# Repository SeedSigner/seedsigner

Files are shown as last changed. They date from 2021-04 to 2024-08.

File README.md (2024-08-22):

# Build an offline, airgapped Bitcoin signing device for less than $50!

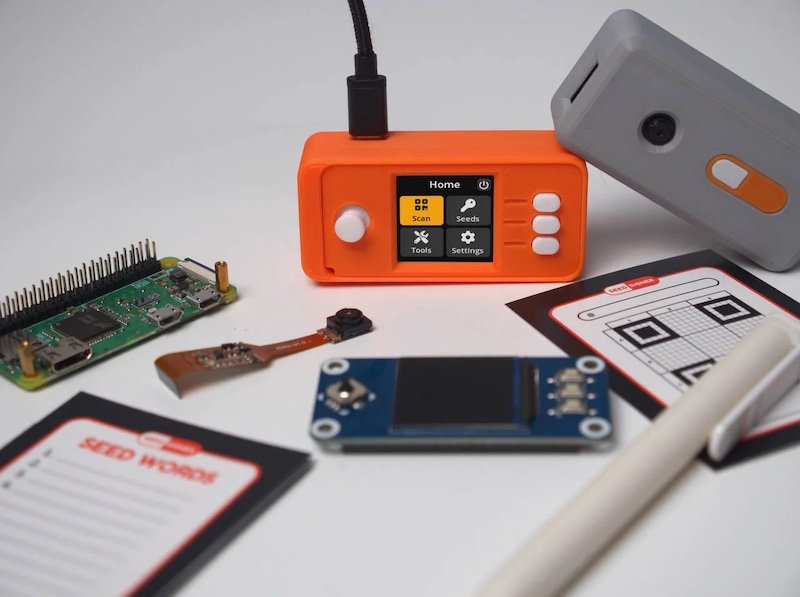
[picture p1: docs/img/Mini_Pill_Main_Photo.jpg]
Image of SeedSigners in Mini Pill Enclosures


---------------

* [Project Summary](#project-summary)
* [Shopping List](#shopping-list)
* [Software Installation](#software-installation)
  * [Verifying the Software](#verifying-the-software)
* [Enclosure Designs](#enclosure-designs)
* [SeedQR Printable Templates](#seedqr-printable-templates)
* [Build from Source](#build-from-source)
* [Developer Local Build Instructions](#developer-local-build-instructions)

---------------

# Project Summary




The goal of SeedSigner is to lower the cost and complexity of Bitcoin multi-signature wallet use. To accomplish this goal, SeedSigner offers anyone the opportunity to build a verifiably air-gapped, stateless Bitcoin signing device using inexpensive, publicly available hardware components (usually < $50). SeedSigner helps users save with Bitcoin by assisting with trustless private key generation and multisignature (aka "multisig") wallet setup, and helps users transact with Bitcoin via a secure, air-gapped QR-exchange signing model.

Additional information about the project can be found at [SeedSigner.com](https://seedsigner.com).

You can follow [@SeedSigner](https://twitter.com/SeedSigner) on Twitter for the latest project news and developments.

If you have specific questions about the project, our [Telegram Group](https://t.me/joinchat/GHNuc_nhNQjLPWsS) is a great place to ask them.

### Feature Highlights:
* Calculate the final word (aka checksum) of a 12- or 24-word BIP39 seed phrase
* Create a 24-word BIP39 seed phrase with 99 dice rolls or a 12-word with 50 rolls [(Verifying dice seed generation)](docs/dice_verification.md)
* Create a 12- or 24-word BIP39 seed phrase via image entropy from the onboard camera 
* Temporarily stores seeds in memory while the device is powered; all memory is wiped when power is removed
* SD card removable after boot to ensure no secret data can be written to it
* Guided interface to manually transcribe a seed to the SeedQR format for instant seed loading [(demo video here)](https://youtu.be/c1-PqTNx1vc)
* BIP39 passphrase (aka "word 25") support
* Native Segwit Multisig XPUB generation
* PSBT-compliant; scan and parse transaction data from animated QR codes
* Sign transactions & transfer XPUB data using animated QR codes [(demo video here)](https://youtu.be/LPqvdQ2gSzs)
* Live preview during image entropy seed generation and QR scanning UX
* Optimized seed word entry interface
* Support for Bitcoin Mainnet & Testnet
* Support for custom user-defined derivation paths
* Support for loading Electrum Segwit seed phrases with feature limitations: [Electrum support info](docs/electrum.md)
* On-demand receive address verification
* Address Explorer for single sig and multisig wallets
* User-configurable QR code display density
* Responsive, event-driven user interface

### Considerations:
* Built for compatibility with Specter Desktop, Sparrow, and BlueWallet Vaults
* Device takes up to 60 seconds to boot before menu appears (be patient!)
* Always test your setup before transferring larger amounts of bitcoin (try Testnet first!)
* Taproot not quite yet supported
* Slightly rotating the screen clockwise or counter-clockwise should resolve lighting/glare issues
* If you think SeedSigner adds value to the Bitcoin ecosystem, please help us spread the word! (tweets, pics, videos, etc.)

### Planned Upcoming Improvements / Functionality:
* Multi-language support
* Significantly faster boot time
* Reproducible builds
* Port to MicroPython to broaden the range of compatible hardware to include low-cost microcontrollers
* Other optimizations based on user feedback!

---------------

# Shopping List

To build a SeedSigner, you will need:

* Raspberry Pi Zero (preferably version 1.3 with no WiFi/Bluetooth capability, but any Raspberry Pi 2/3/4 or Zero model will work, Raspberry Pi 1 devices will require a hardware modification to the Waveshare LCD Hat, as per the [instructions here](./docs/legacy_hardware.md))
* Waveshare 1.3" 240x240 pxl LCD (correct pixel count is important, more info at https://www.waveshare.com/wiki/1.3inch_LCD_HAT)
* Pi Zero-compatible camera (tested to work with the Aokin / AuviPal 5MP 1080p with OV5647 Sensor)

Notes:
* You will need to solder the 40 GPIO pins (20 pins per row) to the Raspberry Pi Zero board. If you don't want to solder, purchase "GPIO Hammer Headers" for a solderless experience.
* Other cameras with the above sensor module should work, but may not fit in the Orange Pill enclosure
* Choose the Waveshare screen carefully; make sure to purchase the model that has a resolution of 240x240 pixels

---------------

# Software Installation

## A Special Note On Minimizing Trust
As is the nature of pre-packaged software downloads, downloading and using the prepared SeedSigner release images means implicitly placing trust in the people preparing those images; in our project the released images are prepared and signed by the eponymous creator of the project, SeedSigner "the person". That individual is additionally the only person in possession of the PGP keys that are used to sign the release images.

Starting with v0.7.0, the images distributed via GitHub are reproducible. This means you and others can verify the released images are byte-for-byte the same when built from source. You can contribute to this project by building from source and sharing the hash of the final images.

Instructions to build a SeedSigner OS image (using precisely the same process that is used to create the prepared release images) have been made available. We have put a lot of thought and work into making these instructions easy to understand and follow, even for less technical users. These instructions can be found [here](https://github.com/SeedSigner/seedsigner-os/blob/main/docs/building.md).

## Downloading the Software

Download the current Version (0.8.0) software image that is compatible with your  Raspberry Pi Hardware. The Pi Zero 1.3 is the most common and recommended board.
| Board | Download Image Link/Name |
| --- | --- |
|**[Raspberry Pi Zero 1.3](https://www.raspberrypi.com/products/raspberry-pi-zero/)** |[`seedsigner_os.0.8.0.pi0.img`](https://github.com/SeedSigner/seedsigner/releases/download/0.8.0/seedsigner_os.0.8.0.pi0.img) |
|[Raspberry Pi Zero W](https://www.raspberrypi.com/products/raspberry-pi-zero-w/) |[`seedsigner_os.0.8.0.pi0.img`](https://github.com/SeedSigner/seedsigner/releases/download/0.8.0/seedsigner_os.0.8.0.pi0.img) |
|[Raspberry Pi Zero 2 W](https://www.raspberrypi.com/products/raspberry-pi-zero-2-w/)  |[`seedsigner_os.0.8.0.pi02w.img`](https://github.com/SeedSigner/seedsigner/releases/download/0.8.0/seedsigner_os.0.8.0.pi02w.img) |
|[Raspberry Pi 1 Model B/B+](https://www.raspberrypi.com/products/raspberry-pi-1-model-b-plus/) |[`seedsigner_os.0.8.0.pi0.img`](https://github.com/SeedSigner/seedsigner/releases/download/0.8.0/seedsigner_os.0.8.0.pi0.img) |
|[Raspberry Pi 2 Model B](https://www.raspberrypi.com/products/raspberry-pi-2-model-b/) |[`seedsigner_os.0.8.0.pi2.img`](https://github.com/SeedSigner/seedsigner/releases/download/0.8.0/seedsigner_os.0.8.0.pi2.img) |
|[Raspberry Pi 3 Model B](https://www.raspberrypi.com/products/raspberry-pi-3-model-b/) |[`seedsigner_os.0.8.0.pi02w.img`](https://github.com/SeedSigner/seedsigner/releases/download/0.8.0/seedsigner_os.0.8.0.pi02w.img) |
|[Raspberry Pi 4 Model B](https://www.raspberrypi.com/products/raspberry-pi-4-model-b/) |[`seedsigner_os.0.8.0.pi4.img`](https://github.com/SeedSigner/seedsigner/releases/download/0.8.0/seedsigner_os.0.8.0.pi4.img) |
|[Raspberry Pi 400](https://www.raspberrypi.com/products/raspberry-pi-400-unit/) |[`seedsigner_os.0.8.0.pi4.img`](https://github.com/SeedSigner/seedsigner/releases/download/0.8.0/seedsigner_os.0.8.0.pi4.img) |

Note: If you have physically removed the WiFi component from your board, you will still use the image file of the original(un-modified) hardware. (Our files are compiled/based on the *processor* architecture). Although it is better to spend a few minutes upfront to determine which specific Pi hardware/model you have, if you are still unsure which hardware you have, you can try using the pi0.img file. Making an incorrect choice here will not ruin your board, because this is software, not firmware. 

**also download** these 2 signature verification files to the same folder  
[The Plaintext manifest file](https://github.com/SeedSigner/seedsigner/releases/download/0.8.0/seedsigner.0.8.0.sha256.txt)  
[The Signature of the manifest file](https://github.com/SeedSigner/seedsigner/releases/download/0.8.0/seedsigner.0.8.0.sha256.txt.sig)

Users familiar with older versions of the SeedSigner software might be surprised with how fast their software downloads now are, because since version 0.6.0 the software image files are now 100x smaller! Each image file is now under 42 Megabytes so your downloads and verifications will be very quick now (and might even seem *too* quick)!  

Once the files have all finished downloading, follow the steps below to verify the download before continuing on to write the software onto a MicroSD card. Next, insert the MicroSD into your assembled hardware and connect the USB power. Allow about 45 seconds for our logo to appear, and then you can begin using your SeedSigner! 

[Our previous software versions are available here](https://github.com/SeedSigner/seedsigner/releases). Choose a specific version and then expand the *Assets* sub-heading to display the .img file binary and also the 2 associated signature files. **Note:** The prior version files will have lower numbers than the scripts and examples provided in this document, but the naming format will be the same, so you can edit them as required for signature verification etc.   

## Verifying that the downloaded files are authentic (optional but highly recommended!)

You can quickly verify that the software you just downloaded is both authentic and unaltered, by following these instructions.
We assume you are running the commands from a computer where both [GPG](https://gnupg.org/download/index.html) and [shasum](https://command-not-found.com/shasum) are already installed, and that you also know [how to navigate on a terminal](https://terminalcheatsheet.com/guides/navigate-terminal). 

> You must run the following verification before opening or mounting the .img file.
> Some operating systems modify the file on mount causing verification to fail.

### Step 1. Verify that the signature (.sig) file is genuine:

Run GPG's *fetch-keys* command to import the SeedSigner projects public key from the popular online keyserver called *Keybase.io*, into your computers *keychain*. 

```
gpg --fetch-keys https://keybase.io/seedsigner/pgp_keys.asc
```
The result should confirm that 1 key was *either* imported or updated. *Ignore* any key ID's or email addresses shown.

SS - Fetchkeys-Keybase PubKey import with Fingerprint shown (New import or update of the key)v3-100pct  

Next, you will run the *verify* command on the signature (.sig) file. (*Verify* must be run from inside the same folder that you downloaded the files into earlier. The `*`'s in this command will auto-fill the version from your current folder, so it should be copied and pasted as-is.)   
```
gpg --verify seedsigner.0.7.*.sha256.txt.sig
```

When the verify command completes successfully, it should display output like this:
<BR>
SS - Verify Command - GPG on Linux - Masked_v4-100pct  
The result must display "**Good signature**".  Ignore any email addresses - *only*  matching Key fingerprints count here. Stop immediately if it displays "*Bad signature*"!
<BR> 

On the *last* output line, look at your *rightmost* 16 characters (the 4 blocks of 4).  
**Crucially, we must now check WHO that Primary key fingerprint /ID belongs to.** We will start by looking at Keybase.io to see if it is the *SeedSigner project* 's public key or not.

<details><summary> About the warning message:</summary>
<p>  Since you are about to match the outputted fingerprint/ID against the proofs at Keybase.io/SeedSigner, and thereby confirm who the pubkey really belongs to-, you can safely ignore this warning message:

```
> WARNING: This key is not certified with a trusted signature!  
> There is no indication that the signature belongs to the owner.
 ```
</p>
</details>
<br>

<details><summary> More about how the verify command works:</summary>
<p>  
The verify command will attempt to decrypt the signature file (sha256.sig) by trying each public key already imported into your computer. If the public key we just imported (via fetch-keys), manages to: (a) successfully decrypt the .sig file , and (b), that result matches exactly to the clear-text equivalent (.sha256) of the .sig file, then its "a good signature"!   

Crucially, we must still manually check who *exactly* owns the Key ID which gave us that "Good signature". Thats what the warning message means- Who does the matching key really belong to? We will start by looking at keybase.io to see if it is "The SeedSigner project"'s public Key or not. 
Note that it is the file hashes of .sig and .sha256 that *verify* compares, not their raw contents.

</p>
</details>
<br>

Now to determine ***who*** the Public key ID belongs to: Goto [Keybase.io/SeedSigner](https://keybase.io/seedsigner)  
<BR>
SS - Keybase Website PubKey visual matching1_Cropped-80pct

**You must now *manually* compare: The 16 character fingerprint ID (as circled in red above) to, those *rightmost* 16 characters from your *verify* command.** 

**If they match exactly, then you have successfully confirmed that your .sig file is authentically from the SeedSigner Project!**
<BR>

<details><summary>Learn more about how keybase.io helps you check that someone (online) is who they say they are:</summary>
<p>
Keybase.io allows you to independently verify that the public key saved on Keybase.io, is both authentic and that it belongs to the organization it claims to represent.  
 Keybase has already checked the three pubkey file locations  cryptographically when they were saved there. You can further verify the key publications if you would like:  
 
 - *via Keybase*: By clicking on any of the three blue badges to see that the "proof" was published at that location. (The blue badge marked as tweet, is in the most human-readable form and it is also a bi-directional link on Twitter)    
or, 
 - *without keybase (out-of-band)*: By using these 3 links directly: [Twitter](https://twitter.com/SeedSigner/status/1530555252373704707), [Github](https://gist.github.com/SeedSigner/5936fa1219b07e28a3672385b605b5d2) and [SeedSigner.com](https://seedsigner.com/keybase.txt). This method can be used if you would like to make an even deeper, independent inspection without relying on Keybase at all, or if the Keybase.io site is no longer valid or it is removed entirely. 

Once you have used one of these methods, you will know if the Public Key stored on Keybase, is genuinely from the SeedSinger Project or not.
</p>
</details>
<br>

If the two ID's do *not* match, then you must stop here immediately. Do not continue. Contact us for assistance in the Telegram group address above.

<br>

### Step 2. Verifying that the *software images/binaries* are genuine

Now that you have confirmed that you do have the real SeedSigner Project's Public Key (ie the 16 characters match) - you can return to your terminal window. Running  the *shasum* command, is the final verification step and will confirm (via file hashing) that the software code/image files, were also not altered since publication, or even during your download process.  
(Prior to version 0.6.0  , your verify command will check the .zip file which contains the binary files.)

 **On Linux or OSX:** Run this command
```
shasum -a 256 --ignore-missing --check seedsigner.0.7.*.sha256.txt  
```

**On Windows (inside Powershell):** Run this command
```
CertUtil -hashfile  seedsigner_os.0.8.0.Insert_Your_Pi_Models_binary_here_For_Example_pi02w.img SHA256 
```
On Windows, you must then manually compare the resulting file hash value to the corresponding hash value shown inside the .SHA256 cleartext file.
 <BR>

Wait up to 30 seconds for the command to complete, and it should display:
```
seedsigner_os.0.7.x.[Your_Pi_Model_For_Example:pi02w].img: OK
```
**If you receive the "OK" message** for your **seedsigner_os.0.7.x.[Your_Pi_Model_For_Example:pi02w].img file**, as shown above, then your verification is fully complete!  
**All of your downloaded files have now been confirmed as both authentic and unaltered!** You can proceed to create/write your MicroSD card😄😄 !!     

If your file result shows "FAILED", then you must stop here immediately. Do not continue. Contact us for assistance at  the Telegram group address above.

<BR>

Please recognize that this process can only validate the software to the extent that the entity that first published the key is an honest actor, and their private key is not compromised or somehow being used by a malicious actor.
<BR>
<BR>

## Writing the software onto your MicroSD card

To write the SeedSigner software onto your MicroSD card, there are a few options available:   
| Application | Description | Platform and official Source |
|---|---|---|
| Balena Etcher | The application is called Etcher, and the company that wrote it is called Balena.  Hence *Etcher by Balena* or *Balena Etcher* | [Available for Windows, Mac and Linux](https://www.balena.io/etcher#download-etcher) |
| Raspberry Pi Imager | Produced by the Raspberry Pi organization. | [Available for Windows, Mac and Linux](https://www.raspberrypi.com/software/) |
| DD Command Line Utility  | Built-in to Linux and MacOS, the DD (Data Duplicator) is a tool for advanced users.  If not used carefully it can accidentally format the incorrect disk! | Built-in to Linux and MacOS |

Be sure to download the software from the genuine publisher.  
Either of the Etcher or Pi Imager software is recommended.  Some SeedSigner users have reported a better experience with one or the other. So, if the one application doesn’t work well for your particular machine, then please try the other one. 
<BR>
### **General Considerations:** 
The writing and verify steps are very quick from version 0.6.0 upwards, so please pay close attention to your screen. 
Make sure to set any write-protection physical slider on the MicroSD Card Adapter to UN-locked.  
You also don’t need to pre-format the MicroSD beforehand.  You *dont* need to unzip any .zip file beforehand.
Current Etcher and Pi Imager software will perform a verify action (by default) to make sure the card was written successfully! Watching for that verify step to complete successfully, can save you a lot of headaches if you later need to troubleshoot issues where your SeedSigner device doesn’t boot up at power on.   
Writing the MicroSd card is also known as flashing.  
It will overwrite everything on the MicroSD card.  
If the one application fails for you, then please try again using our other recommended application.  
Advanced users may want to try the Linux/MacOS *DD* command instead of using Etcher or Pi Imager, however, a reminder is given that DD can overwrite the wrong disk if you are not careful !
#### **Specific considerations for Windows users:**
Use the Pi imager software as your first choice on Windows. Windows can sometimes flag the writing of a MicroSD as risky behaviour and hence it may prevent this activity. If this happens, your writing/flashing will fail, hang or wont even begin, in which case you should to try to run the Etcher/Pi-Imager app "As administrator", (right-click and choose that option). It can also be blocked by windows security in some cases, so If you have the (non-default) *Controlled Folder Access* option set to active, try turning that *off* temporarily. 

---------------

# Enclosure Designs

### Open Pill

The Open Pill enclosure design is all about quick, simple and inexpensive depoloyment of a SeedSigner device. The design does not require any additional hardware and can be printed using a standard FDM 3D printer in about 2 hours, no supports necessary. A video demonstrating the assembly process can be found [here](https://youtu.be/gXPFJygZobEa). To access the design file and printable model, click [here](https://github.com/SeedSigner/seedsigner/tree/main/enclosures/open_pill).

### Orange Pill

The Orange Pill enclosure design offers a more finished look that includes button covers and a joystick topper. You'll also need the following additional hardware to assemble it:

* 4 x F-F M2.5 spacers, 10mm length
* 4 x M2.5 pan head screws, 6mm length
* 4 x M2.5 pan head screws, 12mm length

The upper and lower portions of the enclosure can be printed using a standard FDM 3D printer, no supports necessary. The buttons and joystick nub should ideally be produced with a SLA/resin printer. An overview of the entire assembly process can be found [here](https://youtu.be/aIIc2DiZYcI). To access the design files and printable models, click [here](https://github.com/SeedSigner/seedsigner/tree/main/enclosures/orange_pill).

### Community Designs

* [Lil Pill](https://cults3d.com/en/3d-model/gadget/lil-pill-seedsigner-case) by @_CyberNomad
* [OrangeSurf Case](https://github.com/orangesurf/orangesurf-seedsigner-case) by @OrangeSurfBTC
* [PS4 SeedSigner](https://www.thingiverse.com/thing:5363525) by @Silexperience
* [OpenPill Faceplate](https://www.printables.com/en/model/179924-seedsigner-open-pill-cover-plates-digital-cross-jo) by @Revetuzo 
* [Waveshare CoverPlate](https://cults3d.com/en/3d-model/various/seedsigner-coverplate-for-waveshare-1-3-inch-lcd-hat-with-240x240-pixel-display) by @Adathome1

---------------

# SeedQR Printable Templates
You can use SeedSigner to export your seed to a hand-transcribed SeedQR format that enables you to instantly load your seed back into SeedSigner.

[More information about SeedQRs](docs/seed_qr/README.md)

<table align="center">
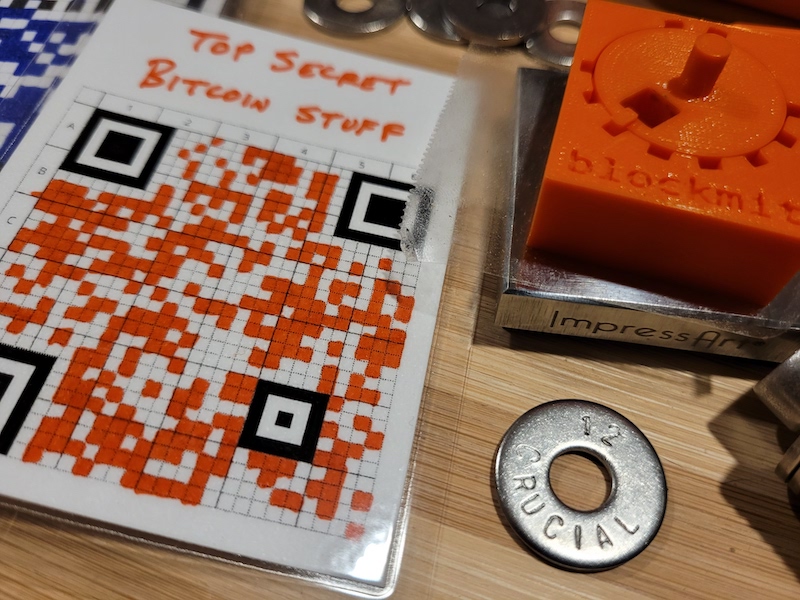
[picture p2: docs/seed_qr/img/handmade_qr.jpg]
    <tr><td></td></tr>
</table>

Standard SeedQR templates:
* [12-word SeedQR template dots (25x25)](docs/seed_qr/printable_templates/dots_25x25.pdf)
* [24-word SeedQR template dots (29x29)](docs/seed_qr/printable_templates/dots_29x29.pdf)
* [12-word SeedQR template grid (25x25)](docs/seed_qr/printable_templates/grid_25x25.pdf)
* [24-word SeedQR template grid (29x29)](docs/seed_qr/printable_templates/grid_29x29.pdf)
* [Baseball card template: 24-word SeedQR (29x29)](docs/seed_qr/printable_templates/trading_card_29x29_w24words.pdf)

CompactSeedQR templates:
* [12-word CompactSeedQR template dots (21x21)](docs/seed_qr/printable_templates/dots_21x21.pdf)
* [24-word CompactSeedQR template dots (25x25)](docs/seed_qr/printable_templates/dots_25x25.pdf)
* [12-word CompactSeedQR template grid (21x21)](docs/seed_qr/printable_templates/grid_21x21.pdf)
* [24-word CompactSeedQR template grid (25x25)](docs/seed_qr/printable_templates/grid_25x25.pdf)
* [Baseball card template: 12-word Compact SeedQR (21x21)](docs/seed_qr/printable_templates/trading_card_21x21_w12words.pdf)
* [Baseball card template: 24-word Compact SeedQR (25x25)](docs/seed_qr/printable_templates/trading_card_25x25_w24words.pdf)

2-sided SeedQR templates - 8 per sheet
Printing settings - (2-sided)("flip on long edge")("Actual Size")
If printing on cardstock, adjust your printer settings via its control panel

A4 templates(210mm * 297mm):
* [21x21 - stores 12-word seeds ONLY in CompactSeedQR format ONLY](docs/seed_qr/printable_templates/21x21_A4_trading_card_2sided.pdf)
* [25x25 - stores 12-word or 24 word seeds depending on SeedQR format](docs/seed_qr/printable_templates/25x25_A4_trading_card_2sided.pdf)
* [29x29 - stores 24-word seeds ONLY as plaintext SeedQR format ONLY](docs/seed_qr/printable_templates/29x29_A4_trading_card_2sided.pdf)

Letter templates(8.5in * 11in):
* [21x21 - stores 12-word seeds ONLY in CompactSeedQR format ONLY](docs/seed_qr/printable_templates/21x21_letter_trading_card_2sided.pdf)
* [25x25 - stores 12-word or 24 word seeds depending on format](docs/seed_qr/printable_templates/25x25_letter_trading_card_2sided.pdf)
* [29x29 - stores 24-word seeds ONLY as plaintext SeedQR format ONLY](docs/seed_qr/printable_templates/29x29_letter_trading_card_2sided.pdf)
---------------

# Build from Source
See the [SeedSigner OS repo](https://github.com/SeedSigner/seedsigner-os/) for instructions.

# Developer Local Build Instructions
Raspberry Pi OS is commonly used for development. See the [Raspberry Pi OS Build Instructions](docs/raspberry_pi_os_build_instructions.md)

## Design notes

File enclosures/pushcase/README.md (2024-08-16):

# The Push Case

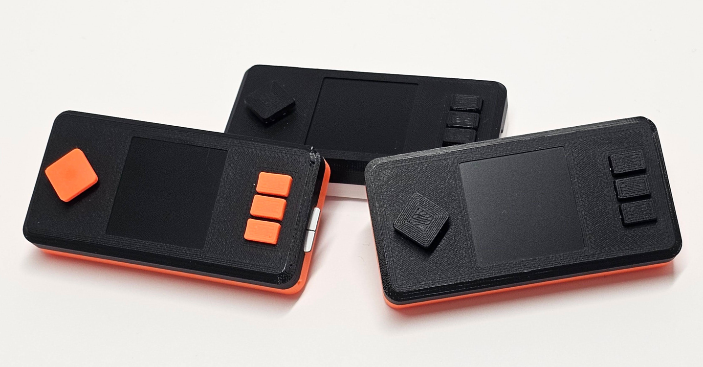
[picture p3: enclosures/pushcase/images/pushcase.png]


Designer: @kayth21

## Motivation

The motivation for this design was to get a thin, screwless and good looking enclosure with minimal secondary hardware requirements.

## Characterisics

- No screws needed
- Soldering required
- Mini-HDMI port not accessible
- Removeable memory card accessible
- Data-enabled USB port not accessible

## Hardware restrictions

- Raspberry Pi Zero without pre-installed GPIO pins required.
- Raspberry Pi Camera in smaller "Zero" style version required.

## Secondary hardware requirements

- 40x pins (6mm / 0.04in)
- Soldering iron and solder

## 3D prints and screwless design

Please note that the prints must be accurate in order to fit tightly without screws and for the buttons to perform smoothly. The prints are well tested with a Prusa MK3s (.3mf files attached), Prusament PLA and hardware components from early 2024. With this setup, the enclosure holds strongly together, but can still be opened again with a little effort (although this is not recommended, as it may not hold together as tightly afterwards). Other printers or newer or older hardware may produce results that do not fit and in worst case damage the hardware.

## Known issues

- Bambu Studio Slicer: There is a strange problem when slicing the buttons. A few layers are missing. As a workaround you can use another slicer, e.g. the Prusa Slicer.

## Assembly

### 1. Get all the parts

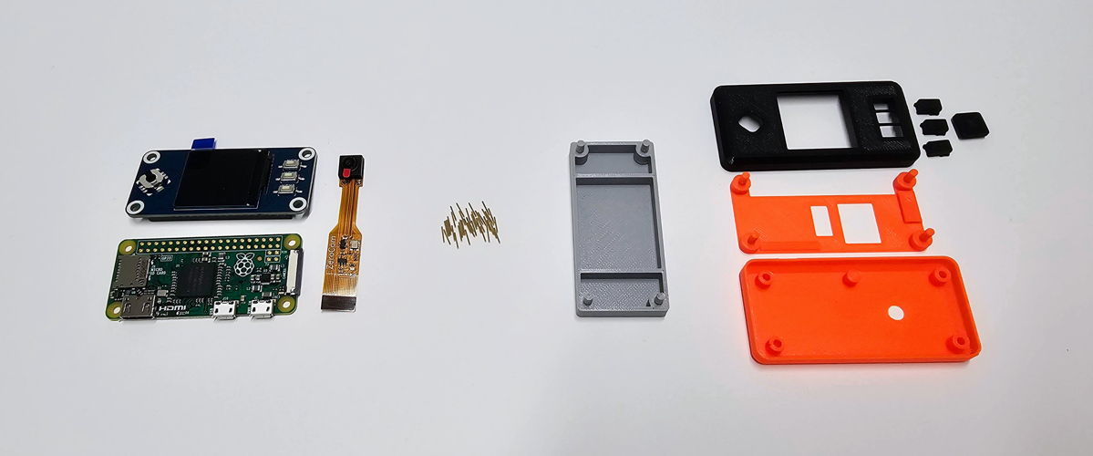
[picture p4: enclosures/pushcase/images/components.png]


- Raspberry Pi Zero v.1.3
- Waveshare LCD Display (240x240)
- Camera for Raspberry Pi Zero
- 40 pins (6mm / 0.04in, cut them to size if you can only find larger ones)
- Soldering iron and solder (not on picture)
- Soldering support (3D print)
- Top, middle, back and buttons (3D prints)
- Tweezers (if available - not on picture)

### 2. Place the display and the Raspberry Pi on the soldering support

<p float="left">
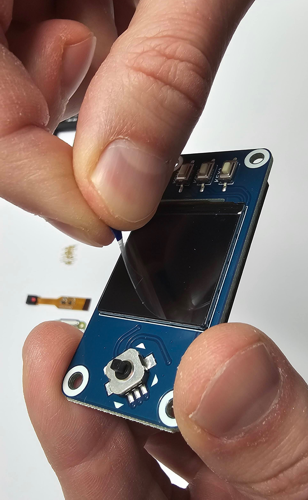
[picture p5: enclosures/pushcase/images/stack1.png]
	
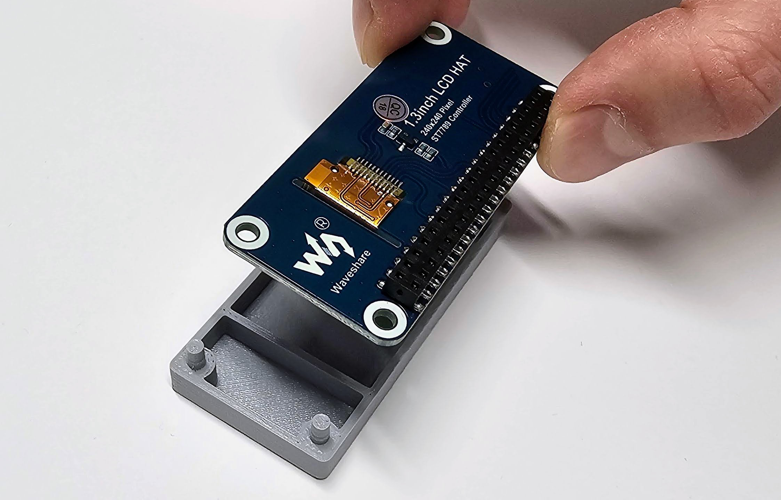
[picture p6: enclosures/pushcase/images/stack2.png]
	
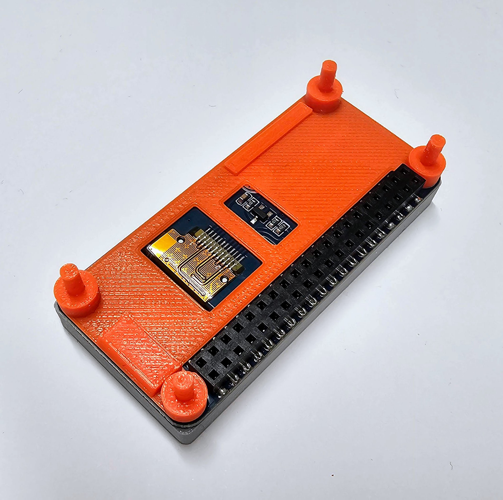
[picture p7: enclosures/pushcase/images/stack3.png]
	
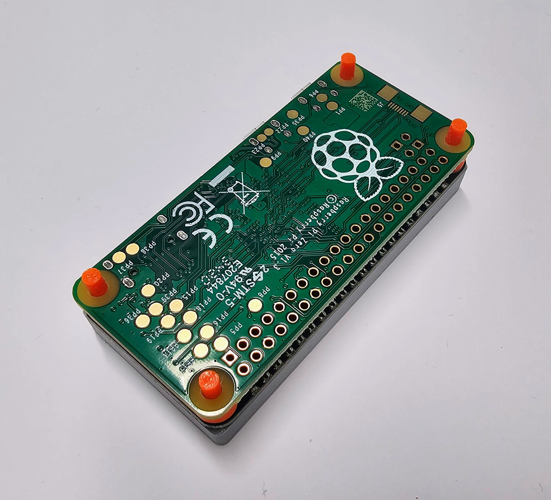
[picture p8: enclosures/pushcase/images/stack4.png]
	
</p>

- Remove the screen protection of the LCD display.
- Place the display face down on the soldering support.
- Place the middle support on the display.
- Place the Raspberry Pi face down on the middle support.

### 3. Solder the pins

<p float="left">
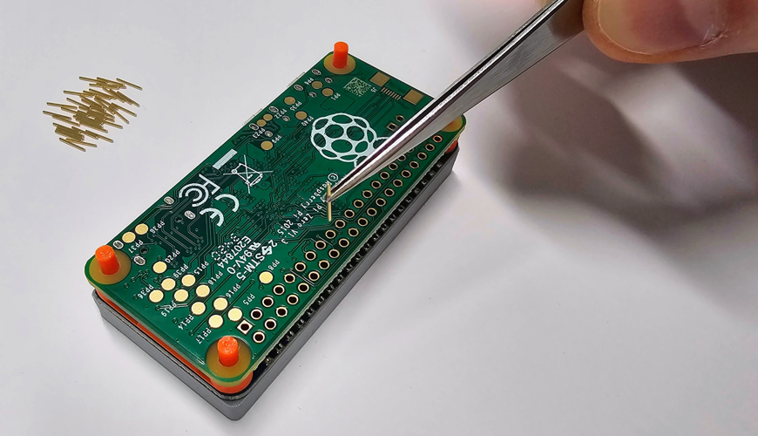
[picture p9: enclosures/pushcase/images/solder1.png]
	
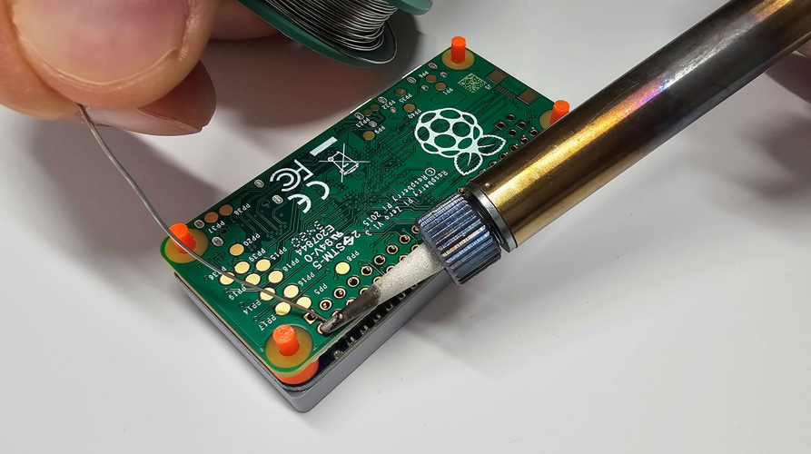
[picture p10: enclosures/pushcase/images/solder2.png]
	
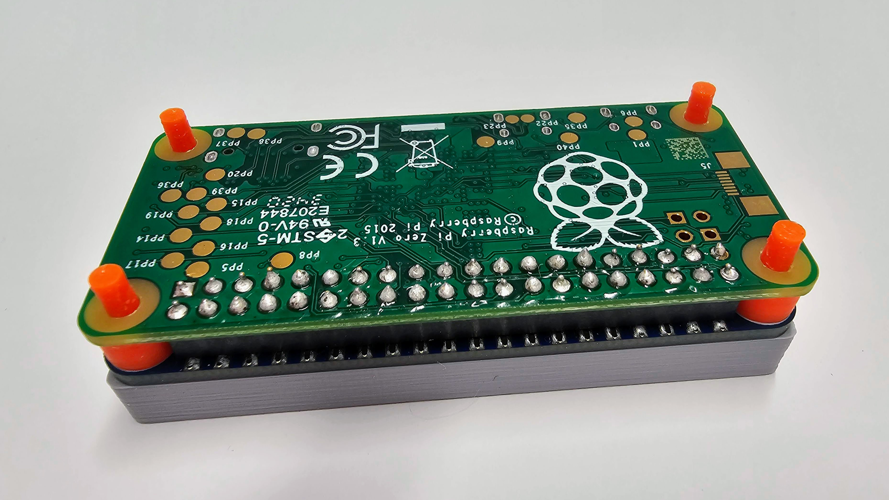
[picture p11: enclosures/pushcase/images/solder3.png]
	
</p>

- Insert the 40 pins with the help of tweezers and push them all the way down.
- Solder the pins (please pay attention not to melt the orange support elements!).
- Optional: Pull out the Raspberry Pi to check that the pins are holding properly after soldering. 

### 4. Attach camera

<p float="left">
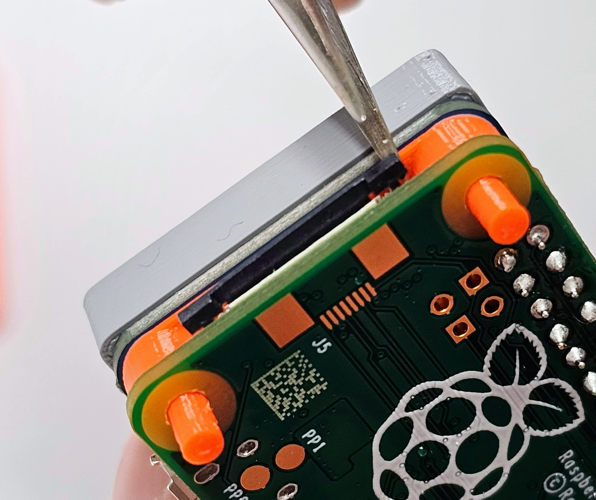
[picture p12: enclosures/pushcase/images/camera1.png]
	
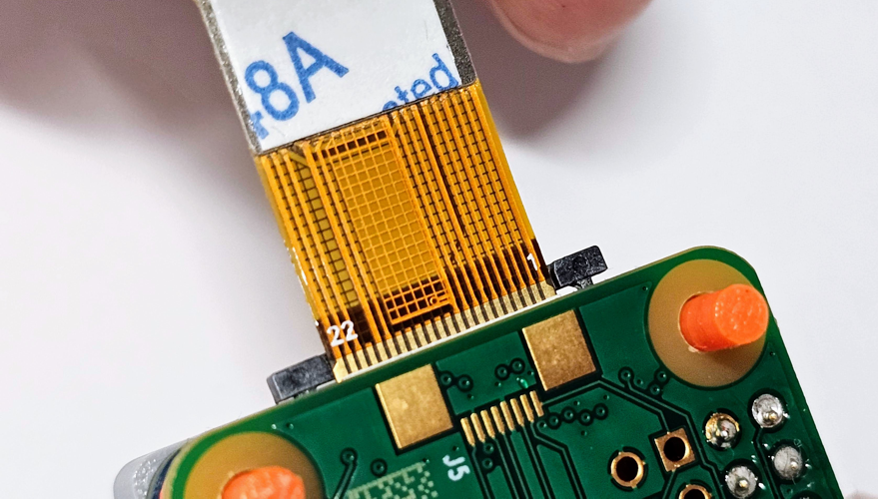
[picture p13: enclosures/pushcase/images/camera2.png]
	
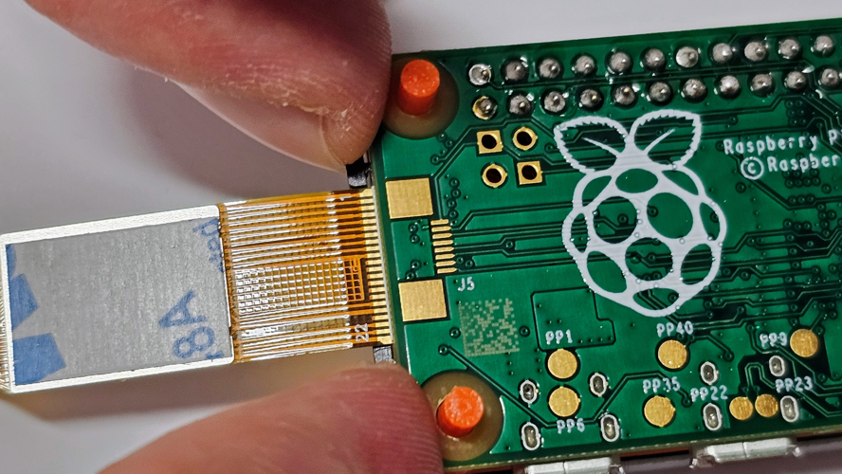
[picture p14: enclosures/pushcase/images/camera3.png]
	
</p>

- Carefully pull out the camera cable mount (ideally with the support of a tool).
- Plug in the camera cable (it doesn't go very deep).
- Close the camera cable mount to fix the cable.

### 5. Stick on the back part

<p float="left">
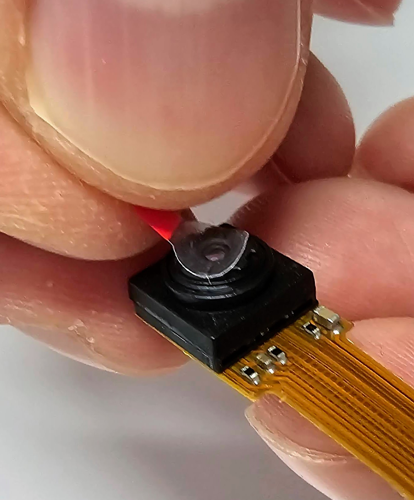
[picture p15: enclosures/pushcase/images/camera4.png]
	
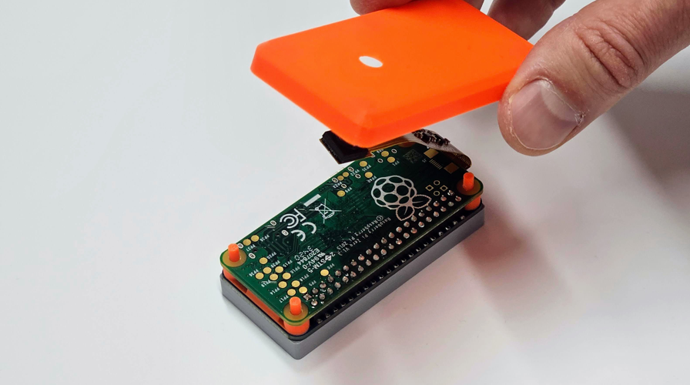
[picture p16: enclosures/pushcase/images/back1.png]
	
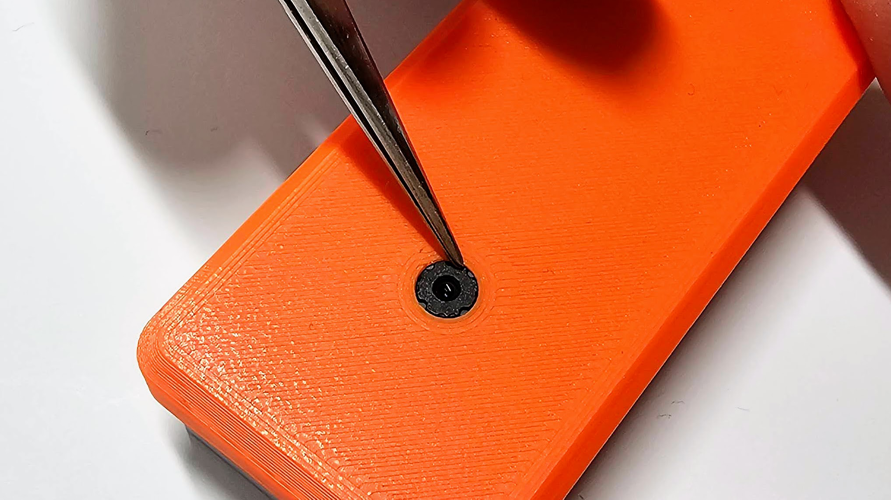
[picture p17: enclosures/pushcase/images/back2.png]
	
</p>

- Remove the camera protection.
- Bend the camera cable into position (do not use the adhesive tape!).
- Place the back part on the signer, but do not push it in completely yet.
- Align the camera precisely with the help of a tool.
- Push the back part in completely (the camera should fit perfectly and have no more play).

### 6. Stick on the front part

<p float="left">
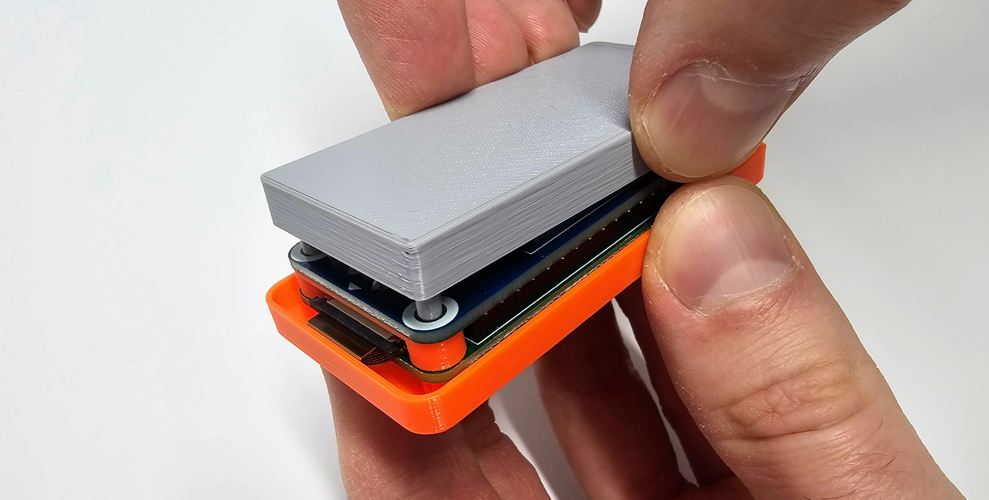
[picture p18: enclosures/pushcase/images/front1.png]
	
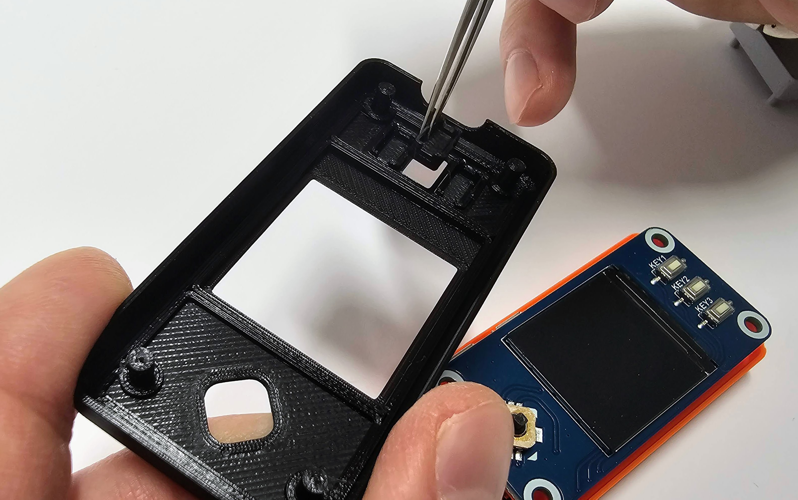
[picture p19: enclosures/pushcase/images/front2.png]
	
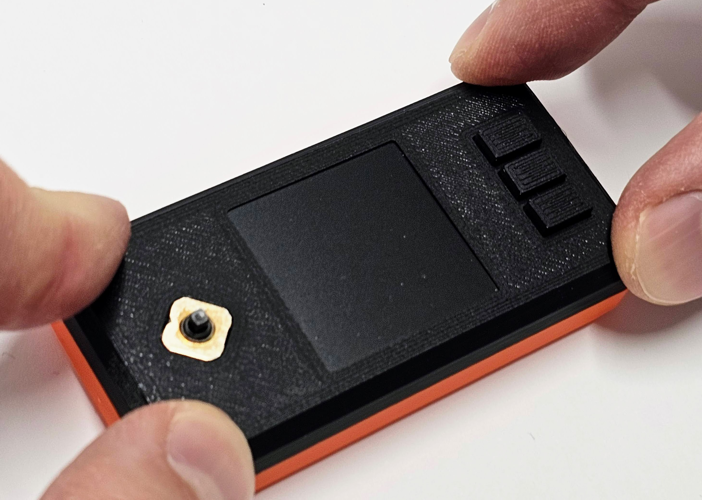
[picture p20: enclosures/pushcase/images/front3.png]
	
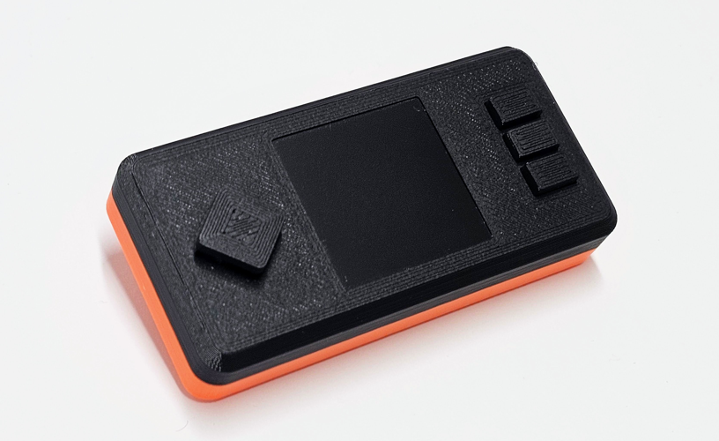
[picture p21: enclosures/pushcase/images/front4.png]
	
</p>

- Remove the soldering support.
- Insert the 3 buttons into the front. 
- Press the front completely into the signer (hold the device upside down so that the buttons do not fall out).
- Plug in the thumbstick.

### 7. Flash a MicroSD card

- Please follow the documentation on [SeedSigner.com](https://seedsigner.com).

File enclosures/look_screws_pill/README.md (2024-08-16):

Motivation for this design: Faceplate screws could look cool. Judge for yourself!

It's work that's built on top of giants (@gobrrrme and @blackcoffee).

The main chassis has the properties of a battle-tested enclosure called SimplePill by @blackcoffee and connected buttons are a slightly reworked design done by @gobrrrme.

What distinguishes this design are the visible screws on top of the enclosure and a presspad. 

This design requires:
* 4x 10mm M2.5 risers
* 8x 10mm M2.5 screws

The buttons and presspad HAVE to be printed out of TPU filament. The Top and Bottom are best from PLA but PETG will work just as well. The presspad has a slightly smaller cavity for the stubby nub of the waveshare hat. DO NOT PANIC! It's done on purpose to create friction for the pad to hold on the nub.



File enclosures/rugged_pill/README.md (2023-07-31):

## The Rugged Pill Enclosure

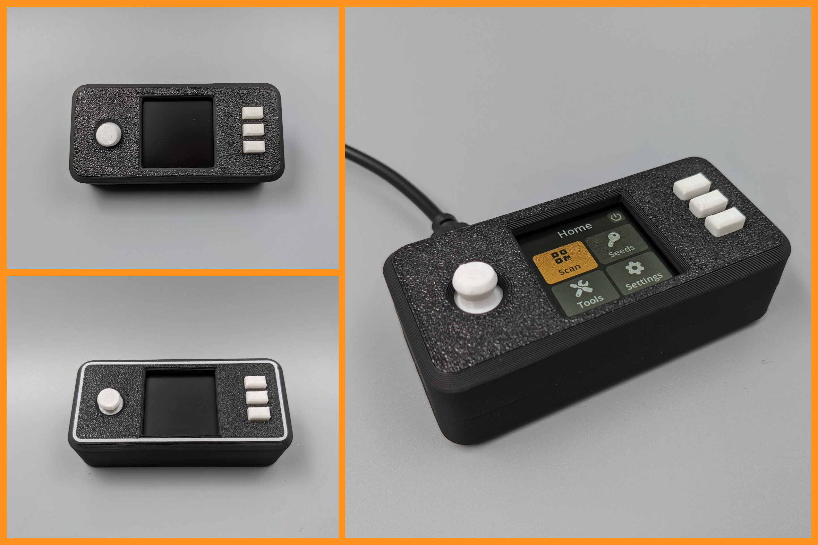
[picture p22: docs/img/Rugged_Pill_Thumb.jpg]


- The Rugged Pill is an enclosure designed for building a SeedSigner without the need for screws or spacers.
- This enclosure requires use of the so called "zerocam", which allows for a more compact form factor.
- The enclosure offers a very comfortable handling experience.
- The included controls can be printed from PLA, but TPU is recommended.
- Recommended shore hardness is 95A, but any TPU will do.
- Separate files are available for single and multicolor printing.
- Top and bottom part snap fit together.
- SD-card removable
- Data port is closed. (Use the separate file labeled 4_SeedHammer)

### File overwiev

#### Single color:
- RuggedPill_Top.stl[^1]
- RuggedPill_Bottom.stl[^1]
- RuggedPillBottom_4SeedHammer.stl[^1]

- RuggedPill_Buttons.stl[^2]
- RuggedPill_Thumbstick.stl[^2]
- Rugged_Pill_Trackball.stl[^2]

#### Multimaterial:
- RuggedPill_Top_MMU.3mf
- RuggedPill_Bottom_MMU.3mf

You only need one set of buttons and a Thumbstick or Trackball, print both since they use minmal material. Test which one you like best and use that.

[^1]: (Recommended Materials: PLA, PETG)
[^2]: (Recommended Materials: TPU)

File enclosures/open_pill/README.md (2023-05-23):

## The Open Pill Enclosure

The "Open Pill" was the second officially released SeedSigner enclosure. Given some of the challenges associated with the "Orange Pill", the Open Pill was designed for quick, inexpensive, and simple deployment. No secondary hardware components are required for assembly and the design consists of a single printed part that can be produced with even basic 3D printers. This simpler design was intended to put the focus back on the project's software, which was improving by leaps and bounds when the enclosure was released.

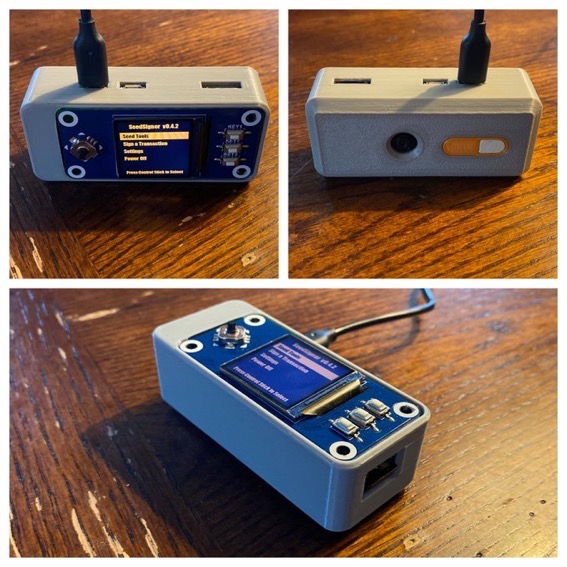
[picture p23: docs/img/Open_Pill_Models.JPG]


### Characterisics:
- Supported Camera? Legacy RPi Camera (w/ gold Pi Zero Cable)
- Supported HAT? Waveshare 240x240 pixel LCD display + controls
- Recommended printing process? FDM
- Recommended printing materials? PLA
- Secondary Hardware Required? No
- Data-enabled USB Port accessible? Yes
- Mini-HDMI port accessible? Yes
- Removeable Memory Card? Yes
- Comfortable controls? No (see note below)

### Assembly Demonstration:
https://www.youtube.com/watch?v=gXPFJygZobE

### Comfortable Controls Optional Upgrade:
The bare joystick on an open pill or open pill mini design can be uncomfortable for some thumbs. Twitter user @Vulcan21com developed a DIY solution to add comfort to the exposed joystick using a M2.5 knurled nut standardized under DIN 466, widely available at many hardware stores. The joystick itself has no threading, but it is possible to screw the M2.5 nut onto the joystick with a bit of precision and patience. While screwing it on for the first time it will cut a light thread into the plastic. Be gentle as to not transfer too much torque into the joystick. The result will look like this:

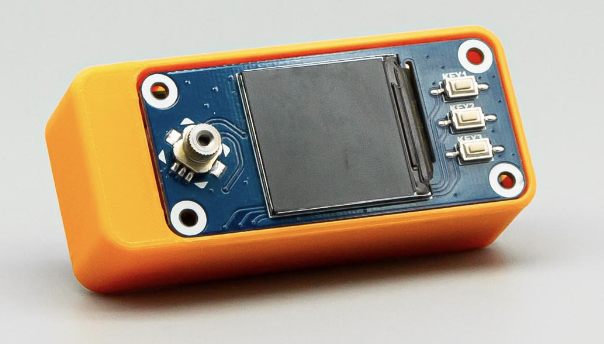
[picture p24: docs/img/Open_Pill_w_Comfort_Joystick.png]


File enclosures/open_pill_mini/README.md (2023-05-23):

## The Open Pill Mini Enclosure

The "Open Pill Mini" is simply a smaller version of the original "Open Pill" that is designed to incorporate a more compact camera specifically designed for the Raspberry Pi Zero -- this enclosure is just about as small as a SeedSigner can conceivably get. It is pictured below, alongside the original Open Pill enclosure.

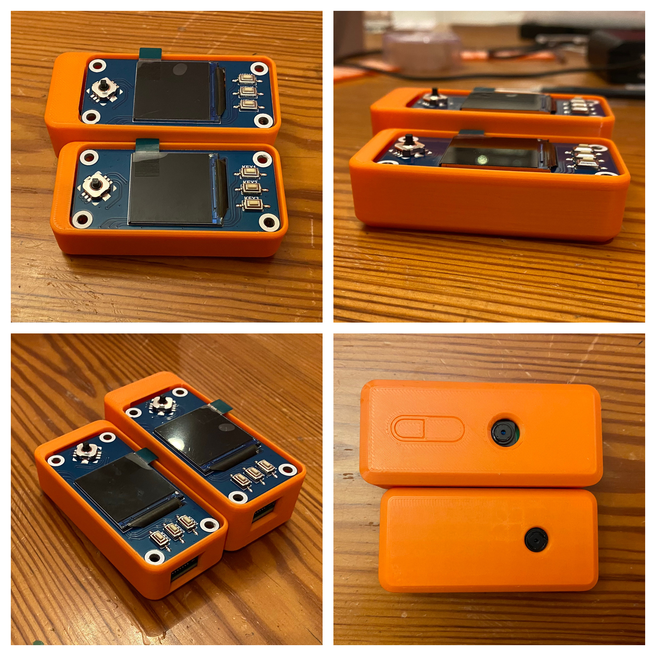
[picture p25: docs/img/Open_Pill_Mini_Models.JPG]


### Characterisics:
- Supported Camera? "ZeroCam" designed specifically for RPi Zero
- Supported HAT? Waveshare 240x240 pixel LCD display + controls
- Recommended printing process? FDM
- Recommended printing materials? PLA
- Secondary Hardware Required? No
- Data-enabled USB Port accessible? Yes
- Mini-HDMI port accessible? Yes
- Removeable Memory Card? Yes
- Comfortable controls? No (see note below)

### Assembly Demonstration:
(assembly is very similar to the original Open Pill assembly, depicted below)
https://www.youtube.com/watch?v=aIIc2DiZYcI

### Comfortable Controls Optional Upgrade:
The bare joystick on an open pill or open pill mini design can be uncomfortable for some thumbs. Twitter user @Vulcan21com developed a DIY solution to add comfort to the exposed joystick using a M2.5 knurled nut standardized under DIN 466, widely available at many hardware stores. The joystick itself has no threading, but it is possible to screw the M2.5 nut onto the joystick with a bit of precision and patience. While screwing it on for the first time it will cut a light thread into the plastic. Be gentle as to not transfer too much torque into the joystick. The result will look like this:


(image displayed is Open Pill, not Open Pill Mini)

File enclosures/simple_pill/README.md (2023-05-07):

## The Simple Pill Enclosure

The "Simple Pill" is a community-contributed design by @blackcoffeebtc. The most significant innovation of this design was the adaptation of a DPAD-stype thumbstick topper for a SeedSigner enclosure, offering a much more comfortable and responsive control experience. The Simple Pill was also the first enclosure to allow for easy access to the device's memory card.

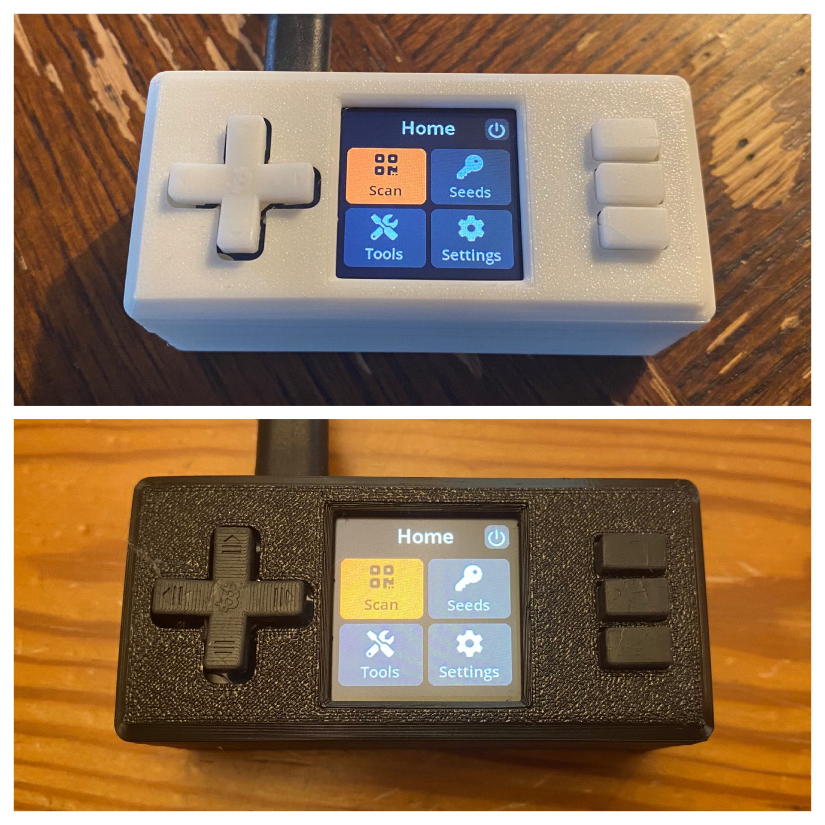
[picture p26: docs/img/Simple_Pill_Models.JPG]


### Characterisics:
- Supported Camera? Legacy RPi Camera (w/ gold Pi Zero Cable)
- Supported HAT? Waveshare 240x240 pixel LCD display + controls
- Recommended printing process? FDM for enclosure, SLA for controls
- Recommended printing materials? PLA for enclosure, resin for controls
- Secondary Hardware Required? Yes
- Data-enabled USB Port accessible? Yes
- Mini-HDMI port accessible? Yes
- Removeable Memory Card? Yes
- Comfortable controls? Yes

### Secondary Hardware Required:
- Four (4): 10mm M2.5 F-F spacers
- Four (4): 6mm M2.5 screws
- Four (4): 12mm M2.5 screws

### Assembly Demonstration:
(assembly is similar to that of the original Orange Pill)
https://www.youtube.com/watch?v=aIIc2DiZYcI

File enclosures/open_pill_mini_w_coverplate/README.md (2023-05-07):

## The Open Pill Mini w/ Coverplate Enclosure

The "Open Pill Mini w/ Coverplate" was designed as an attempt to incorporate the best of the "Orange Pill" and the "Open Pill" enclosures into a single design. It is fully enclosed for improved aesthetics and protection of electronic components, yet is compact and can be manufactured with a simple FDM printer, also not requiring any additional hardware components. A first for this enclosure was preventing access to the SeedSigner's data-enabled USB port as an additional security assurance for users.



### Characterisics:
- Supported Camera? "ZeroCam" designed specifically for RPi Zero
- Supported HAT? Waveshare 240x240 pixel LCD display + controls
- Recommended printing process? FDM for enclosure & controls
- Recommended printing materials? PLA for enclosure, TPU for controls
- Secondary Hardware Required? No
- Data-enabled USB Port accessible? No
- Mini-HDMI port accessible? No
- Removeable Memory Card? Yes
- Comfortable controls? Yes

### Assembly Demonstration:
https://www.youtube.com/watch?v=6-5cDneXoWs

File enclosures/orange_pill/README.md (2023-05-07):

## The Orange Pill Enclosure

The "Orange Pill" was the first SeedSigner enclosure. It's eye-catching design is the enclosure most commonly associated with the SeedSigner project for many. While aesthetically appealing and fun to showcase to others, the thumbstick topper's sub-optimal design, the need for secondary hardware components, and other drawbacks make this enclosure a less desirable choice for every day SeedSigner use.



### Characterisics:
- Supported Camera? Legacy RPi Camera (w/ gold Pi Zero Cable)
- Supported HAT? Waveshare 240x240 pixel LCD display + controls
- Recommended printing process? FDM for enclosure, SLA for controls
- Recommended printing materials? PLA for enclosure, resin for controls
- Secondary Hardware Required? Yes
- Data-enabled USB Port accessible? Yes
- Mini-HDMI port accessible? Yes
- Removeable Memory Card? Requires partial disassembly
- Comfortable controls? Yes (but thumbstick can be clumsy)

### Secondary Hardware Required:
- Four (4): 10mm M2.5 F-F spacers
- Four (4): 6mm M2.5 screws
- Four (4): 12mm M2.5 screws

### Assembly Demonstration:
https://www.youtube.com/watch?v=aIIc2DiZYcI

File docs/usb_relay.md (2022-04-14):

## Relaying internet access to the Pi Zero 1.3 over USB

Note that this is an optional, alternate way to initialize your SeedSigner. The default method is to work on a separate Raspberry Pi device that has internet access. Be aware that by enabling internet access over USB you are obviously creating a link to the outside world that this project seeks to avoid.

If you use this setup route, we recommend that you disable internet access over USB when these steps are complete.

### Get started

Insert the SD card with your Raspberry Pi OS image into a regular computer. Open a terminal window (macOS: Terminal; Windows: Command Prompt) and navigate to the SD card:
```
# mac/Linux:
cd /Volumes/boot

# Windows (alter with correct drive letter):
cd e:
```

We need to create an empty file called "ssh" to enable us to remotely terminal into the Pi via SSH.
```
# mac/Linux:
touch ssh

# Windows:
type nul > ssh
```

Now we have some incomprehensible configuration steps to set up the internet access relay.

Edit `config.txt`:
```
# mac/Linux:
nano config.txt

# Windows:
notepad config.txt
```

Add `dtoverlay=dwc2` to the end of `config.txt`. Exit and save changes (CTRL-X, then "y" in nano).

Alternatively, add to `config.txt` via the command line:
```
# mac/Linux/Windows:
echo dtoverlay=dwc2 >> config.txt
```

Next, edit `cmdline.txt`:
```
# mac/Linux:
nano cmdline.txt

# Windows:
notepad cmdline.txt
```

Add `modules-load=dwc2,g_ether` **directly after** `rootwait`:
```
blah blah rootwait modules-load=dwc2,g_ether [possibly more blah]
```

Exit and save changes (CTRL-X, then "y" in nano).

If you are on Linux, you need to first [set a static IP](#set-a-static-ip-on-linux) for both your Pi Zero 1.3 and your host computer. Otherwise, continue with the steps below.

Eject the SD card and insert it into your Pi Zero 1.3. Plug a USB cable into your computer and into the Pi's USB connector that is closer to the center. It will draw power from the USB cable and begin powering up.

The Pi will take a minute or so to boot up its OS. After waiting a bit, try to communicate with the Pi over SSH:
```
# Manual builds:
ssh pi@raspberrypi.local

# Pre-built image:
ssh pi@seedsigner.local
```

If you see the following prompt, type `yes` to continue:
```
The authenticity of host 'raspberrypi.local (192.168.2.3)' can't be established.
ECDSA key fingerprint is SHA256:go4yVgii1GcvyxzhOe03atLn5bl2NhZlOR04tJHBo+k.
Are you sure you want to continue connecting (yes/no/[fingerprint])?
```

At the password prompt enter the Pi's default password: `raspberry`

If you now see the Pi's command prompt, you're in!



Notice this warning in particular:
```
SSH is enabled and the default password for the 'pi' user has not been changed.
This is a security risk - please login as the 'pi' user and type 'passwd' to set a new password.
```

If someone savvy got access to your SeedSigner, they could sign into it and potentially upload malicious code. To add an extra layer of protection, change the default 'pi' user's password now by typing `passwd`:
```
pi@raspberrypi:~ $ passwd
Changing password for pi.
Current password: 
New password: 
Retype new password: 
passwd: password updated successfully
```

## Configure host computer to share internet access with the Pi

### macOS
Open the "Network" system settings. You should see an entry called "RNDIS/Ethernet Gadget":



Click "Advanced" and change "Configure IPv6" to "Link-local only":



Click "OK" and save your changes.

Now go to the "Sharing" system settings. Click on "Internet Sharing" and check the "RNDIS/Ethernet Gadget". 



Click the "Internet Sharing" checkbox to activate.

Back at your SSH terminal, test the connection:
```
ping 8.8.8.8
```

_Hit `CTRL-C` to abort the ping_

If you see a ping response, the Pi has internet access!



### Windows
see: https://www.circuitbasics.com/raspberry-pi-zero-ethernet-gadget/

### Linux
To enable IP forwarding on your Host:
```
nano /etc/sysctl.conf
```

and uncomment the following line:
```
net.ipv4.ip_forward = 1
```

Then run `sudo sysctl -p` to have immediate effect.

You should now be able to SSH into your internet connected Pi Zero 1.3, as described in the ["Get started"](#get-started) section.

## Set a static IP on Linux
_This guide is intended for Debian/Ubuntu based distros._

In order to set up the connection between your computer and the Pi Zero, you will have to set a static IP on both endpoints of the connection.

What you will need:

* `def_iface` is the Iface of the "default" Destination network. On your __Host__ machine, type `route` to find it.
* `host_ip` is the IP address of your Host on the USB interface. For this guide we will use `192.168.21.20`
* `rpi_ip` is the IP address of your Pi Zero on the USB interface. Use `192.168.21.21`

_Note: Remember to remove the brackets. For example, `ip_address=<rpi_ip>` should be written as: `ip_address=192.168.21.21`_

#### On the SD card
```
cd rootfs/etc
nano dhcpcd.conf
```
At the end of the file, add the following lines.
```
interface usb0
static ip_address=<rpi_ip>/24
static routers=<host_ip>
static domain_name_servers=8.8.8.8 8.8.4.4
```

Eject the SD card and insert it into your Pi Zero 1.3. Plug a USB cable into your computer and into the Pi's USB connector that is closer to the center. It will draw power from the USB cable and begin powering up. 

#### On the Host machine

Type `lsusb` to see if your Pi Zero is properly connected. Look for `Ethernet/RNDIS Gadget`:

Static IP on the seedsigner Interface

Set a name for your new Interface:
```
nano /etc/systemd/network/10-rename-rpi0.link
```

Now paste in the following text:
```
[Match]
Property=ID_VENDOR_ID=0525 "ID_MODEL_ID=a4a2"
[Link]
Name=seedsigner0
```

To give your Host a static ip:
```
nano /etc/network/interfaces.d/seedsigner
```

Now paste in the following text:
```
auto seedsigner0
iface seedsigner0 inet static
address <host_ip>
netmask 255.255.255.0
post-up /sbin/iptables -t nat -A POSTROUTING -o <def_iface> -j MASQUERADE
```

Reboot your computer.

To see if everything is set up correctly, type `ifconfig` and look for the `seedsigner0` interface. It should have the <host_ip> assigned to it. 

Static IP on the seedsigner Interface

Continue by configuring your host computer to [share internet access](#linux) with your Pi Zero.

## Complete the setup
Return to the main [README](../README.md) and complete the setup steps. But remember to come back here and disable internet access over USB on your SeedSigner.

## Disable internet access
Power down the SeedSigner and remove the SD card. Put the SD card back into your computer and use a terminal to navigate to the `boot` drive (same process as above).

Edit `config.txt`:
```
# mac/Linux:
nano config.txt

# Windows:
notepad config.txt
```

Delete the `dtoverlay=dwc2` line that we added to the end of the file. Exit and save changes (CTRL-X, then "y" in nano).

Edit `cmdline.txt`:
```
# mac/Linux:
nano cmdline.txt

# Windows:
notepad cmdline.txt
```

Delete `modules-load=dwc2,g_ether`. Exit and save changes (CTRL-X, then "y" in nano).

Eject the SD card and put it back in the SeedSigner. Connect the SeedSigner to your computer with a USB cable. It should no longer show up as a "RNDIS/Ethernet Gadget".

SSH into the pi and try to `ping 8.8.8.8`. It should fail with no responses.

For full security, put the SD card back in your computer one last time and delete the `ssh` file from `boot`:
```
# mac/Linux:
rm ssh

# Windows:
del ssh
```

You're now good to go with a SeedSigner that is back to being fully air-gapped!

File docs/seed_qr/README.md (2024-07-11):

# SeedQR Format Specification

[SeedSigner](https://github.com/SeedSigner/seedsigner/) is an open source, DIY, fully-airgapped Bitcoin hardware wallet that wipes all private data from memory each time it's turned off. That means users need to re-enter their mnemonic seed phrase each time they use it.

To speed up this key entry process we have defined a way to encode a BIP-39 mnemonic seed phrase as a QR code that can be instantly scanned into a SeedSigner or potentially any other Bitcoin hardware wallet that has a camera.

The approach is specifically designed to encode the minimum possible amount of data in order to keep the resulting QR code small enough that it can be transcribed *by hand*. This sounds ridiculous at first, but remember that this is secret data that should never be stored in any digital medium. And even printers present some additional risk vectors.

<table align="center">
    <tr><td><br/><em>Obviously this SeedQR is just for demonstration purposes; never photograph your SeedQRs!</em></td></tr>
</table>

We have defined two QR formats:
* Standard SeedQR
* And a more advanced CompactSeedQR

Specifications for each follow below, as well as discussion of the pros and cons of each format.

## Quick Review of BIP-39 Mnemonic Seed Phrases
The typical method for backing up a Bitcoin wallet is to store its [BIP-39](https://github.com/bitcoin/bips/blob/master/bip-0039.mediawiki) mnemonic seed phrase consisting of 12 or 24 words.

Each word comes from a [list of 2048 words](https://github.com/bitcoin/bips/blob/master/bip-0039/english.txt). The words themselves are meaningless; all that matters is the word's position number (aka index) in the word list.

For example, "tomato" is the 1,825th word in the list.

But code always starts counting list items with zero. So the index of "tomato" is actually `1824` (if you're looking at the github wordlist line numbers, just remember to always subtract one).

So we can transcode a 12-word seed into a series of indices:

```
 1. vacuum    1924
 2. bridge     222
 3. buddy      235
 4. supreme   1743
 5. exclude    631
 6. milk      1124
 7. consider   378
 8. tail      1770
 9. expand     641
10. wasp      1980
11. pattern   1290
12. nuclear   1210
```

# "Standard" `SeedQR` Specification
We take the indices of the mnemonic seed phrase and concatenate them into one long stream of digits. Each index must be exactly four digits so shorter numbers must be zero-padded (`12` becomes `0012`).

Using the example above:

```bash
# with zero-padded indices:
1924 0222 0235 1743 0631 1124 0378 1770 0641 1980 1290 1210

# final assembled digit stream:
192402220235174306311124037817700641198012901210
```

This digit stream is then encoded into a QR code.

### QR Code Data Formats
It's important to note here that QR codes can encode data in a number of different ways:

<table align="center">
    <tr><td align="center"><br/><em><a href="https://www.qrcode.com/en/about/version.html">qrcode.com</a></em></td></tr>
</table>

QR codes are typically used to encode a website url, in which case the "Alphanumeric" format has to be used (the encoded data can consist of upper- and lowercase letters, numbers, and certain allowed symbols).

If you have a long url like `https://ohnoihavealongurl.com` (29 characters), the chart shows that it would not fit in a 21x21 QR code; its max capacity is 25 alphanumeric chars. But it's within the 47-char capacity of the 25x25 size.

### Bit efficiency matters
Notice that the "Numeric" column has greater capacity. This is because when you have fewer possible characters to encode, it takes less data to specify each one.

Alphanumeric format supports 44 possible characters. They are encoded as pairs, so that means there are 44^2 = 1,936 possible pairings to describe. Each pair can then be encoded using 11 bits:

```
2^11 = 2048
```

If you only used 10 bits, you could only specify 2^10 = 1,024 possible values; not nearly enough for the 1,936 possible pairings. 11 bits is the best this format can do.

The Numeric format is able to store 3 digits using just 10 bits. The largest possible 3-digit number is `999`, therefore 10 bits (2^10 = 1,024) is sufficient.

This is why a 25x25 QR code can only store 47 alphanumeric characters vs 77 numeric digits. It's the same amount of total data in terms of bits:

```
47 alphanumeric chars / 2 chars per pair * 11 bits per pair = 259 bits

77 numeric digits / 3 digits per group * 10 bits per group = 257 bits
```
*(both formats round up to 260 bits)*

Armed with this knowledge, we're ready to encode our SeedQR.

## Generate the SeedQR
Our SeedQR data will consist solely of numeric digits so that we can use the more efficient "Numeric" format. Our 12-word mnemonic seed phrase requires:

```
12 words * 4 digits per word = 48 digits
```

48 numeric digits won't fit in a 21x21 using the "L" (Low) error correction mode (max Numeric capacity is 41) but will easily fit in a 25x25:

<table align="center">
    <tr><td></td></tr>
</table>

If you scan this QR code with your phone, you'll see the human-readable digit stream:

<table align="center">
    <tr><td></td></tr>
</table>

And see for yourself that the digit stream matches what was generated above from the mnemonic seed word indices.

```
192402220235174306311124037817700641198012901210
```

At this point it is trivial for a SeedSigner or other Bitcoin hardware wallets to parse the digit stream back into the individual BIP-39 wordlist indices and rebuild your entire mnemonic seed phrase.

Looking back at the QR code capacity chart for Numeric data, we know exactly how large the resulting SeedQRs will be:
```
12-word mnemonic (48 digits) = 25x25
24-word mnemonic (96 digits) = 29x29
```

Examples:
<table align="center">
    <tr>
        <td align="center"><br/>12-word Standard SeedQR</td>
        <td align="center"><br/>24-word Standard SeedQR</td>
    </tr>
</table>

# `CompactSeedQR` Specification
The `CompactSeedQR` format builds upon the "Standard" `SeedQR` format by further optimizing how the data is stored in order to generate smaller QR codes that are easier to transcribe by hand.

Notice in the QR code capacity chart above that there's also a "Binary" column, but its relative capacity count initially looks pretty unimpressive; a 25x25 QR code is limited to 32.

But here the unit being described isn't alphanumeric characters or numeric digits; it's max number of bytes.

```
1 byte = 8 bits
```

Rather than having the QR format interpret our data as numbers or characters, we can directly encode the relevant bits that determine our mnemonic seed phrase.

We can extract exactly those bits from our mnemonic seed phrase digit stream that we generated above.

Let's bring back our mnemonic seed phrase's individual indices:

```bash
1924 0222 0235 1743 0631 1124 0378 1770 0641 1980 1290 1210
```

We know that the BIP-39 wordlist contains exactly 2048 words. That means we will need 11 bits to express each index in binary (2^11 = 2048; not a coincidence!):
```
1924 11110000100
0222 00011011110
0235 00011101011
1743 11011001111
0631 01001110111
1124 10001100100
0378 00101111010
1770 11011101010
0641 01010000001
1980 11110111100
1290 10100001010
1210 10010111010
```

We concatenate all those binary values to one large 132-bit stream:
```
111100001000001101111000011101011110110011110100111011110001100100001011110101101110101001010000001111101111001010000101010010111010
```

BIP-39 specifies a checksum word at the end of each mnemonic seed phrase. In a 12-word mnemonic, the last 4 bits are the checksum. In a 24-word mnemonic, the last 8 bits are the checksum.

The checksum is trivially calculated from the prior bits (in this case, the first 128 bits of our stream). Therefore we do not need to include those bits in our CompactSeedQR.

```
12-word mnemonic = 12 words * 11 bits per word = 132 bits
12-word CompactSeedQR = 132 bits - 4 checksum bits = 128 bits

24-word mnemonic = 24 words * 11 bits per word = 264 bits
24-word CompactSeedQR = 264 bits - 8 checksum bits = 256 bits
```

How well will these bit streams fit in a "Binary" QR code? Referring back to the QR code capacity chart we find the following for the "L" (Low) error correction mode:
```
12-word mnemonic: 128bits / 8 bits per byte = 16 bytes = 21x21

24-word mnemonic: 256bits / 8 bits per byte = 32 bytes = 25x25
```

So by using the optimally-efficient Binary encoding, we have made each CompactSeedQR one size smaller than its Standard SeedQR counterpart.

Examples:
<table align="center">
    <tr>
        <td align="center"><br/>12-word CompactSeedQR</td>
        <td align="center"><br/>24-word CompactSeedQR</td>
    </tr>
</table>

# Standard SeedQR vs CompactSeedQR

Here are the two formats side-by-side.

The same 12-word seed in each format:
<table align="center">
    <tr>
        <td align="center"><br/>Standard SeedQR (25x25)</td>
        <td align="center"><br/>CompactSeedQR (21x21)</td>
    </tr>
</table>

The same 24-word seed in each format:
<table align="center">
    <tr>
        <td align="center"><br/>Standard SeedQR (29x29)</td>
        <td align="center"><br/>CompactSeedQR (25x25)</td>
    </tr>
</table>

Since the goal of the SeedQR concept is to make it easy to transcribe by hand, it's natural to assume that the CompactSeedQR is better.

Let's compare actual "real estate" in each size. All of our QR sizes have three large 8x8 registration blocks in the corners. 29x29 and 25x25 have a smaller 5x5 registration block in the lower right.

```
29x29 - (3*8x8) - 5x5 = 624 blocks
25x25 - (3*8x8) - 5x5 = 408 blocks
21x21 - (3*8x8)       = 249 blocks
```

So by shrinking a 24-word Standard SeedQR from 29x29 down to a CompactSeedQR at 25x25, we've reduced the area we have to manually transcribe to:

```
408 / 624 = 65%
```

And similarly, shrinking a 12-word 25x25 Standard SeedQR down to a CompactSeedQR at 21x21:

```
249 / 408 = 61%
```

If you're manually punching holes into a metal SeedQR plate, that's cutting out about 35-40% of the work!

<table align="center">
    <tr><td></td></tr>
</table>

But there are other tradeoffs to consider.

## Recoverability
If you lose your SeedSigner or somehow the project is abandoned or banned, how will you read back your SeedQR? 

With the Standard SeedQR format this is trivial--any smartphone can decode the numeric digit stream. But the CompactSeedQR's raw byte data is not decipherable in the same way. Most QR readers today assume the data is either alphanumeric or human-readable numeric data. Because of this assumption, they misinterpret the binary format data:

<table align="center">
    <tr>
        <td align="center"><br/>Standard SeedQR</td>
        <td align="center"><br/>CompactSeedQR</td>
    </tr>
</table>

The clearly readable Standard SeedQR digit stream can be manually transcribed back to a mnemonic seed phrase with no other computer assistance, if need be.

It's just the above process in reverse:
```bash
# 12-word Standard SeedQR digit stream
192402220235174306311124037817700641198012901210

# Separate out into 4-digit individual indices
1924 0222 0235 1743 0631 1124 0378 1770 0641 1980 1290 1210

# Look up each BIP-39 index number (index+1 if using the github list!)
 1. vacuum    1924
 2. bridge     222
 3. buddy      235
 4. supreme   1743
 5. exclude    631
 6. milk      1124
 7. consider   378
 8. tail      1770
 9. expand     641
10. wasp      1980
11. pattern   1290
12. nuclear   1210
```

It would be much more difficult to manually recreate your seed from a CompactSeedQR. Tools like [zxing.org](https://zxing.org/w/decode.jspx) or [ZBar](https://zbar.sourceforge.net/) can help you get the binary data out as a hexidecimal string:



Note that for some QR decoders, zxing in particular, may return more data than the compact seed itself: the data type, the data length, and padding.  For example, the zxing result from 12-word CompactSeedQRs in low error correction mode will start with `41 0` (that specifies the binary data format and says the length of the data is 16 bytes) and end with `0 ec` (unused byte and a half). Similarly, 24-word CompactSeedQRs will start with `42 0` (binary, data length is 32 bytes) and end with `0` (unused half a byte).

The ZBar library just returns the encoded data, without metadata or padding.

## Obfuscation
Conversely, having limited support for reading binary QR codes and the complications described above are seen by some as an added security feature. Should someone steal your CompactSeedQR or take a photo of it, they'll have to be fairly savvy to know how to decode it.

# Some Additional Notes on QR Codes
Our main use case is to be able to quickly initialize a SeedSigner with your mnemonic seed phrase. But using a QR code as your key loader--or even as your permanent backup etched in metal--has other advantages.

QR codes are ubiquitous now so plenty of hardware and software exists to read and generate them.

QR codes have built-in error correction. The "L" error correction mode is described as having a roughly 7% correction rate.

In general, QR codes are incredibly resilient to unreadable blocks. For example, you often see the middle blocks intentionally covered over with a logo:

<table align="center"><tr><td></td></tr></table>

This is right at the limit of SeedSigner's ability to read this 24-word SeedQR, despite the inaccessible blocks.

Similarly, QR codes can withstand human error during the manual transcription process. A few mis-coded blocks, a smeared ink blob, or other physical blemishes will generally not cause any problems.

# Test SeedQRs
Sample test vectors to verify your own encode and decode implementations:

---

## Test Vector 1: 24-word seed
```bash
# 24-word seed:
attack pizza motion avocado network gather crop fresh patrol unusual wild holiday candy pony ranch winter theme error hybrid van cereal salon goddess expire

# Standard SeedQR digit stream:
011513251154012711900771041507421289190620080870026613431420201617920614089619290300152408010643

# CompactSeedQR bitstream:
0000111001110100101101100100000100000111111110010100110011000000110011001111101011100110101000010011110111001011111011000011011001100010000101010100111111101100011001111110000011100000000010011001100111000000011110001001001001011001011111010001100100001010

# CompactSeedQR bytestream:
b'\x0et\xb6A\x07\xf9L\xc0\xcc\xfa\xe6\xa1=\xcb\xec6b\x15O\xecg\xe0\xe0\t\x99\xc0x\x92Y}\x19\n'
```

<table align="center">
    <tr>
        <td align="center"><br/>Standard SeedQR</td>
        <td align="center"><br/>CompactSeedQR</td>
    </tr>
</table>

---

## Test Vector 2: 24-word seed
Note that this vector and a few others below include a null byte character (`\x00`) in its CompactSeedQR bytestream. This is a particularly troublesome character for most QR readers; most will read this character as an instruction to stop reading any further data.

Take extra care to confirm that your implementation correctly reads these characters and all remaining data after it!

```bash
# 24-word seed:
atom solve joy ugly ankle message setup typical bean era cactus various odor refuse element afraid meadow quick medal plate wisdom swap noble shallow

# Standard SeedQR digit stream:
011416550964188800731119157218870156061002561932122514430573003611011405110613292018175411971576

# CompactSeedQR bitstream:
0000111001011001110111011110001001110110000000001001001100010111111100010010011101011111000100111000100110001000100000000111100011001001100100110110100011010001111010000010010010001001101101011111011000101001010100110001111111000101101101101010010101101110

# CompactSeedQR bytestream:
b"\x0eY\xdd\xe2v\x00\x93\x17\xf1'_\x13\x89\x88\x80x\xc9\x93h\xd1\xe8$\x89\xb5\xf6)S\x1f\xc5\xb6\xa5n"
```

<table align="center">
    <tr>
        <td align="center"><br/>Standard SeedQR</td>
        <td align="center"><br/>CompactSeedQR</td>
    </tr>
</table>

---

## Test Vector 3: 24 word seed
```bash
# 24-word seed:
sound federal bonus bleak light raise false engage round stock update render quote truck quality fringe palace foot recipe labor glow tortoise potato still

# Standard SeedQR digit stream:
166206750203018810361417065805941507171219081456140818651401074412730727143709940798183613501710

# CompactSeedQR bitstream:
1100111111001010100011000110010110001011110010000001100101100010010101001001001001010010101111000111101011000011101110100101101100001011000000011101001001101011110010101110100010011111001010110101111011001110101111100010011000111101110010110010101000110110

# CompactSeedQR bytestream:
b'\xcf\xca\x8ce\x8b\xc8\x19bT\x92R\xbcz\xc3\xba[\x0b\x01\xd2k\xca\xe8\x9f+^\xce\xbe&=\xcb*6'
```

<table align="center">
    <tr>
        <td align="center"><br/>Standard SeedQR</td>
        <td align="center"><br/>CompactSeedQR</td>
    </tr>
</table>

---

## Test Vector 4: 12-word seed
```bash
# 12-word seed:
forum undo fragile fade shy sign arrest garment culture tube off merit

# Standard SeedQR digit stream:
073318950739065415961602009907670428187212261116

# CompactSeedQR bitstream:
01011011101111011001110101110001101010001110110001111001100100001000001100011010111111110011010110011101010000100110010101000101

# CompactSeedQR bytestream:
b'[\xbd\x9dq\xa8\xecy\x90\x83\x1a\xff5\x9dBeE'
```

<table align="center">
    <tr>
        <td align="center"><br/>Standard SeedQR</td>
        <td align="center"><br/>CompactSeedQR</td>
    </tr>
</table>

---

## Test Vector 5: 12-word seed
```bash
# 12-word seed:
good battle boil exact add seed angle hurry success glad carbon whisper

# Standard SeedQR digit stream:
080301540200062600251559007008931730078802752004

# CompactSeedQR bitstream:
01100100011000100110100001100100001001110010000000110011100001011100001000110011011111011101100001001100010100001000100111111101

# CompactSeedQR bytestream:
b"dbhd' 3\x85\xc23}\xd8LP\x89\xfd"
```

<table align="center">
    <tr>
        <td align="center"><br/>Standard SeedQR</td>
        <td align="center"><br/>CompactSeedQR</td>
    </tr>
</table>

---

## Test Vector 6: 12-word seed
```bash
# 12-word seed:
approve fruit lens brass ring actual stool coin doll boss strong rate

# Standard SeedQR digit stream:
008607501025021714880023171503630517020917211425

# CompactSeedQR bitstream:
00001010110010111011101000000000100011011001101110100000000001011111010110011001011010110100000010100011010001110101110011011001

# CompactSeedQR bytestream:
b'\n\xcb\xba\x00\x8d\x9b\xa0\x05\xf5\x99k@\xa3G\\\xd9'
```

<table align="center">
    <tr>
        <td align="center"><br/>Standard SeedQR</td>
        <td align="center"><br/>CompactSeedQR</td>
    </tr>
</table>

---

## Test Vectors 7-9: Additional Compact SeedQR problem characters
Explicitly check Compact SeedQRs whose byte stream contains `\n`, `\r`, or `\r\n`:

`\n`:
```bash
# 12-word seed:
dignity utility vacant shiver thought canoe feel multiply item youth actor coyote

# Standard SeedQR digit stream:
049619221923158517990268067811630950204300210397

# CompactSeedQR bitstream:
00111110000111100000101111000001111000110001111000001110010000110001010100110100100010110111011011011111111011000000101010011000

# CompactSeedQR bytestream:
b'>\x1e\x0b\xc1\xe3\x1e\x0eC\x154\x8bv\xdf\xec\n\x98'
```

<table align="center">
    <tr>
        <td align="center"><br/>CompactSeedQR</td>
    </tr>
</table>

`\r`:
```bash
# 12-word seed:
corn voice scrap arrow original diamond trial property benefit choose junk lock

# Standard SeedQR digit stream:
038719631547010112530489185713790169032209701051

# CompactSeedQR bitstream:
00110000011111101010111100000101100001100101100111001010011110100111101000001101011000110001010100100101000010011110010101000001

# CompactSeedQR bytestream:
b'0~\xaf\x05\x86Y\xcazz\rc\x15%\t\xe5A'
```

<table align="center">
    <tr>
        <td align="center"><br/>CompactSeedQR</td>
    </tr>
</table>

`\r\n`:
```bash
# 12-word seed:
vocal tray giggle tool duck letter category pattern train magnet excite swamp

# Standard SeedQR digit stream:
196218530783182905421028028912901848107106301753

# CompactSeedQR bitstream:
11110101010111001111010110000111111100100101010000111101000000010000100100001101000010101110011100010000101111010011101101101101

# CompactSeedQR bytestream:
b'\xf5\\\xf5\x87\xf2T=\x01\t\r\n\xe7\x10\xbd;m'
```

<table align="center">
    <tr>
        <td align="center"><br/>CompactSeedQR</td>
    </tr>
</table>

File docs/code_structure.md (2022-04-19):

# Code Structure

SeedSigner roughly follows a Model-View-Controller approach. Like in a typical web app (e.g. Flask) the `View`s can be called as needed like individual web urls. After completing display and interaction with the user, the `View` then decides where to route the user next, analogous to a web app returning a `response.redirect(url)`.

The `Controller` then ends up being quite stripped down. For example, there's no need for a web app's `urls.py` since there are no mappings from url to `View` to maintain since we're not actually using a url/http routing approach.

`View`s have to handle user interaction so there are `while True` loops that cycle between waiting for user input, gathering data, and then updating the UI components accordingly. You wouldn't find this kind of cycle in a web app because this sort of interactive user input is handled in the browser at the html/css/js level.

* `Model`s: Store the persistent settings, the in-memory seeds, current wallet information, etc.
* `Controller`: Manages the state of the world and controls access to global resources.
* `View`s: Implementation of each screen. Prepares relevant data for display. Must also instantiate the display objects that will actually render the UI.
* `gui.screens`: Re-usable formatted UI renderers.
* `gui.components`: Basic individual UI elements that are used by the `templates` such as the top nav, buttons, button lists, text displays.

In an typical webserver context the `View` would send data to an html template (e.g. Jinja) which would then dynamically populate the page with html elements like `<input>`, `<button>`, `<img>`, etc. This is analgous to our `gui.screens` constructing a UI renderer by piecing together various `gui.components` as needed.

`Controller` is a global singleton that any `View` can access and update as needed.

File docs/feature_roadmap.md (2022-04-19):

# Feature Roadmap

Current focus: v0.5.0 preview releases.

*Note: It may or may not make sense to do minor bugfix preview releases along the way (e.g. 1.0 -> 1.1).*

## v0.5.0 Pre-Release 1.x
* Scan SeedQR / CompactSeedQR
* Add/Edit passphrase
* View seed words w/configurable warnings
* Export xpub w/configurable warnings and flow determined by Settings
* Scan PSBT
* Full PSBT review screens
* "Full Spend" (no change) warning
* Fully verify PSBT change addrs
* Send signed PSBT via QR
* QR display dimming/brightness UP/DOWN
* Subset of configurable Settings; persistent Settings storage
* SettingsQR integration proof-of-concept

Screens will be functional but not necessarily in their final presentation state (icons, text, positioning, etc).

## v0.5.0 Pre-Release 2.x
* Existing screen refinement (visual presentation, text, etc)
* Create new seed via image entropy
* Manual mnemonic seed word entry
* 12th/24th word calc
* SeedQR/CompactSeedQR manual transcription UI w/configurable UI style (dots vs grid)
* Single sig address scan and verification
* SettingsQR standalone UI refinement
* Fix broken tests
* All GUI Components support scrollable Screens

## v0.5.0 Pre-Release 3.x
* Settings: I/O Test
* Create new seed via dice rolls
* Custom derivation paths in xpub export flow
* QR display dimming/brightness, framerate, density(?) controls in transparent overlay
* HRF partner logo on startup
* Improve test suite coverage
* Further existing screen refinement
* "Final" bugfixes

## Initial v0.5.0 Release
All of the above!

## Beyond v0.5.0
These features will not be included in the initial v0.5.0 release and will have varying degrees of priority for subsequent releases (or possibly not at all).

* Multisig wallet descriptor QR scan(?) and addr verification(?)
* Sign taproot txs
* Multi-language support (Transifex free for open source projects)
* Multisig: sign PSBT with multiple keys at once.
* Custom OS, possibly with swappable SD card PSBT and multisig wallet descriptor storage
* Decoy game mode at launch (Snake, Tetris, Sudoku...?)
* BIP-39 wordlists in additional languages
* Address message signing
* UI color scheme customization
* Specify missing entropy for 12th/24th word calc

# v0.6 and Beyond...?
* Alternate hardware profile / touchscreen
* PGP signer
* Liquid?

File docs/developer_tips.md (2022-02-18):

# Developer Tips

### Quickly generate a new seed to test with
Generate a new 12- or 24-word seed via [https://iancoleman.io/bip39/](https://iancoleman.io/bip39/).

Access a `python3` environment that has the `embit` library installed (e.g. your own local machine, ssh into the SeedSigner, etc)

Start a python REPL session by just typing: `python3`

Paste in the following but insert your newly generated mnemonic:
```
from embit import bip39
seed_phrase = "smoke chimney announce candy glory tongue refuse fatigue cricket once consider beef treat urge wing deny gym robot tobacco adult problem priority wheat diagram"
data = ""
for word in seed_phrase.split(" "):
    index = bip39.WORDLIST.index(word)
    data += "%04d" % index

print(data)
```

For the seed in the snippet, you should see:
```
163803200074026607961827144306700411123603780160185419152013046908321497181700301371136719990487
```

Take the output and paste it into a [QR code generator](https://www.the-qrcode-generator.com/).

Start up SeedSigner's UI to import a seed from a QR code. Scan the new QR code and you're good to go!

# Advanced developer notes

## Backup an SD card

You can back up and restore any size SD card but the process is a little inefficient so the bigger the source SD card, the bigger the backup will be and the longer it'll take to create (and even longer to image back to a new SD card), even if most of the card is blank.

You can restore a backup image to an SD card of the same or larger size. So it's strongly recommended to do repetitive development work on a smaller card that's easier to backup and restore. Once the image is stabilized, then write it to a bigger card, if necessary (that being said, there's really no reason to use a large SD card for SeedSigner. An 8GB SD card is more than big enough).

Insert the SD card into a Mac/Linux machine and create a compressed img file.

First verify the name of your SD card:

```
# Mac:
diskutil list

# Linux:
sudo fdisk -l
```

It will most likely be `/dev/disk1` on most systems.

Now we use `dd` to clone and `gzip` to compress it. Note that we reference the SD card by adding an `r` in front of the disk name. This speeds up the cloning considerably.

```
sudo dd if=/dev/rdisk1 conv=sparse bs=4m | gzip -9 > seedsigner.img.gz
```

The process should take about 15 minutes and will typically generate a roughly 1.1GB image.

To restore from your backup image, just use the Raspberry Pi Imager. Remember that you can only write it to an SD card of equal or greater size than the original SD card.

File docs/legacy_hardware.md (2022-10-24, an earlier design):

# Legacy Hardware Modifications

Older Raspberry Pi devices have a smaller GPIO header, 26 pin as opposed to the 40 pin header found on more recent models. The Waveshare LCD hat uses some of the pins between 26 and 40 for the buttons, meaning that these will need to be reassigned (and remapped in software) when used with an older device.

## Hardware Changes

A suggested remapping can be found here:
Remapped Pins Shematic

This remapping can be done by soldering wires on to the Waveshare hat as below:
Remapped Pins Photo

Alternatively, you could do this by connecting the LCD hat on with individual breadboard jumper wires.

Once you have re-mapped the pins, it is advised to do an IO Test to ensure that everything works.

**Warning: Some of the GPIO pins on contain 5 volt output. Raspberry Pi GPIO pins are NOT 5V tolerant, meaning that if you accidentally connect a 5V supply pin to a GPIO input pin, you risk permanent damage.**

## Software Changes
The Seedsigner software will automatically detect which hardware revision you are using and if the older hardware is detected, will remap the software to match the above modifications to the Waveshare hat.

If you are using a pre-built Seedsigner image that hasn't yet has this incorporated, you can simply take the file "buttons.py" (/src/seedsigner/hardware/ int his repository) and overwrite same file on your Seedsigner SD card. (The easiest way to do this is to copy it on to the /boot/ partitition of the SD card then copy it over via the command line while connected to your Pi via monitor+keyboard) O

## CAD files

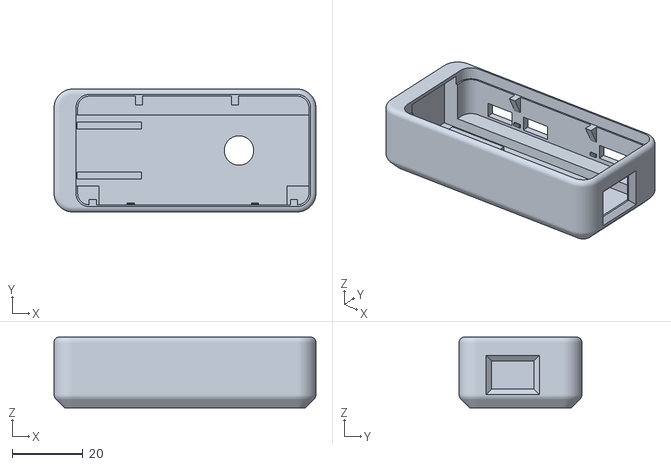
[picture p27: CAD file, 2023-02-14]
enclosures/open_pill_mini/Main_Chassis.stl
73.9 x 34.6 x 20.0

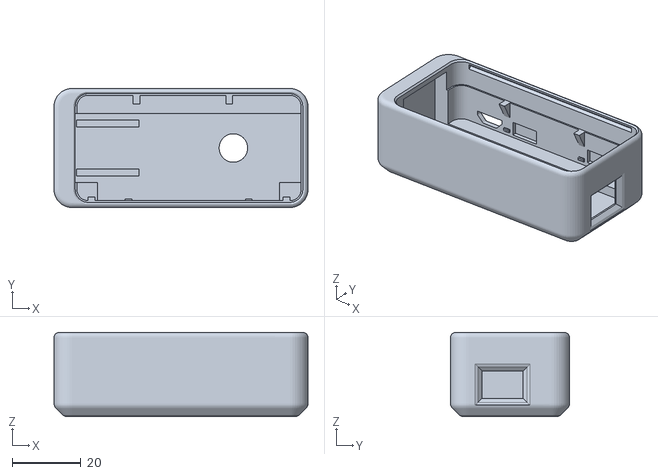
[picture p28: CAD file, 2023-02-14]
enclosures/open_pill_mini_w_coverplate/Main_Chassis.stl
73.9 x 34.6 x 24.5

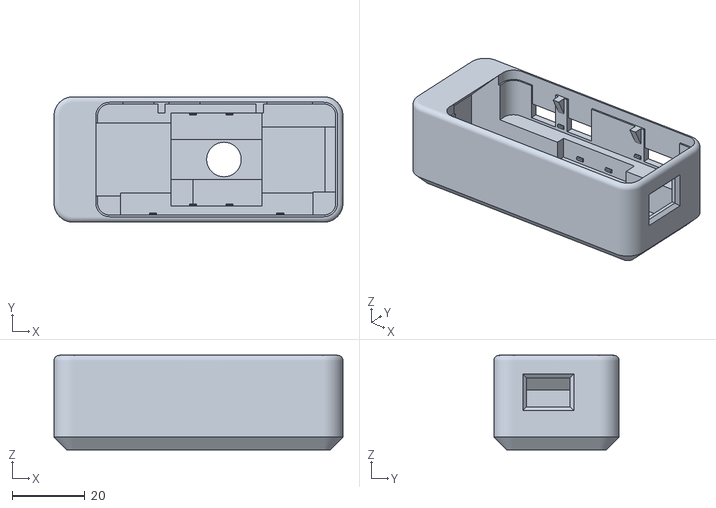
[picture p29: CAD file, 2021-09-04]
enclosures/open_pill/print_file/open_pill.stl
79.5 x 34.5 x 26.0

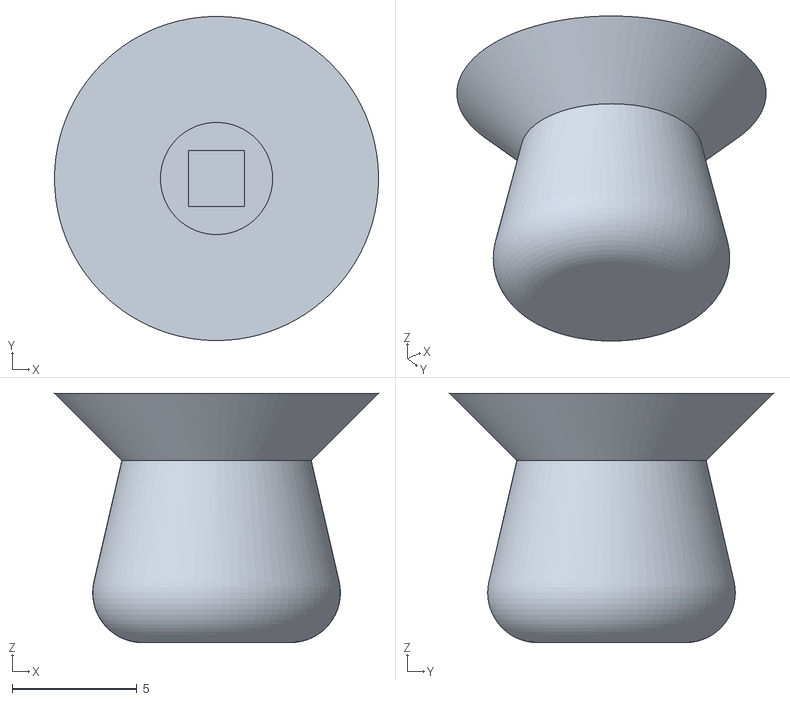
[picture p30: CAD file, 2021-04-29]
enclosures/orange_pill/print_files/joystick.stl
13.0 x 13.0 x 10.00

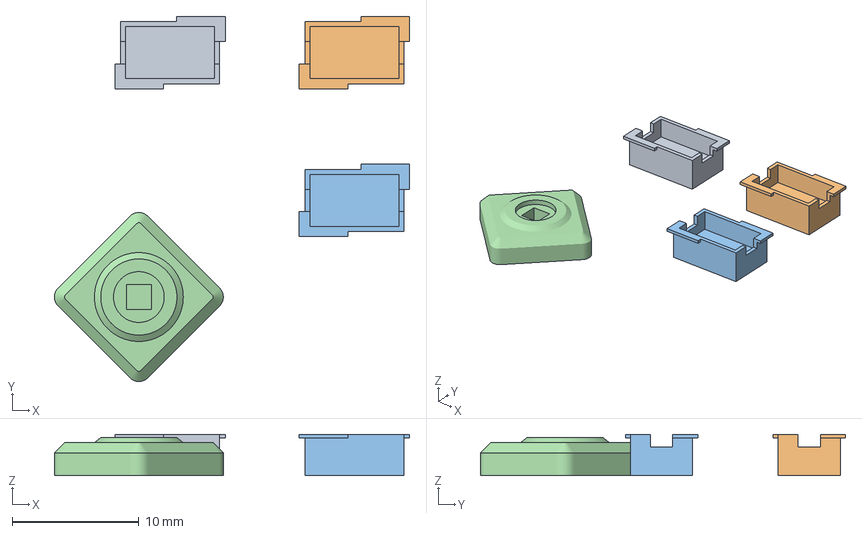
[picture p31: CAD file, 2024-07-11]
enclosures/pushcase/3mf/Buttons - Push Case - SeedSigner.3mf
28.0 x 28.7 x 3.25 mm
Waveshare Button A.stl x 2
Waveshare Button C.stl
Waveshare Thumbstick.stl

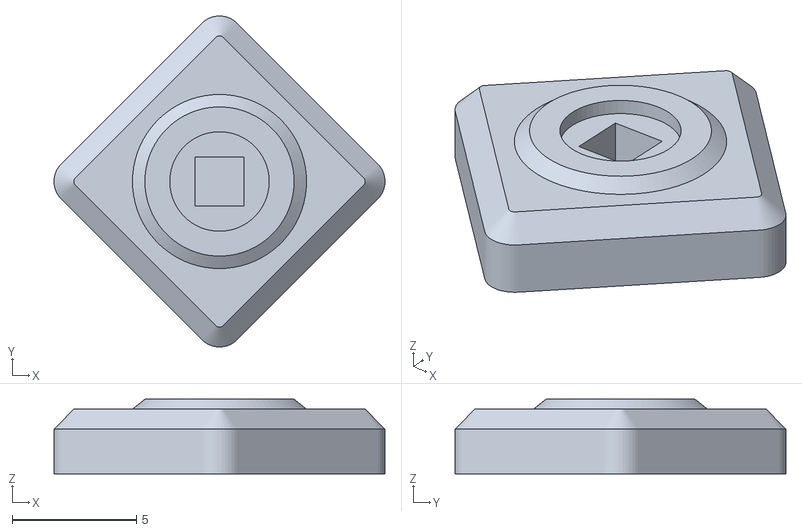
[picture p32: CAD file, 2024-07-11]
enclosures/pushcase/stl/Thumbstick - Push Case - SeedSigner.stl
13.3 x 13.3 x 3.00

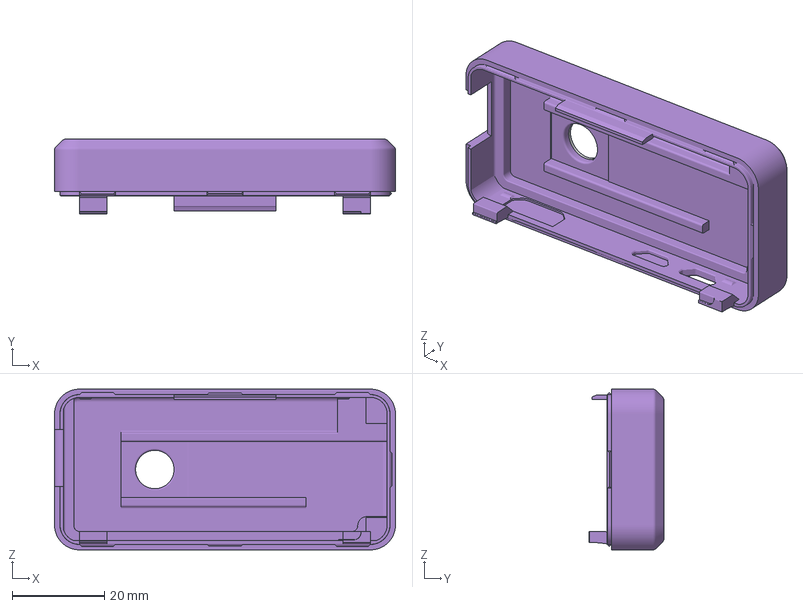
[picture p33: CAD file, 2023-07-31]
enclosures/rugged_pill/Multimaterial/RuggedPIll_Bottom_MMU.3mf
73.8 x 16.2 x 34.8 mm
Bottom V4
Circumference
Logo Big
Logo Small
Ring

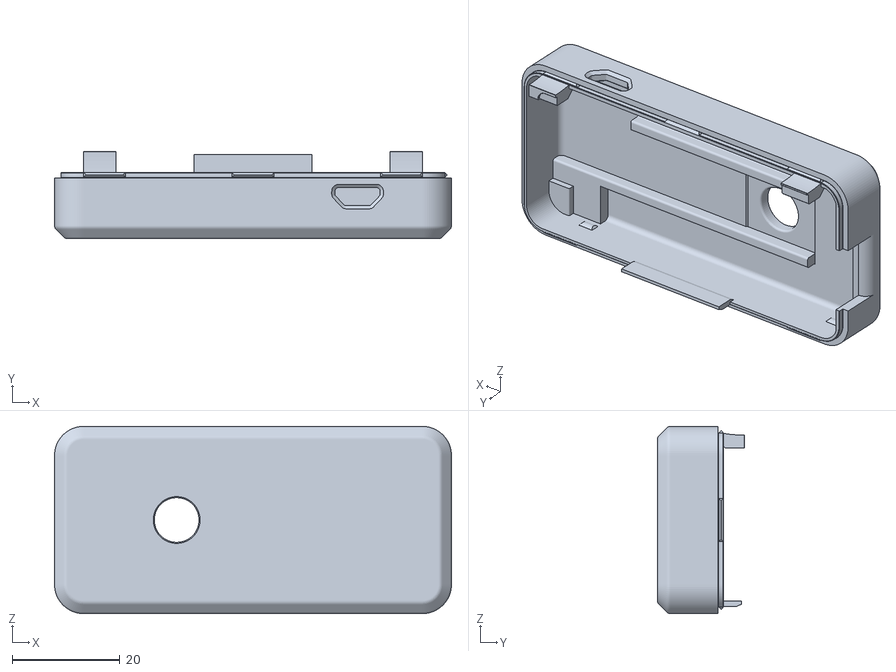
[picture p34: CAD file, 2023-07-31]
enclosures/rugged_pill/RuggedPill_Bottom.stl
73.8 x 16.2 x 34.8

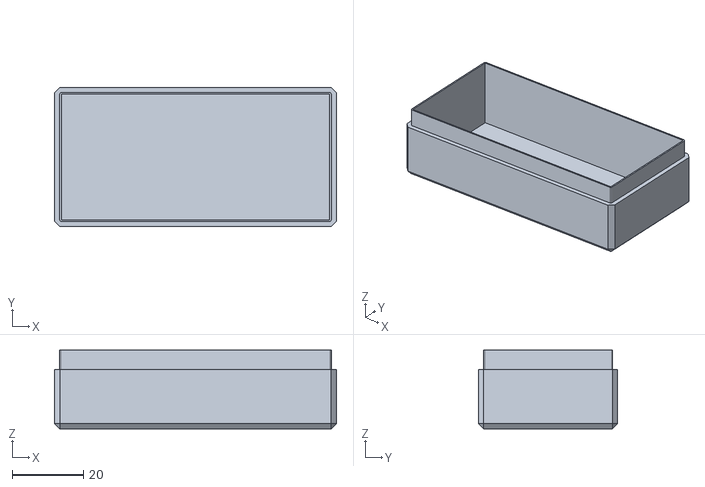
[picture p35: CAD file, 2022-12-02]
enclosures/simple_pill/protective_case/sp_protective_case_lower.stl
79.0 x 39.0 x 22.1

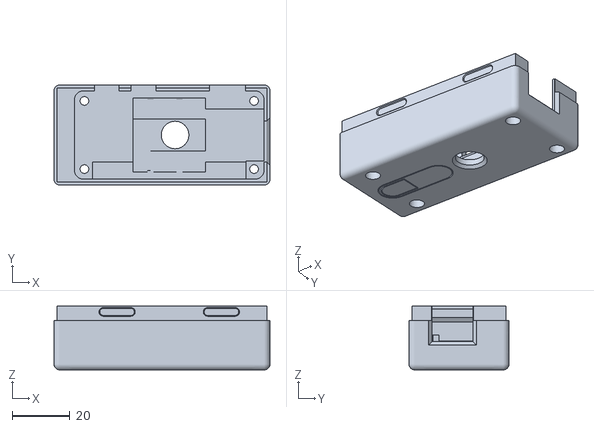
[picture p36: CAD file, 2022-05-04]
enclosures/simple_pill/sp_lower.stl
74.5 x 34.5 x 22.0

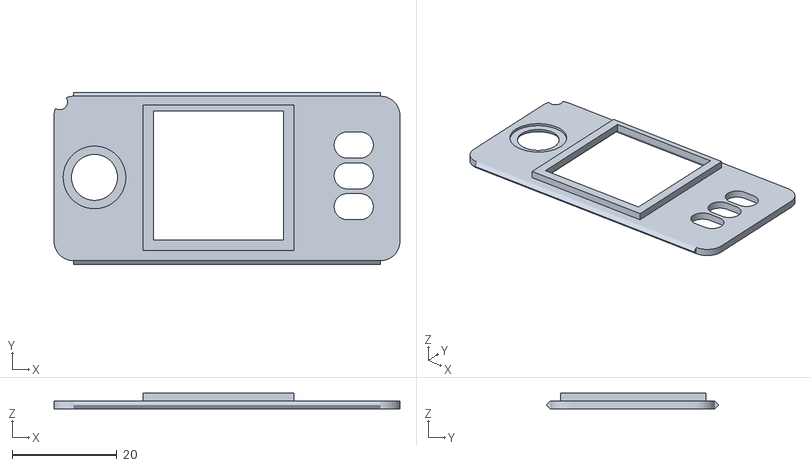
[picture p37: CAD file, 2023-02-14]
enclosures/open_pill_mini_w_coverplate/Lid.stl
66.2 x 33.0 x 3.00

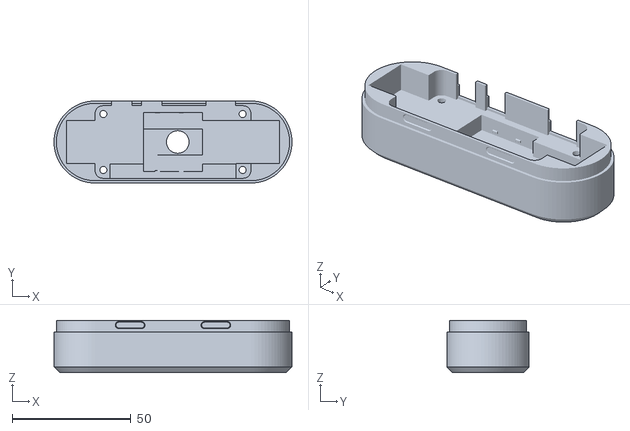
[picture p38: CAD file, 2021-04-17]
enclosures/orange_pill/print_files/OP_Lower.stl
100.0 x 34.5 x 22.0

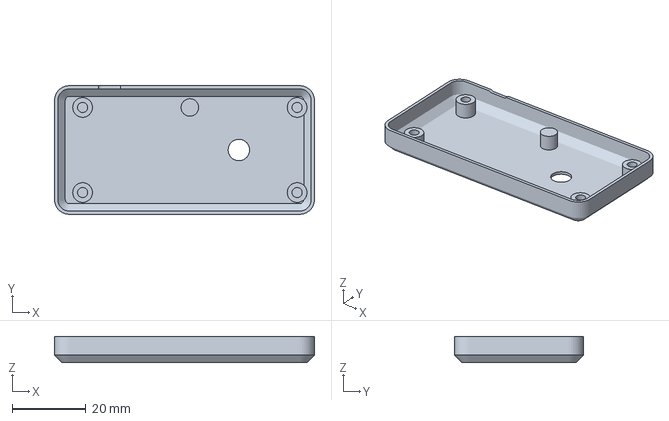
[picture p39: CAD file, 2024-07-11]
enclosures/pushcase/3mf/Bottom - Push Case - SeedSigner.3mf
70.3 x 34.8 x 7.10 mm

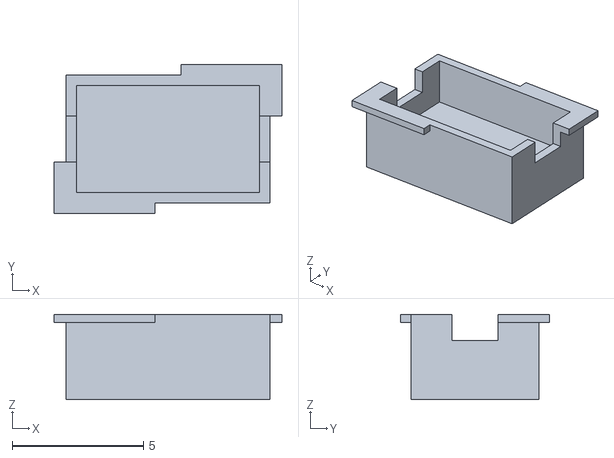
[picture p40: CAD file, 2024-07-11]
enclosures/pushcase/stl/Button - Push Case - SeedSigner.stl
8.70 x 5.70 x 3.25

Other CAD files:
enclosures/rugged_pill/Multimaterial/RuggedPill_Top_MMU.3mf
enclosures/rugged_pill/RuggedPill_Thumbstick.stl
enclosures/simple_pill/protective_case/sp_protective_case_upper.stl
enclosures/simple_pill/sp_upper.stl
enclosures/look_screws_pill/Bottom.stl
enclosures/look_screws_pill/ButtonsConnected.stl
enclosures/look_screws_pill/Top.stl
enclosures/look_screws_pill/pressPad.stl
enclosures/open_pill/design_file/open_pill.f3d
enclosures/open_pill_mini_w_coverplate/Buttons.stl
enclosures/open_pill_mini_w_coverplate/Thumbstick_PLA.stl
enclosures/open_pill_mini_w_coverplate/Thumbstick_TPU.stl
enclosures/orange_pill/design_files/OP_Lower.f3d
enclosures/orange_pill/design_files/OP_Upper.f3d
enclosures/orange_pill/design_files/button.f3d
enclosures/orange_pill/design_files/joystiick.f3d
enclosures/orange_pill/print_files/OP_Upper.stl
enclosures/orange_pill/print_files/button.stl
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

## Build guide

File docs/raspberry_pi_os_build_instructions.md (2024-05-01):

# Raspberry Pi OS Local Dev Build Instructions

Since v0.6.0, official releases use our custom [SeedSigner OS](https://github.com/SeedSigner/seedsigner-os/) However, project contributors looking to do rapid development cycles typically use the older Raspberry Pi OS that we had previously built on prior to v0.6.0. If you're here to set up your SeedSigner for local development, continue reading.

Begin by acquiring the latest 32-bit, Buster-based Raspberry Pi Lite operating system. This guide was tested using the version dated 2023-05-03; which can be found here:

https://downloads.raspberrypi.org/raspios_oldstable_lite_armhf/images/raspios_oldstable_lite_armhf-2023-05-03/

SeedSigner does not work any of the more recent versions of Debian. This is a known limitation and there are open tickets to track the progress of this ([Debian 11 ticket](https://github.com/SeedSigner/seedsigner/issues/431), [Debian 12 ticket](https://github.com/SeedSigner/seedsigner/issues/430)). This guide does not work on the 64-bit versions of Buster, however pull requests to update it to be compatible are welcome.

Best practice is to verify the downloaded file containing the Raspberry Pi Lite OS matches the published SHA256 hash of the file; for additional reference that hash is: 3d210e61b057de4de90eadb46e28837585a9b24247c221998f5bead04f88624c. After verifying the file's data integrity, you can decompress the .tar.xz file to obtain the operating system image that it contains. You can then use Balena's Etcher tool (https://www.balena.io/etcher/) to write the Raspberry Pi Lite software image to a memory card (4 GB or larger). It's important to note that an image authoring tool must be used (the operating system image cannot be simply copied into a file storage partition on the memory card).

The manual SeedSigner installation and configuration process requires an internet connection on the Pi to download the necessary libraries and code.  
If your Pi does not have onboard wifi, you have two options:

1. Run these steps on a separate Raspberry Pi 2/3/4 or Zero W which does have onboard Wi-Fi to connect to the internet, and then move the SD card over to the non Wi-Fi enabled Pi when complete.
2. OR configure the non Wi-Fi enabled Pi directly by relaying through your computer's internet connection over USB. See instructions [here](usb_relay.md).

If your Pi does have onboard Wi-Fi, then using the Rasberry Pi Imager software will allow you to easily configure your Pi's Wi-Fi connection, as well as simultaneously write the image file. That will make your initial SSH into the Pi much easier.   
Use the Pi's onboard Wi-Fi only if you are setting up a local development environment, never for real funds or binary image creation. 
  
For the following steps you'll need to either connect a keyboard & monitor to the network-connected Raspberry Pi you are working with, or SSH into the Pi if you're familiar with that process.

### Configure the Pi
First things first, verify that you are using the correct version of the Raspberry Pi Lite operating system by typing the command:
```bash
cat /etc/os-release
```

The output of this command should match the following text:
```bash
PRETTY_NAME="Raspbian GNU/Linux 10 (buster)"
NAME="Raspbian GNU/Linux"
VERSION_ID="10"
VERSION="10 (buster)"
VERSION_CODENAME=buster
ID=raspbian
ID_LIKE=debian
HOME_URL="http://www.raspbian.org/"
SUPPORT_URL="http://www.raspbian.org/RaspbianForums"
BUG_REPORT_URL="http://www.raspbian.org/RaspbianBugs"
```

Now launch the Raspberry Pi's System Configuration tool using the command:
```bash
sudo raspi-config
```

Set the following:
* `Interface Options`:
    * `Camera`: enable
    * `SPI`: enable
* `Localisation Options`:
    * `Locale`: arrow up and down through the list and select or deselect languages with the spacebar.
        * Deselect the default language option that is selected
        * Select `en_US.UTF-8 UTF-8` for US English
        * Use the `TAB` button to select `Ok` and press `ENTER`
        * On the next screen select `en_US.UTF-8` for the default locale
* You will also need to configure the WiFi settings if you are using the #1 option above to connect to the internet

When you exit the System Configuration tool, you will be prompted to reboot the system; allow the system to reboot and continue with these instructions.

Each command should be run individually,unless its specified as a multi-line command.
### Change the default password
Change the system's default password from the default "raspberry". Run the command:
```bash
passwd
```
You will be prompted to enter the current password ("raspberry") and then to enter a new password twice. In our prepared release image, the password used is `AirG@pped!`.

### Install python3.10
```bash
# install compiler dependencies; takes ~1 minute on a Pi Zero 1.3
# * openssl, libssl-dev: ssl support when pip fetches packages
# * libsqlite3-dev: required by `coverage`
sudo apt update && sudo apt install -y build-essential zlib1g-dev \
    libncurses5-dev libgdbm-dev libnss3-dev openssl libssl-dev \
    libreadline-dev libffi-dev wget libsqlite3-dev

# Grab the python3.10 source
wget https://www.python.org/ftp/python/3.10.10/Python-3.10.10.tgz
tar -xzvf Python-3.10.10.tgz
cd Python-3.10.10

# Takes ~6 minutes on a Pi Zero 1.3 to check what is available
./configure --enable-optimizations

# compiling takes ~80 minutes(!!) on a Pi Zero 1.3
sudo make altinstall

# cleanup
cd ..
sudo rm -rf Python-3.10.10*

# Make python3.10 the default version
sudo update-alternatives --install /usr/bin/python python /usr/local/bin/python3.10 1
sudo update-alternatives --install /usr/bin/python3 python3 /usr/local/bin/python3.10 1
```

Manually re-install `python3-apt` to avoid error messages in later steps (though, ironically, you will see the "ModuleNotFoundError: No module named 'apt_pkg'" error message during the `apt remove` step):
```bash
sudo apt remove --purge python3-apt -y
sudo apt autoremove -y
sudo apt install python3-apt -y
```

### Install dependencies
Copy this entire box and run it as one command (~15 minutes on a Pi Zero 1.3):
```bash
sudo apt update && sudo apt install -y wiringpi python3-pip \
   python-pil libjpeg-dev zlib1g-dev libopenjp2-7 \
   git python3-opencv python3-picamera libatlas-base-dev qrencode
```

### Install `zbar`
`zbar` is "an open source software suite for reading bar codes" (more info here: [https://github.com/mchehab/zbar](https://github.com/mchehab/zbar)).

SeedSigner requires `zbar` at 0.23.x or higher.

Download the binary:
```bash
curl -L http://raspbian.raspberrypi.org/raspbian/pool/main/z/zbar/libzbar0_0.23.90-1_armhf.deb --output libzbar0_0.23.90-1_armhf.deb
```

And then install it:
```bash
sudo apt install ./libzbar0_0.23.90-1_armhf.deb
```

Cleanup:
```bash
rm libzbar0_0.23.90-1_armhf.deb
```

### Install the [C library for Broadcom BCM 2835](http://www.airspayce.com/mikem/bcm2835/)
This library "provides functions for reading digital inputs and setting digital outputs, using SPI and I2C, and for accessing the system timers."

Run each of the following individual steps:
```bash
wget http://www.airspayce.com/mikem/bcm2835/bcm2835-1.60.tar.gz
tar zxvf bcm2835-1.60.tar.gz
cd bcm2835-1.60/
sudo ./configure
sudo make && sudo make check && sudo make install
cd ..
rm bcm2835-1.60.tar.gz
sudo rm -rf bcm2835-1.60
```

### Download the SeedSigner code:
```bash
git clone https://github.com/SeedSigner/seedsigner
cd seedsigner
```

### Adding swap space
Compiling the dependencies requires more RAM than is available on a Raspberry
Pi 3B, let alone a Zero. Temporarily adding 1GB of additional swap space will
work around this limitation. The `/swapfile` can be deleted after you reboot.

If building on a Raspberry Pi board with more than 1GB of RAM, this step can
be safely skipped.

```bash
sudo dd if=/dev/zero of=/swapfile bs=4096 count=$((1024*256))
sudo chmod 0600 /swapfile
sudo mkswap /swapfile
sudo swapon /swapfile
```

### Install Python `pip` dependencies:
```bash
# Takes 1hr 15min on a Pi Zero 1.3
python3 -m pip install -r requirements.txt

# Only takes ~100 seconds
python3 -m pip install -r requirements-raspi.txt
```

#### `pyzbar`
Note: The `requirements.txt` installs a fork of the python `pyzbar` repo.

The fork is required because the main `pyzbar` repo has been abandoned. This [github issue](https://github.com/NaturalHistoryMuseum/pyzbar/issues/124#issuecomment-971967091) discusses the changes needed in order to support reading binary data from `zbar`, which is required for our `CompactSeedQR` format which writes byte data instead of strings. The changes specifically reference the following PRs which have already been merged into Keith's fork:
* [PR 76](https://github.com/NaturalHistoryMuseum/pyzbar/pull/76/files): enables scanning to continue even when a null byte (`x\00`) is found.
* [PR 82](https://github.com/NaturalHistoryMuseum/pyzbar/pull/82): enable `zbar`'s new binary mode. Note that this PR has a trivial bug that was fixed in our fork.

### Optional: increase spidev buffer size
This allows `ST7789.py` to update the LCD without performing multiple write operations because the default buffer size is 4096 bytes. The default can be changed via the  `/boot/cmdline.txt` file. You will need to add `spidev.bufsiz=131072` to the end of this single lined file command.

Example `cmdline.txt` contents:
```
console=serial0,115200 console=tty1 root=PARTUUID=2fa4ba7e-02 rootfstype=ext4 elevator=deadline fsck.repair=yes rootwait modules-load=dwc2,g_ether spidev.bufsiz=131072
```

### Configure `systemd` to run SeedSigner at boot:

```bash
sudo nano /etc/systemd/system/seedsigner.service
```

Add the following contents to the text file that was created:  
If you are not using the username pi, then replace  `pi` in the service section below with your username. There are 3 lines to change.   
```ini
[Unit]
Description=Seedsigner

[Service]
User=pi
WorkingDirectory=/home/pi/seedsigner/src/
ExecStart=/usr/bin/python3 main.py > /dev/null 2>&1
Restart=always

[Install]
WantedBy=multi-user.target
```

_Note: For local dev you'll want to edit the `Restart=always` line to `Restart=no`. This way when your dev code crashes it won't keep trying to restart itself. Note that the UI "Reset" will no longer work when auto-restarts are disabled._

_Note: Debugging output is completely wiped via routing the output to `/dev/null 2>&1`. When working in local dev, you'll `kill` the `systemd` SeedSigner service and just directly run the code on demand so you can see all the debugging output live._

Use `CTRL-X` and `y` to exit and save changes.

Configure the service to start running (this will restart the seedsigner code automatically at startup and if it crashes):
```bash
sudo systemctl enable seedsigner.service
```

Now reboot the Raspberry Pi:
```bash
sudo reboot
```

After the Raspberry Pi reboots, you should see the SeedSigner splash screen and the SeedSigner menu subsequently appear on the LCD screen (note that it can take up to 60 seconds for the menu to appear).

#### Optional: kill `systemd` SeedSigner process on login
If you're going to be testing new code on the device, you'll find yourself often needing to kill the SeedSigner instance that `systemd` automatically runs at startup.

You can configure your `~/.profile` to find and kill the SeedSigner process when you ssh in.

`nano ~/.profile` and add at the end:
```bash
# Find the SeedSigner process and kill it
kill $(ps aux | grep '[m]ain.py' | awk '{print $2}')
```

### Further OS modifications
Disable and remove the system's virtual memory / swap file with the commands:

```bash
sudo apt remove dphys-swapfile -y
sudo apt autoremove -y
sudo rm /var/swap
```

## Manually start the SeedSigner code
```bash
cd ~/seedsigner/src

# You'll find the main.py file in that directory. Run it:
python main.py

# To kill the process, use CTRL-C
```

## Local testing and development

### Run specific branches or PRs
The default branch is `dev`. If you want to run a specific release tag or a specific branch:
```bash
# release tag for v0.6.0:
git checkout 0.6.0
```

And if you want to test a pull request (PR), for example PR #123:
```bash
git fetch origin pull/123/head:pr_123
git checkout pr_123
```

where `pr_123` is any name you want to give to the new branch in your local repo that will hold the PR.

### Change the host name
For those who will use the SeedSigner installation for testing/development, it can be helpful to change the system's host name so it doesn't potentially conflict with other Raspberry Pis that may already be present on your network. (For those who don't plan to use the installation for testing or development, you can skip this portion of the process.) To change the host name first edit the "hostname" with the command:

```bash
sudo nano /etc/hostname
```

and change "raspberrypi" to "seedsigner" (or another name). Use `CTRL-X` and `y` to exit and save changes.

You'll also need to edit the "hosts" file with the command:
```bash
sudo nano /etc/hosts
```

and change "raspberrypi" to "seedsigner" (or the other name you previously chose). Use `CTRL-X` and `y` to exit and save changes.

### Set a static IP
Your local machine that `ssh`s into the SeedSigner can sometimes get confused if you're connecting to different SeedSigners that are all identified as `pi@seedsigner.local`. In this case it helps to set a static ip and just `ssh` directly to that instead.

First find your current `nameserver`:
```bash
sudo cat /etc/resolv.conf
```

This is the address of your local machine that is connected to your SeedSigner via usb (or it'll be the wifi router's address if you're using a Raspi with wifi and are keeping it enabled for `ssh` access).

Set a static ip: `sudo nano /etc/dhcpcd.conf` and add to the end:
```
interface usb0
static ip_address=192.168.1.200/24
static routers=192.168.1.254
static domain_name_servers=192.168.1.254
```

* `interface` will be `usb0` for usb connections; `wlan0` for wifi.
* `static ip_address` is the ip address you want the SeedSigner to use. It should match the `nameserver` ip you found above for all but the last part of the ip (note: the `/24` should always be included as-is).
* `static routers` should be your `nameserver` ip.
* `static domain_name_servers` should also be the `nameserver` ip.

`CTRL-X` and `y` to save changes.

After your next reboot, access this SeedSigner using its new static ip:
```bash
# Use the static ip you set above:
ssh pi@192.168.1.200

# But the hostname will still work, too:
ssh pi@seedsigner.local
```

### More convenient `ssh` access:
Power SeedSigner devs will find themselves connecting to a lot of different SeedSigners. This can cause headaches with `ssh`'s built-in protections; a different device that uses the same `ssh` credentials is normally a potential spoofing attack. But we're doing this to ourselves on purpose and so we can carve out exceptions.

On your local machine, run `nano ~/.ssh/config` and add to the end:
```conf
host seedsigner.local
 StrictHostKeyChecking no
 UserKnownHostsFile /dev/null
 User pi
 LogLevel QUIET

# Set this to the static ip you set above:
host 192.168.1.200
 StrictHostKeyChecking no
 UserKnownHostsFile /dev/null
 User pi
 LogLevel QUIET
```

The first entry prevents warnings for the default `pi@seedsigner.local` connections.

The second entry does the same for a specific static ip; you'll want this if you configure all your SeedSigners to use the same static ip.

`CTRL-X` and `y` to save changes.

#### Bypass `ssh` password
You can also configure the SeedSigner so that you don't have to enter the `pi` password when you `ssh` in.

run `ssh-copy-id` with the same values that you connect via `ssh`:
```bash
ssh-copy-id pi@seedsigner.local

# or if you're connecting over static ip, something like:
ssh-copy-id pi@192.168.1.200
```

You'll be prompted to enter the password to complete it.

_Note: If you don't have any ssh keys on your local machine, you'll need to create a set with `ssh-keygen -t ed25519 -C "your_email@example.com"`. Then try running `ssh-copy-id` again._

## Disable wifi/Bluetooth when using other Raspi boards
If you plan to use your installation on a Raspberry Pi that is not a Zero version 1.3, but rather on a Raspberry Pi that has WiFi and Bluetooth capabilities, it is a good idea to disable the following WiFi & Bluetooth, as well as other relevant services (assuming you are not creating this installation for testing/development purposes). Enter the followiing commands to disable WiFi, Bluetooth, & other relevant services:
```bash
sudo systemctl disable bluetooth.service
sudo systemctl disable wpa_supplicant.service
sudo systemctl disable dhcpcd.service
sudo systemctl disable sshd.service
sudo systemctl disable networking.service
sudo systemctl disable dphys-swapfile.service
sudo ifconfig wlan0 down
```

Please note that if you are using WiFi to connect/interact with your Raspberry Pi, the last command will sever that connection.

You can now safely power the Raspberry Pi off from the SeedSigner main menu.

If you do not plan to use your installation for testing/development, it is also a good idea to disable WiFi and Bluetooth by editing the config.txt file found in the installation's "boot" partition. You can add the following text to the end of that file with any simple text editor (Windows: Notepad, Mac: TextEdit, Linux: nano):
```ini
dtoverlay=disable-bt
dtoverlay=pi3-disable-wifi
```

If you used option #2 above and don't plan to continue to access your SeedSigner via SSH over USB, it is a good idea to reverse the steps you took to enable it -- those instructions can be found near the end of [this guide](usb_relay.md).

Please remember that it can take up to a minute for the GUI to appear when powering your SeedSigner on.

### Optional: Run the tests
see: [tests/README.md](../tests/README.md)

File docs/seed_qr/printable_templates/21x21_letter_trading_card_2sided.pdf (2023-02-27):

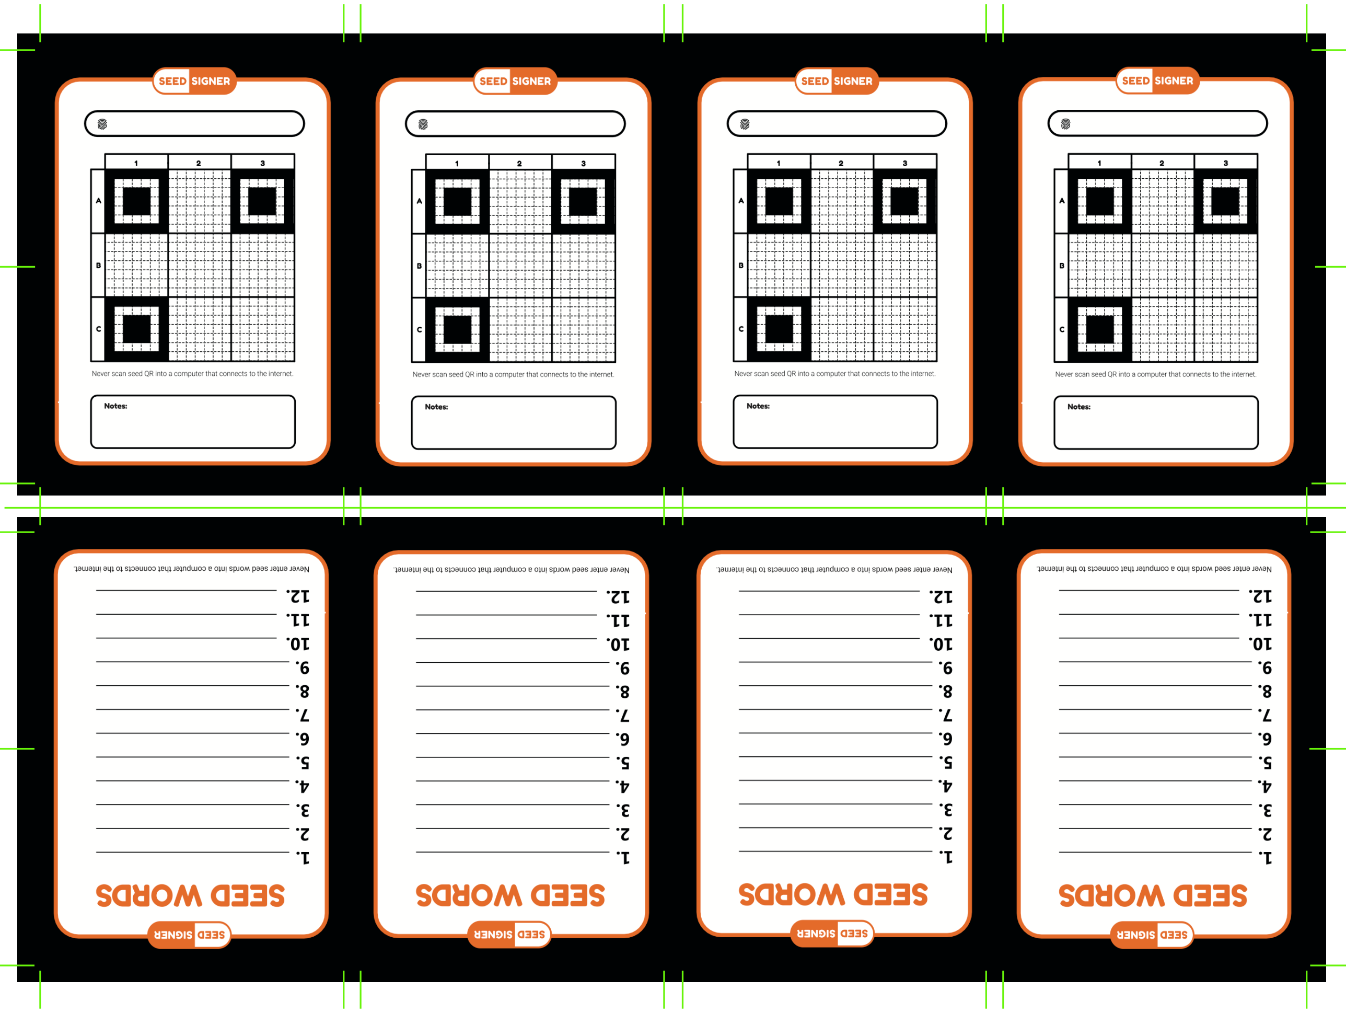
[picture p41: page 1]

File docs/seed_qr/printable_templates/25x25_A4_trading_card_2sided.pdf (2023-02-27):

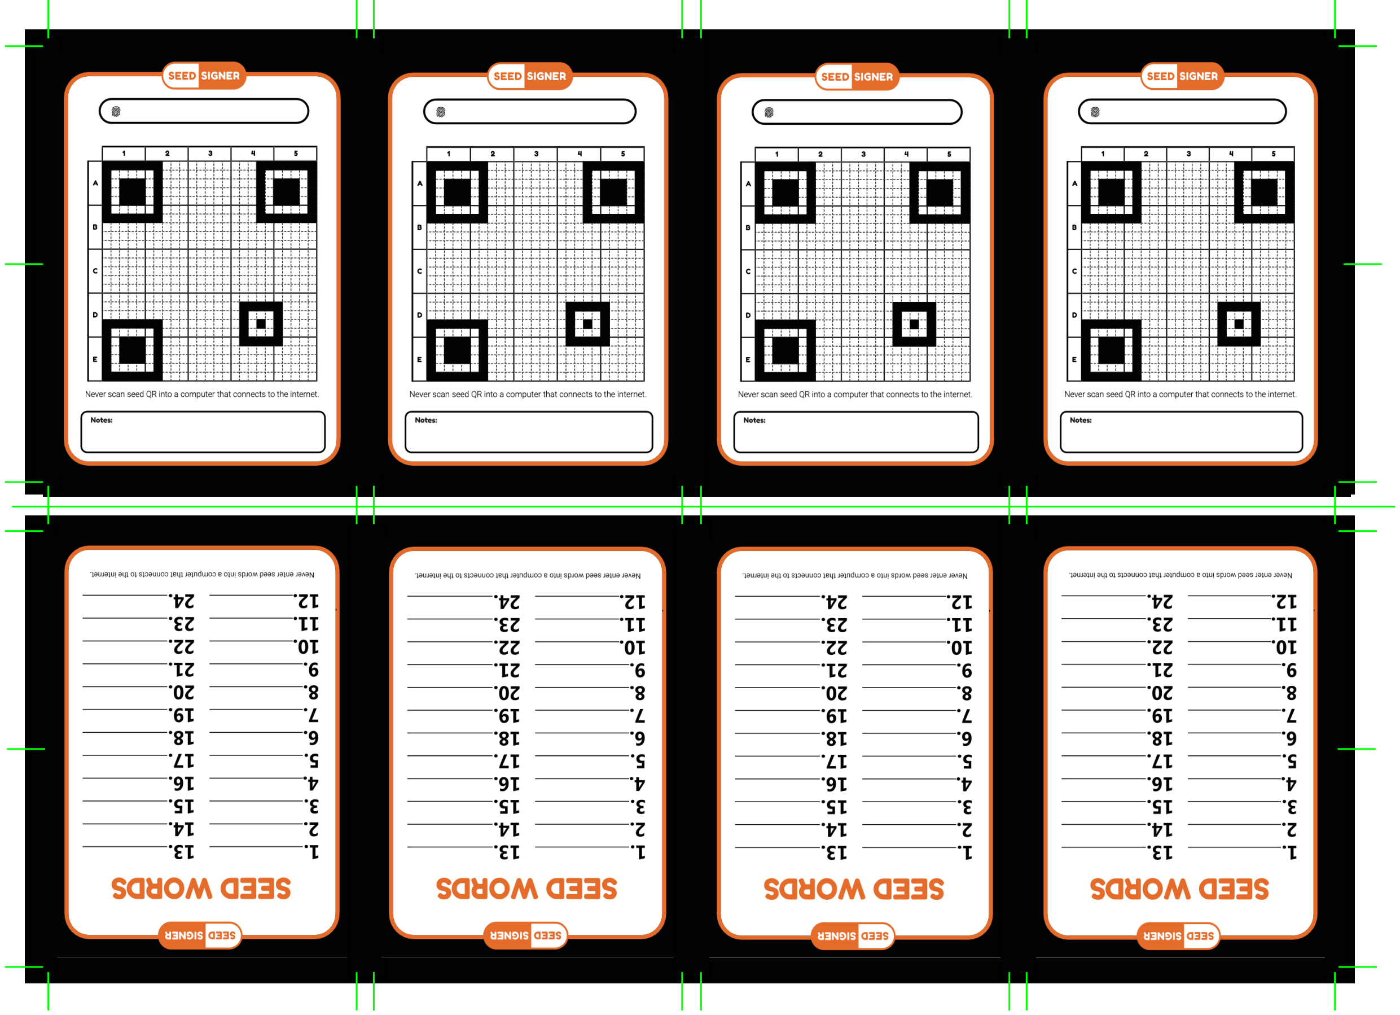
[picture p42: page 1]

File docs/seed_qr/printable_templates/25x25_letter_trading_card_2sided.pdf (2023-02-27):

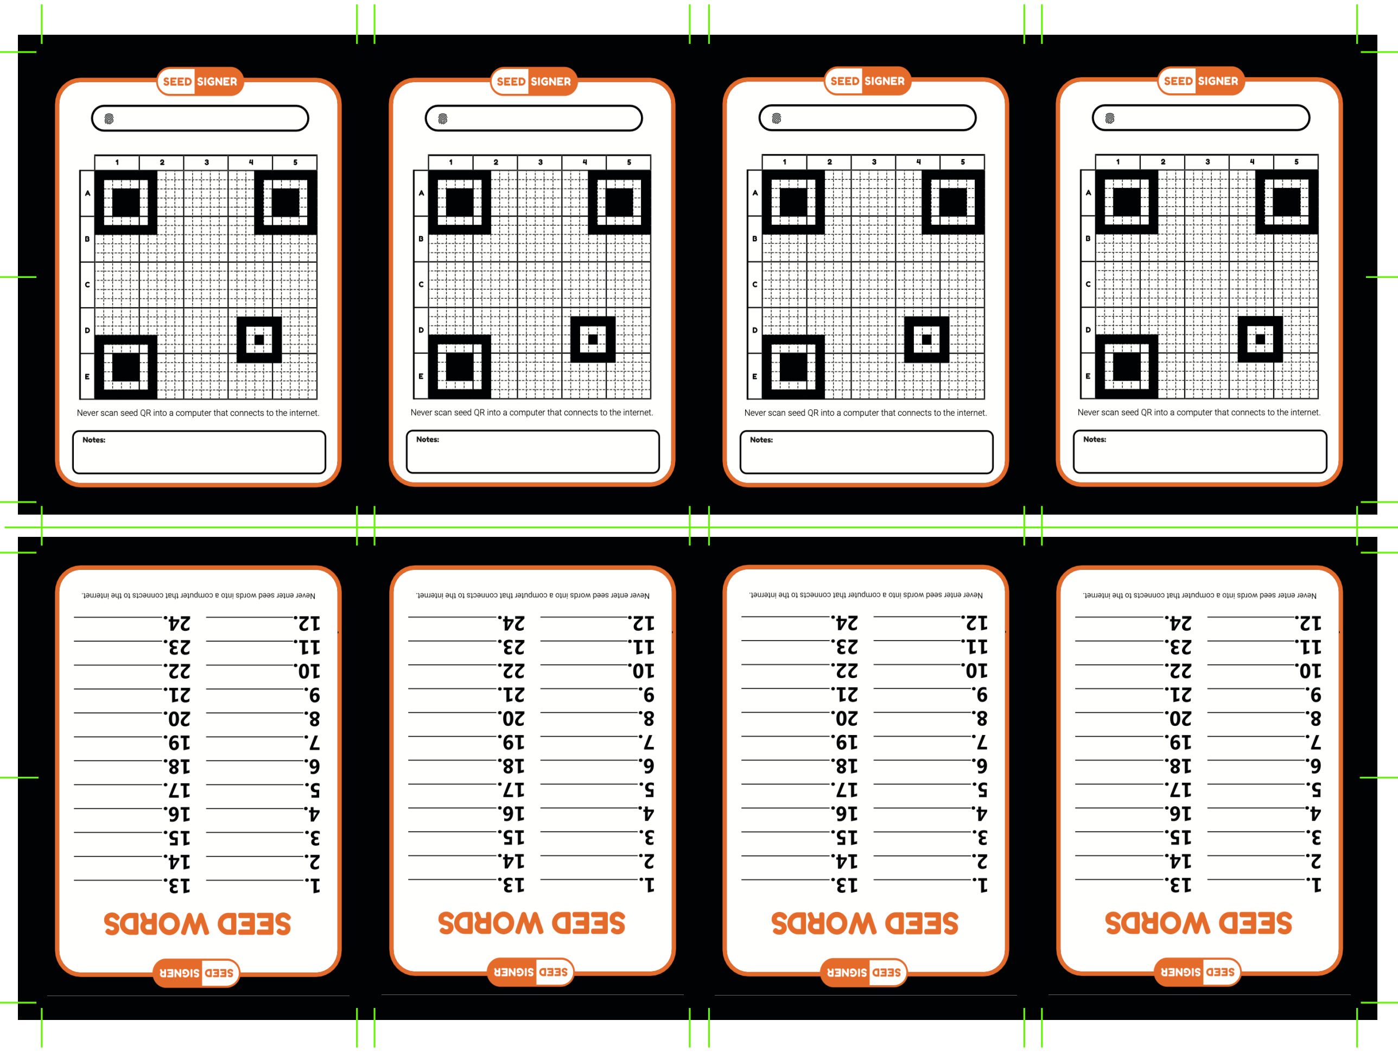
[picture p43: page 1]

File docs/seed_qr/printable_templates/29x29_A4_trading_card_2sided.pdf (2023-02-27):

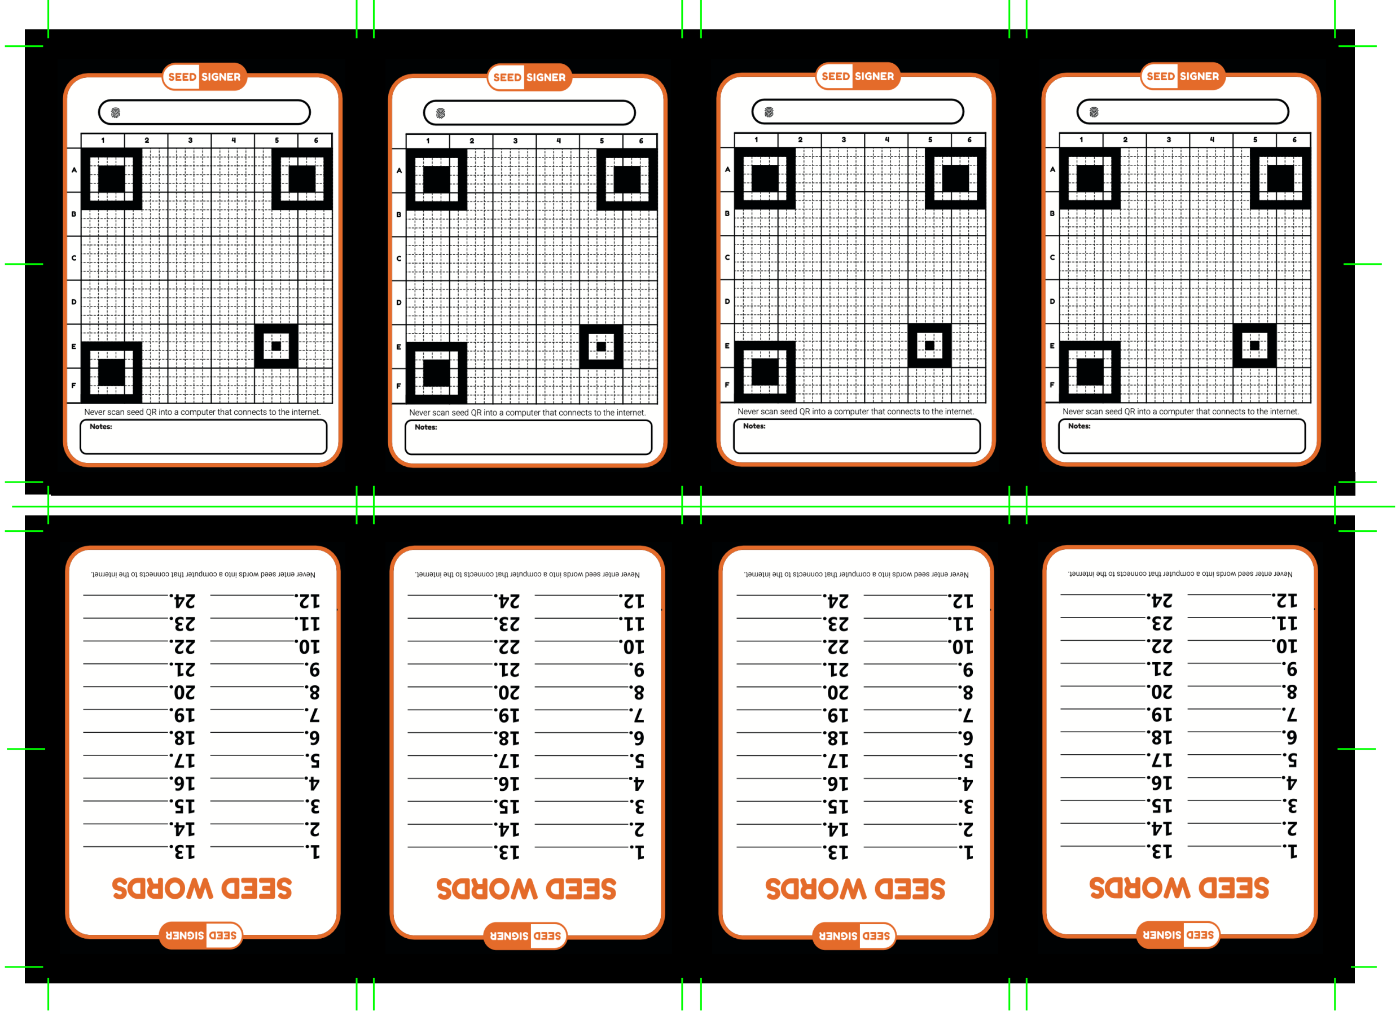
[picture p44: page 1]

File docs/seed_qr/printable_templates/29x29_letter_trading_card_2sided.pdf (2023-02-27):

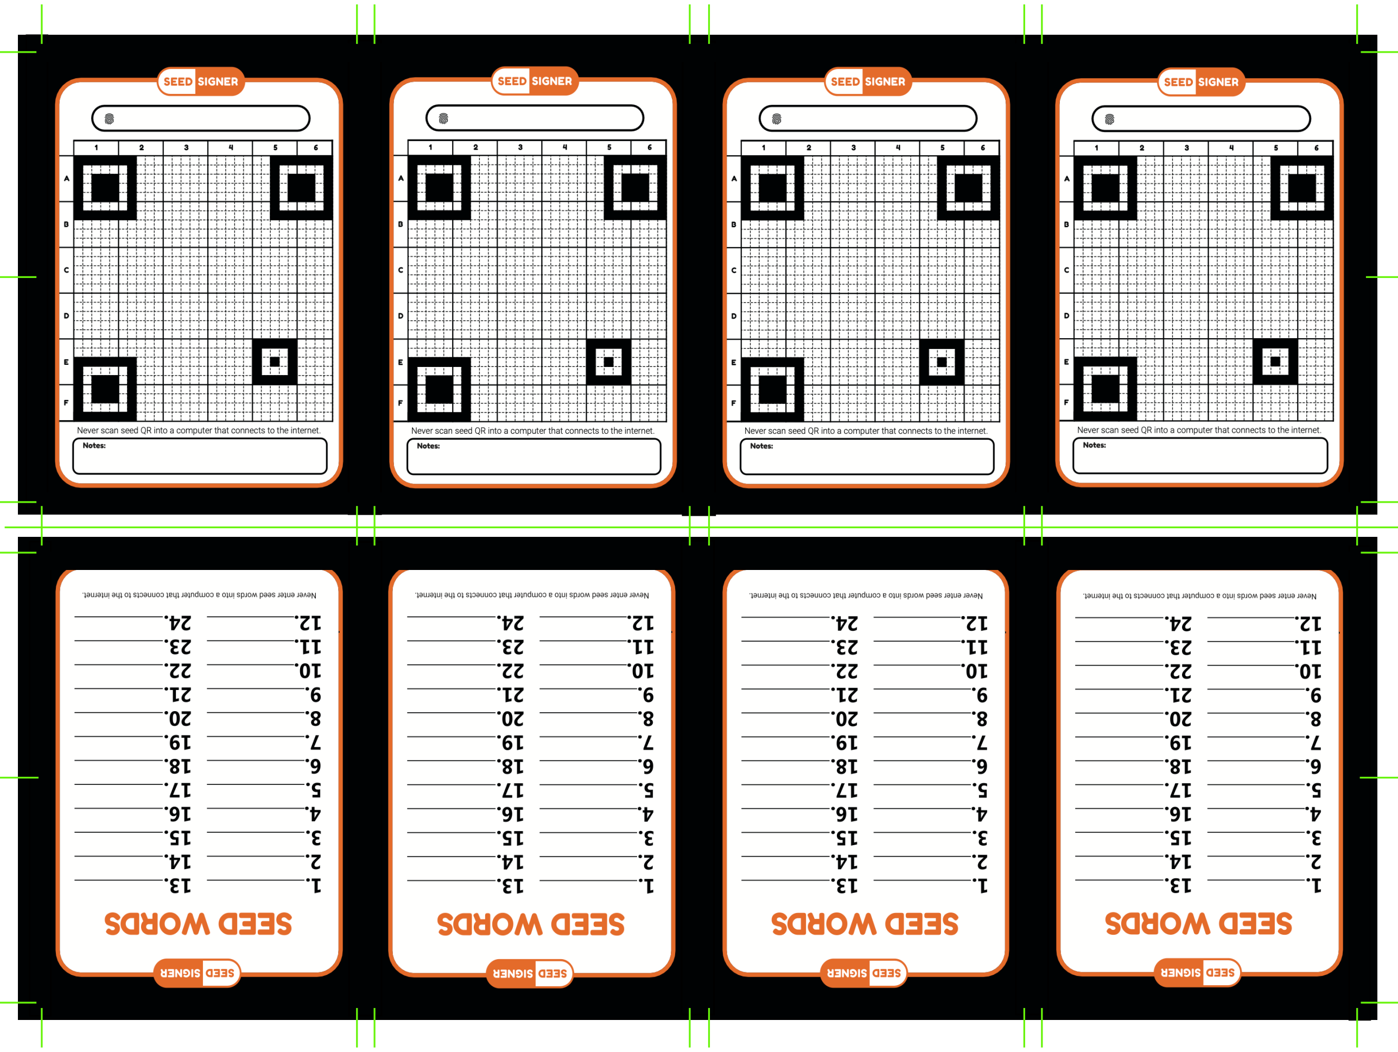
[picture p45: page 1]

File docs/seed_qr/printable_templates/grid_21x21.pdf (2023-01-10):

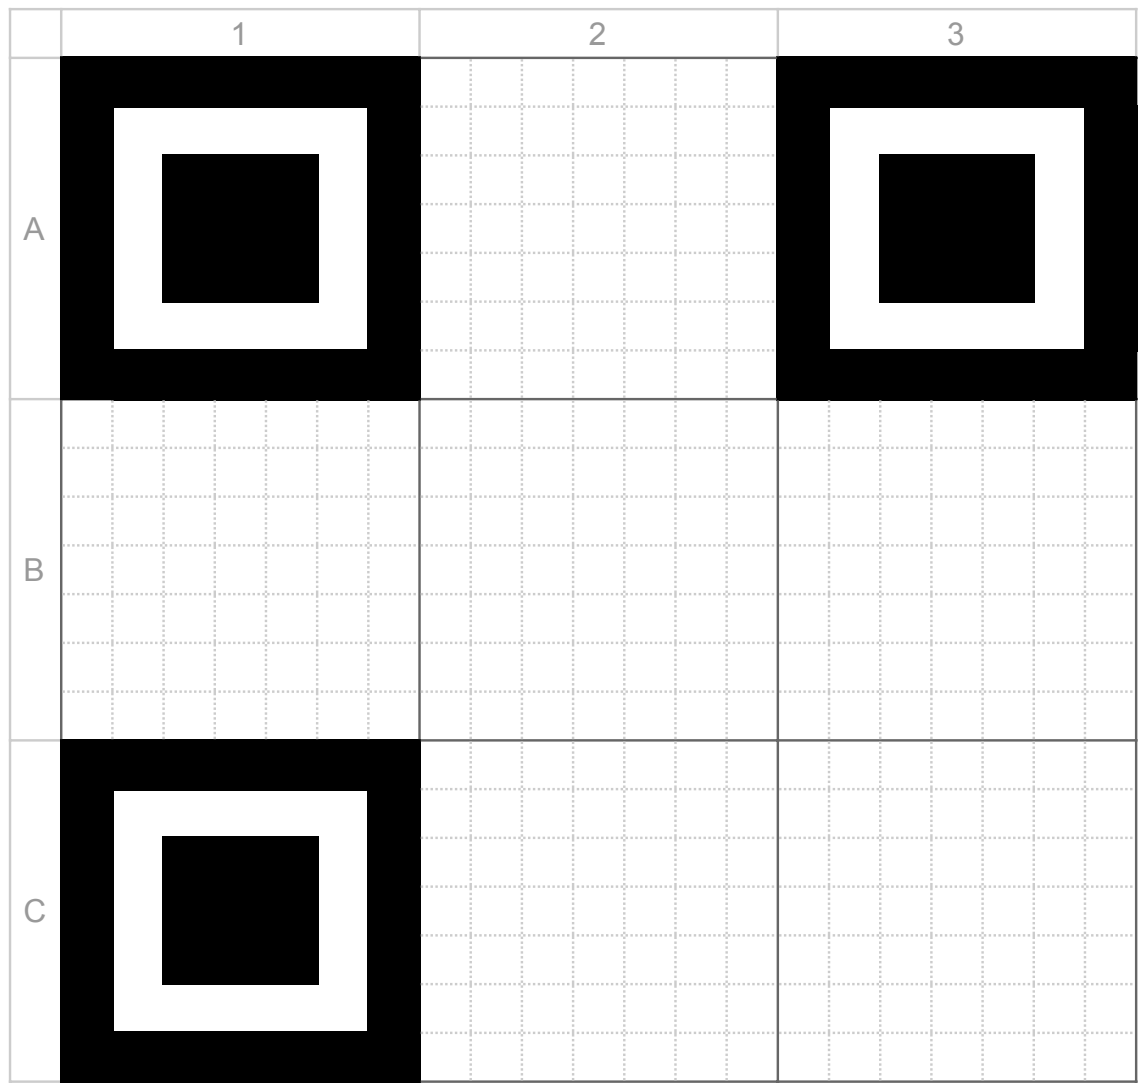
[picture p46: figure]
ABC

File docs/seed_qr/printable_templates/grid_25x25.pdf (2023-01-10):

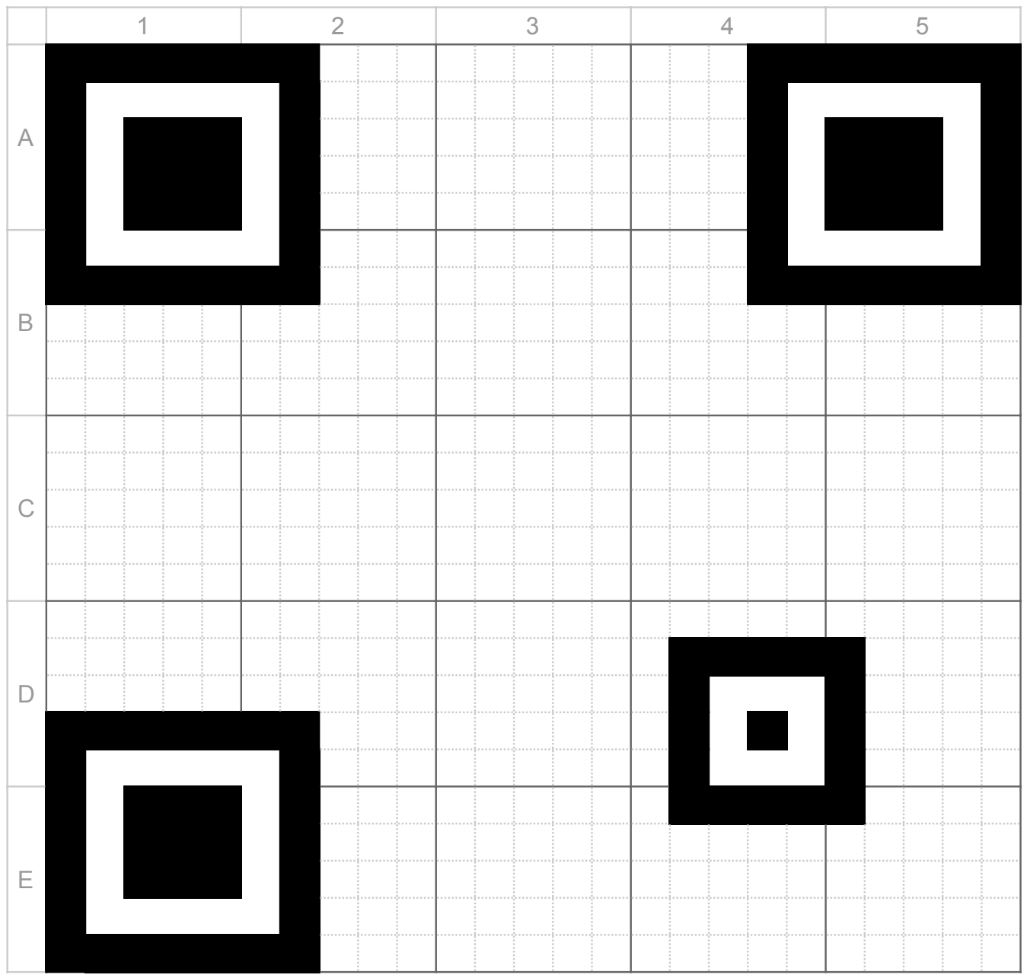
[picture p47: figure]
ABCDE

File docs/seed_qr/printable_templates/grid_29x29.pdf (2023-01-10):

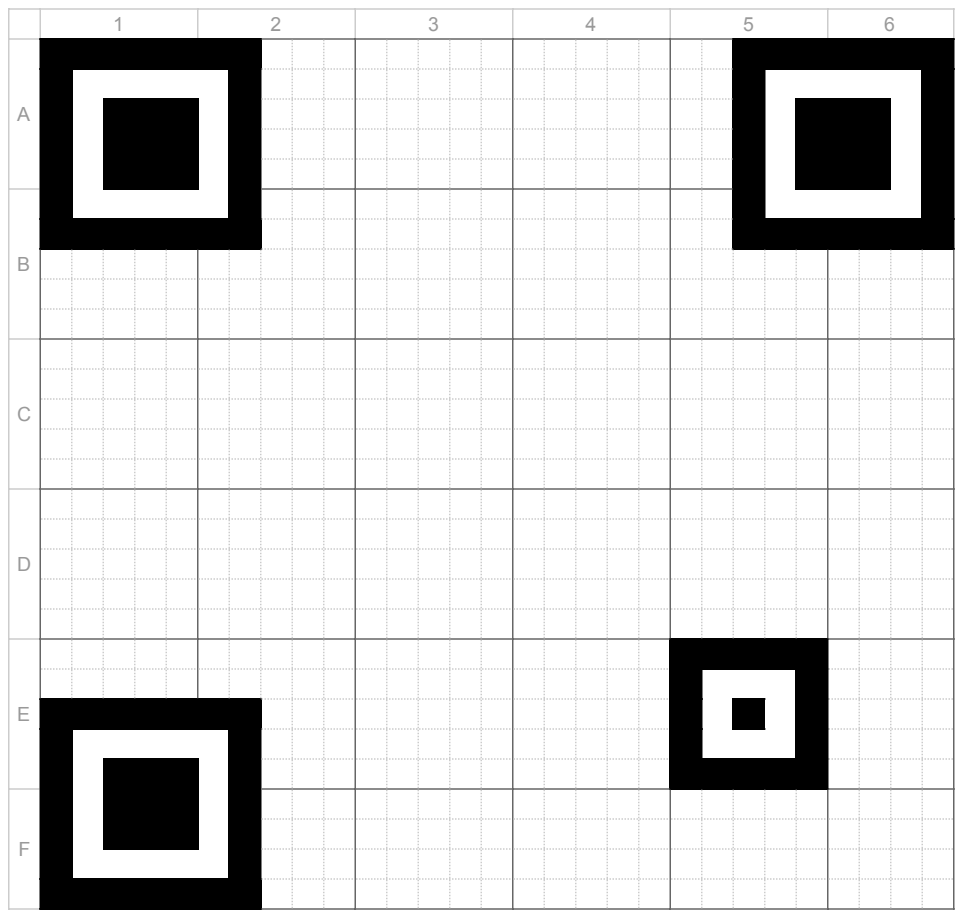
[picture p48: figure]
ABCDEF

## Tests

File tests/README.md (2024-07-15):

# Running Tests

The tests are designed to be run on non-Raspi hardware.

On your testing machine you'll have to install:
```bash
# general dependencies
pip3 install -r requirements.txt

# test suite dependencies
pip3 install -r tests/requirements.txt
```

Then make the `seedsigner` python module visible/importable to the tests by installing it:
```
pip3 install -e .
```

Run the whole test suite:
```
pytest
```

Run a specific test file:
```
pytest tests/test_this_file.py
```

Run a specific test:
```
pytest tests/test_this_file.py::test_this_specific_test
```

Force pytest to show logging output:
```bash
pytest tests/test_this_file.py::test_this_specific_test -o log_cli=1

# or (same result)

pytest tests/test_this_file.py::test_this_specific_test --log-cli-level=DEBUG
```

Annoying complications:
* If you want to see `print()` statements that are in a test file, add `-s`
* Better idea: use a proper logger in the test file and use one of the above options to display logs

### Test Coverage
Run tests and generate test coverage
```
coverage run -m pytest
```

Show the resulting test coverage details:
```
coverage report
```

Generate the html overview:
```
coverage html
```

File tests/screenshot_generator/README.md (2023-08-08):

# Screenshot Generator

From the project root, run:
```
pytest tests/screenshot_generator/generator.py
```

Writes the screenshots to a dir in the project root: `seedsigner-screenshots`.

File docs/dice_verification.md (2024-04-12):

# Verifying dice seed generation 

The intention of this documentation is to describe how to verify the seed generation code used in SeedSigner against other independent tools, to prove that they all generate the same results, despite them using different programming languages and code libraries.<br><br>
As it is an important step to verify all software releases being used to ensure that the installation files downloaded have not been compromised, the same is true especially for the seed generation procedure which unknowingly might not work as expected due to bugs or even on purpose.<br><br>
This guide describes how this can be achieved.<br><br>
As usual: Don't Trust, Verify!<br>
<br><br>
**Note:**<br>
**Do NOT use this with any seed you want to use later with real funds. This exercise is only for checking that the independent codebases get to the same end result!**<br>
**However, if you do want to check your real seedphrases you should download the Iancoleman and/or Bitcoiner.Guide tools onto an airgapped, ephemeral computer (e.g. using tails-OS) and perform these tests on there. Destroy/abandon the TailsOS afterwards.**<br>
**Never input seed phrases that you intend to use to store real funds onto an internet-connected computer!!!**
<br><br><br>

## 99 Dice Rolls / 24 Seed Words Example

The following 99 dice roll results are used in the verification steps as an example for a 24 words seed:<br>
> 655152231316521321611331544441236164664431121534415633526456254462245546236542364246312613322234612

The corresponding 24 seed words are:<br>
> eyebrow obvious such suggest poet seven breeze blame virtual frown dynamic donor harsh pigeon express broccoli easy apology scatter force recipe shadow claim radio

(Scroll down near the end to see result values for a 50 dice rolls / 12 seed words example)
<br><br><br>

## Creating seed via Dice rolls in SeedSigner (here v0.6.0)

First we create a new seed based on dice rolls in SeedSigner:<br><br>
Power on your SeedSigner, go to the 'Tools' menu and select 'New Seed' (with the dice symbols):<br>
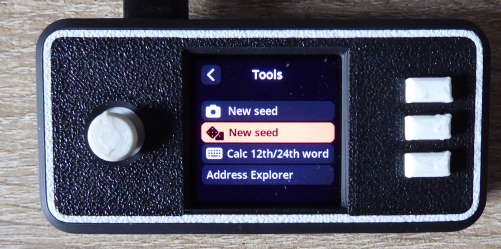
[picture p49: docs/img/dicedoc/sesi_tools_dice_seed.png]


Select '24 words (99 rolls)' and on the next screen enter the dice numbers one after another:<br>
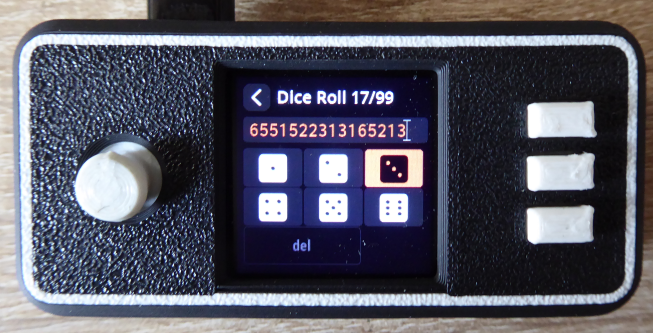
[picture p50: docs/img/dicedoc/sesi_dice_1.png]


Go on until the end (99 dice roll numbers):<br>
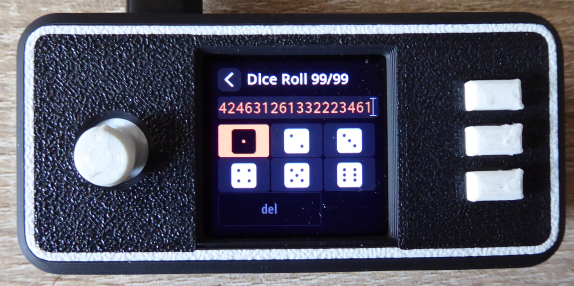
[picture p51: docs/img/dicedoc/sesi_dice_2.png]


After that the 24 seed words are shown (in 6 screens of 4 words each):<br>
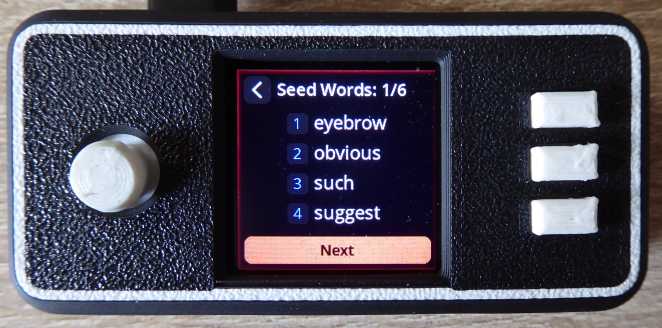
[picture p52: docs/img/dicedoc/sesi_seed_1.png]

<br>**.....**<br>
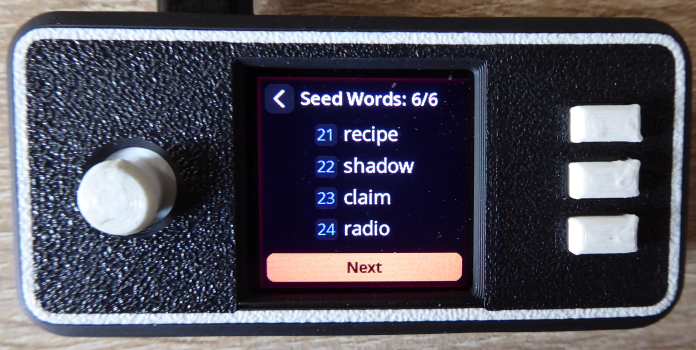
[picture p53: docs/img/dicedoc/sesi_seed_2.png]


The fingerprint for this seed is:<br>
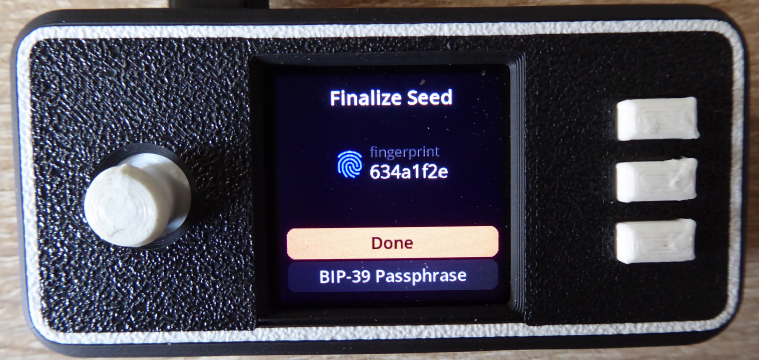
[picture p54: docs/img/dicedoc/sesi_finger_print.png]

<br><br><br>
Having now created a dice-based seed in the SeedSigner, we will go on to compare those details to what appears in the:
* Sparrow desktop wallet software
* Ian Coleman's Mnemonic Code Converter website
* Seed Tool website

We will create a wallet to have the complete zpub and receive/change addresses to check against the two web pages.<br>
SeedSigner currently supports BlueWallet, Nunchuk, Sparrow and Specter Desktop. Here we will use Sparrow wallet as an example.<br>

Keep the SeedSigner open and the newly created seed still loaded as we will need it in the next step.
<br><br><br>

## Create new wallet from seed in Sparrow Wallet to see xpub/zpub and addresses

Go to https://www.sparrowwallet.com/download/ and download the release version supported by your operating system.<br><br>
Open Sparrow Wallet, go to 'File' menu and select 'New Wallet'. Enter a name (e.g. test), and click 'Create Wallet'.<br><br>
Click 'Airgapped Hardware Wallet' (1) and click on the 'Scan' button in the SeedSigner entry (2) which will open the camera scan screen:<br>
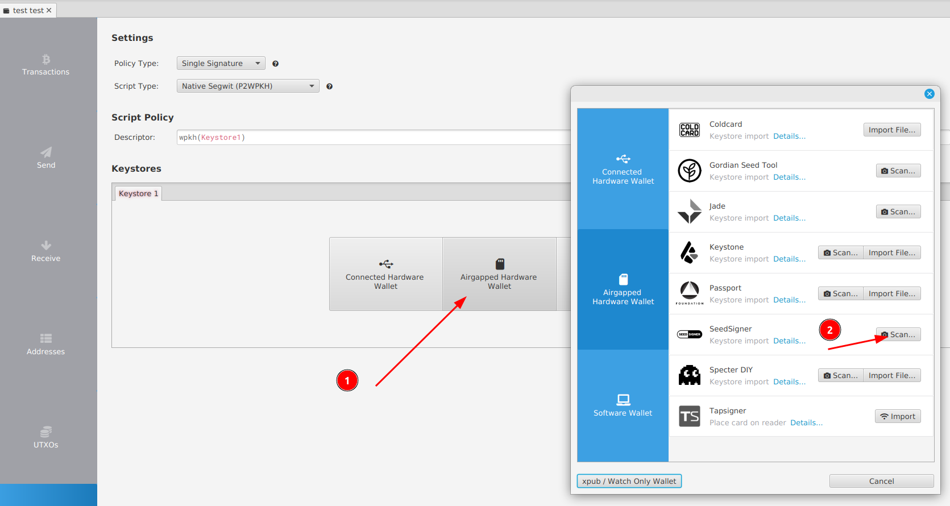
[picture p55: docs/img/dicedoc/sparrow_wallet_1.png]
<kbd></kbd>

On SeedSigner go to the seed just created and click 'Export Xpub':<br>
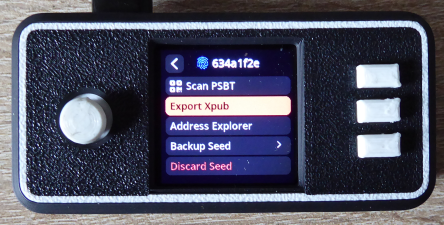
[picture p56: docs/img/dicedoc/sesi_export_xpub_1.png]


Follow these menu entries in SeedSigner:<br>
> Export Xpub --> Single Sig --> Native Segwit --> Sparrow<br>

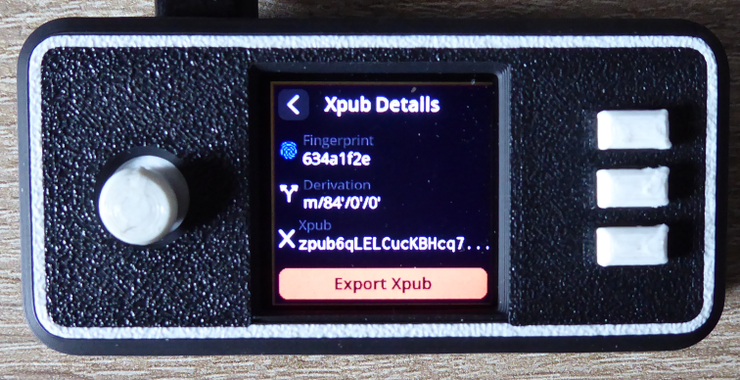
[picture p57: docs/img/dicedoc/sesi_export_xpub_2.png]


Click 'Export Xpub' and SeedSigner will show an animated QR code to be scanned in Sparrow Wallet (where we are still in the wallet creation).<br>
Scan the QR code SeedSigner is showing in Sparrow Wallet.<br><br>
The wallet has now been created in Sparrow. Click 'Apply' button to finalize. The wallet's settings screen now looks like this:<br>
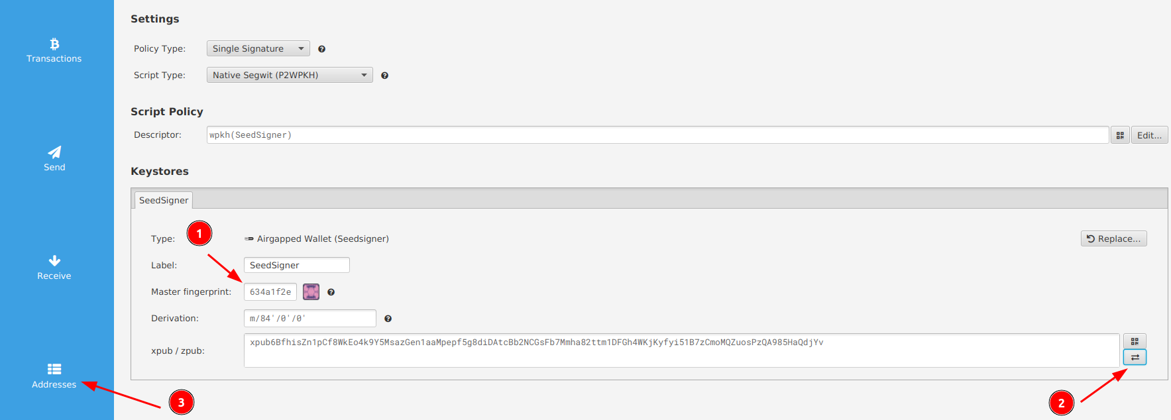
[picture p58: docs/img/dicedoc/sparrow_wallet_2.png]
<kbd></kbd>

We will later use this to verify: (1) fingerprint, (2) zpub (click this button to switch between xpub and zpub!) and (3) addresses on the 'Addresses' tab.
<br><br><br>

## Verifying with Ian Coleman BIP39 website

Go to https://iancoleman.io/bip39 and check 'Show entropy details' (1):<br>
<kbd></kbd>

<br>
Make sure to check (1) 'Hex' and (2) '24 Words' as 'Mnemonic Length'.<br>
(Do not use 'dice' format because dice 6 will be replaced by 0).<br>
Then enter the 99 dices numbers in (3). The corresponding seed words are shown in (4):<br>
<kbd></kbd>
<br><br>
The 24 seed words are the same in SeedSigner and the Ian Coleman tool.
<br><br>

### Verification of (1) fingerprint, (2) zpub and (3) generated addresses
**Fingerprint:**<br>
Fingerprint is not shown in the Ian Coleman tool (so cannot be verified here)
<br><br>
**Zpub:**<br>
Scroll down to the 'Derivation Path' section, click on the 'BIP84' tab (1) and find the zpub in (2):
<kbd></kbd><br><br>
Compare to zpub in Sparrow:<br>
<kbd></kbd>
<br>

Zpub is the same as shown in SeedSigner and Sparrow wallet.
<br><br>
**Addresses:**<br>
Scroll down to the 'Derived Addresses' section and compare the receive addresses to the ones generated in Sparrow ('Addresses' tab of the wallet):
<kbd></kbd>
<br>

Check that the receive addresses all match.<br><br>
To verify the change addresses, change 'External / Internal' to 1 (1):
<kbd></kbd><br><br>
Compare the change addresses to the ones generated in Sparrow ('Addresses' tab of the wallet):
<kbd></kbd>
<br>

Check that the change addresses all match.
<br><br><br>

## Verifying with Seed Tool website

Go to https://bitcoiner.guide/seed/ and click on 'Seed Generation Input' (1):<br>
<kbd></kbd>

Then click on the 'Show the Entropy Section' tab (1):<br>
<kbd></kbd>

Enter the 99 dice numbers in (1), in (2) change back to 'Hex', check that (3) is still '24 Words' and the calculated seed words are shown in (4):<br>
<kbd></kbd>

Seed words shown are the same as in SeedSigner and the Ian Coleman web tool seen before.
<br><br>

### Verification of (1) fingerprint, (2) zpub and (3) generated addresses

**Fingerprint:**<br>
Fingerprint can be seen here (1): <br>
<kbd></kbd><br><br>
**Zpub:**<br>
Scroll down to the 'Derived Addresses' section (1), click on it, make sure that '84' is selected for 'Purpose' (2) and check the zpub at (3):<br>
<kbd></kbd><br><br>
Compare to zpub in Sparrow:<br>
<kbd></kbd>
<br>

Zpub is the same as shown in SeedSigner, Sparrow and Ian Colemand tool.
<br><br>
**Addresses:**<br>
Scroll down a little bit where the receive addresses are shown and compare to the ones generated in Sparrow ('Addresses' tab of the wallet):<br>
<kbd></kbd>
<br>

Check that the receive addresses all match.<br><br>
To verify the change addresses, change the 'Receive/Change' dropdown box to '1 (Change)' (1):
<kbd></kbd><br><br>
Compare the change addresses to the ones generated in Sparrow ('Addresses' tab of the wallet):
<kbd></kbd>
<br>

Check that the change addresses all match.
<br><br><br>

## 50 Dice Rolls / 12 Seed Words Example

SeedSigner supports the creation of mnenomic seeds both with 12 or 24 seed words corresponding to 50 or 99 dice rolls. Below are some example result values for using 50 dice rolls only.<br><br>
All the steps shown can be executed the same way, just select the '12 words (50 rolls)' option in SeedSigner and change the 'Mnenomic Length' dropdown boxes in both web tools to '12 Words'.<br><br>

50 dice roll results as an example for a 12 words seed:<br>
> 65515223131652132161133154444123616466443112153441

The corresponding 12 seed words are:<br>
> hole luggage safe present express tragic orbit shed switch metal identify path

Fingerprint:<br>
> 8d9cced8

Zpub:<br>
> zpub6qf9ziL759pzyhKMWaPfNSiCETkoA6oq3fbCDvXqcURiMtPnkEg3nH93W5mrSkvGPoJC9xTYZheYDsYoiYc5AkSk9iY3DkCJHkFgHMdijW6

Addresses:<br>
Receive:<br>
> bc1q00lln3r4mt4uwvg7mxv96xgpewauwmggkex2ff<br>
> bc1q0jj2cv965f3642mv4lgq5za80jtfpkd0jhjefr<br>
> bc1qpecssejm2678v0rknk9tsxd5fsshezfr0vr5m5<br>
> bc1qcsl37xn5rkfz8qhcfwq5u52acxecyyfz0kv4gh<br>
> bc1q8ehx53re0wck4m9tzek8mlnctp2ztm7jq94zm4<br>
> ...<br>

Change:<br>
> bc1qz0ckhg3m349qpmweyn5v6r6tvx2wfw4nv8h75q<br>
> bc1qme5tu2t424ws3z69u445q0yw88vpc7fwygra4r<br>
> bc1qznuyuc087ky7fhv4nvlmll4p586ks4ggcyt36d<br>
> bc1qjcqxv22j0g00pehruwwh34sw5znu6vp3myaspy<br>
> bc1q6dpfl7czd22wt0max6p09vr6lvvpag7xw9u8lc<br>
> ...

<br><br>
## Conclusion

What did we achieve now?<br>

We created a dice-based seed in SeedSigner and set up a wallet using this seed in Sparrow wallet (as this is what a seed is used for).<br><br>
We double-checked in two different web tools implementing different methods for seed creation that what SeedSigner generates perfectly matches up with what the other tools calculate based on the same dice entropy used.<br>

So congratulations if the fingerprints, zpubs and addresses all match up in your example so you can be much more confident that nothing is wrong with your generated seed.

---

# Command Line Tool
_(for more advanced/python-savvy users)_

Run the exact same SeedSigner mnemonic generation code from the command line to quickly test and externally verify the results.

Create a python virtualenv (out of the scope of this doc) and install dependencies:
```bash
pip3 install embit

# Install the main project code to make it importable
pip3 install -e .
```

Then run the utility script with `-h` to view the usage instructions:
```bash
cd tools
python3 mnemonic.py -h
```

```
    Verify SeedSigner's dice rolls and coin flip entropy-to-mnemonic conversion via this tool.

    Compare its results against iancoleman.io/bip39 and bitcoiner.guide/seed

    Usage:
        # 50 dice rolls / 12-word mnemonic
        python3 mnemonic.py dice 5624433434...
        
        # 99 dice rolls / 24-word mnemonic
        python3 mnemonic.py dice 6151463561...

        # 50 dice rolls, entered as 0-5 / 12-word mnemonic
        python3 mnemonic.py --zero-indexed-dice dice 5135535514...

        # 128 coin flips / 12-word mnemonic
        python3 mnemonic.py coins 1111100111...

        # 256 coin flips / 24-word mnemonic
        python mnemonic.py coins 0010111010...

        # GENERATE 50 random dice rolls / 12-word mnemonic
        python3 mnemonic.py dice rand12

        # GENERATE 99 random dice rolls / 24-word mnemonic
        python3 mnemonic.py dice rand24

        # GENERATE 99 random dice rolls, entered as 0-5 / 24-word mnemonic
        python3 mnemonic.py --zero-indexed-dice dice rand24

        # GENERATE 128 random coin flips / 12-word mnemonic
        python3 mnemonic.py coins rand12

        # GENERATE 256 random coin flips / 24-word mnemonic
        python3 mnemonic.py coins rand24
```

### How to get the same results in iancoleman.io
Always specify your expected length in the "Mnemonic Length" droplist (defaults to "Use Raw Entropy (3 words per 32 bits)").

Dice Rolls: Do NOT use the "Dice [1-6]" option; select "Base 10 [0-9]" or "Hex [0-9A-F]"

Zero-indexed dice rolls: Select "Base 6 [0-5]", "Base 10 [0-9]", or "Hex [0-9A-F]"

Coin Flips: Select "Binary [0-1]", "Base 6 [0-5]", "Base 10 [0-9]", or "Hex [0-9A-F]"

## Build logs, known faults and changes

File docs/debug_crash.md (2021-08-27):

## Debugging a Crash for advanced (technical) users

These instructions are intended to help users of SeedSigner provide crash exception and traceback logs to developers to aid in troubleshooting and resolving bugs.

### Testnet vs Mainnet

Whenever possible recreate a crash in testnet. This will help avoid accidently revealing private information about yourself, your bitcoin transactions, or lose any funds.

### Network connected SeedSigner

If you are using SeedSigner for development and testing, then I recommend network access via ssh to view crash logs. Follow [these](https://github.com/SeedSigner/seedsigner/blob/main/docs/usb_relay.md) instructions to setup a USB relay for internet access. You can also connect your SeedSigner to Wifi if you have a rasp pi zero w/ wifi.

### Airgapped debugging setup

If you are using SeedSigner for mainnet transactions, then do not connect your device to a network or the internet. Instead connect your SeedSigner to a HDMI display (without internet) and a USB keyboard. This will require an HDMI adapter and micro USB to USB A adapter. Plug in the HDMI display and keyboard before powering on SeedSigner. The password for the SeedSigner pi user is `raspberry`.

### Debugging steps

At this point you should be signed into the pi user either on a HDMI display (via command line) or a ssh connection.

Follow these steps to setup a debug session.

`cd seedsigner/src`

`nano settings.ini`

in nano editor change `debug = False` to `debug = True` (case sensitive). Save and exit settings.ini.

stop the seedsigner systemd process by running

`sudo systemctl stop seedsigner.service`

now start the python app manually by running

`python3 main.py`

SeedSigner should now be up and running. Keep it connected to the display and keyboard. Recreate the steps to cause the crash. The traceback log and exception will be displayed on the HDMI display.

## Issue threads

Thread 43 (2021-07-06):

[Feature] Add SeedXOR support

kdmukai, 2021-07-06:
see: https://seedxor.com/

Concept by nvk/Coldcard. Split a 24-word seed into 2+ 24-word seeds via bitwise XOR. Each resulting seed is completely valid but the "true" wallet can only be recovered with all `n` seeds.

An interesting security option especially for our unique flow of scanning seed QR codes. After creating the 2+ new seeds as QR codes, scanning both would take almost no additional time. Since each seed is valid in their own right, decoy funds can be deposited on them. This way if an attacker steals or forces someone to give up their seed, they'll only get the decoy funds without realizing that the main stash is XOR'ed with n+ other seeds.

Certainly not a mainstream use case, but adds a fascinating security wrinkle for the rare edge cases that might want it.

Coldcard implementation here:
https://github.com/Coldcard/firmware/blob/0661b80cbdd079816f138b6f1fd64955d5048d7c/shared/xor_seed.py

david-bakin, 2021-11-27:
Not sure why you don't consider it a mainstream use case - it _could_ be one as an alternative to seed words + passphrase - just depends on user's _preference_ on how to handle 2-part secrets to access wallet - and as pointed out, works _really well_ with SS (cross reference to #17).

openoms, 2021-11-27:
Agree with aiming to make the seed XOR usage more mainstream.
See how it is by far the simplest solution in creating a secure redundant 2of3 setup from a single key: https://github.com/openoms/bitcoin-tutorials/blob/master/backups/seedxor.md

dipunm, 2022-05-31:
Seed XOR for me is interesting because for inheritance, most of the multi-part security management can be done offline without a computer at all, which has two benefits:

1. It is something that can be turned into a printable step by step guide for an inheritor to follow.
2. It avoids needing to discuss security tradeoffs about air-gapped computers, viruses, etc. until the last word (which is where you want to load the words into a wallet anyway)

Once the seed XOR stuff is done, you have a single key and no multi-sig complications which gives the inheritor the freedom to sweep the funds, and also the opportunity to learn to use Bitcoin from the shallow end of the pool.

Something like: https://www.dipunmistry.co.uk/secure-bitcoin-for-dummies/btc-vault/0.primer/ is what I have been thinking about.

That said, CREATING seedxors can take a while even with a guide like: https://github.com/dipunm/seedxor, it took me 45 minutes to trial run generating 2 backup keys that XOR to give me my private key.

I'd say that is where the most value comes from for a seed signer. Turn dice rolls (or PRNG) into SeedXOR sets in a provably fair way.

jdlcdl, 2022-11-22:
I'm currently playing with this in it's own "more_entropy" branch over [here](https://github.com/jdlcdl/seedsigner/tree/more_entropy)

It's a new advanced setting, "more entropy" which enables a new button to press (under add passphrase) before a seed is finalized.
In this "More entropy" menu, I've added 4 reversible operations to be performed on the pending seed's entropy.  They are:
* Invert bits (basically xor with 0xFF)
* Reverse bits (all 128 or 256 bits in reverse order).
* Reverse bytes (all 16 or 32 bytes in reverse order, endian-ness toggle)
* Seed XOR (which currently only works if another seed is already loaded).

In each case, user is brought back immediately to Finalize the seed, and can view the new fingerprint.

For the first 3 ops, you can do any number of them in any order and if you've done them an even number of times, you get to your original key.   Same goes for Seed XOR, do it with the same key 2x and you're back to the start... but this is not the case when mixing with the other ops.

I figure it's 3 more bits of un-written entropy for the bit-fiddling ops plus 1 more bit for each printed seed-qr found on your body... more wrinkles for sure.

I'll chime in here again when I think this is close to ready.

jdlcdl, 2022-12-09:
I've made more progress on seed xor in my forked 'more_entropy' branch linked above.

For now, it's available when "more entropy" is enabled and visible when finalizing a seed via the "More entropy" link.
One of the options is SeedXor (if, and only if another seed of same mnemonic length has already been loaded).  Selecting SeedXor shows the list of available seeds; user can go back or can apply xor, landing back in the "more entropy" screen... where they can reverse the process or seed-xor with other seeds, until they decide to finalize.

Still to do:
To tear seed xor out of my arguably cringy "More entropy" branch, into a seed_xor branch of it's own, and make it available in the seed finalization process, along with "Done", and "Set passphrase"; perhaps with it's own settings entry too?  At the same time, I'll look to accomplishing it with as few changes to existing base classes as possible, unlike "more entropy" ;)

dipunm, 2022-12-09:
This is amazing, thank you for working on this. I want to download this fork and test it but will likely not be able to get to it until next year. 🫡

jdlcdl, 2022-12-10:
@dipunm, your feedback will be much appreciated.

I've had a humbling experience coming up to speed with git and github lately, but I'm trying to learn to use branches, and doing my best to reserve from pushing until each are in "non-crashing somewhat-working" order.

I keep an "integration" branch somewhat current when I've made meaningful progress on any of the other branches, treating integration as if it were a dev branch of multiple enhancements.  Leaving this on my pi2 by default, I use it to remind me of all I have not finished, with hopes the bugs will nag me into eventual fixes, leading to "Done.".  Currently it has "more_entropy", "screensaver_blankscreen", "prudently_paranoid_settings" and "kdmukai/initial_multilanguage".  At the very top branch's README.md file, I've added notes to explain what each branch is about.

Thanks for chiming in with your encouraging words!

jdlcdl, 2023-01-02:
Since yesterday, I'm starting to reform my opinions on this.  Thanks to hard lessons that we have yet to learn via lukedashjr as well as a share from keith in the telegram group that reads like "The tldr is: if you think SeedXOR is a good idea, wait until I tell you about multisig!".

Perhaps XOR or shamir is still interesting for splitting shares and storing them distanced for a single private key w/ a utxo that is held long term.  I'm recently leaning hard against it for a bip39 seedqr/phrase that is used to create a bip32 hd wallet.

I had a great deal of fun playing with my more_entropy branch, because it's a way to have a recorded backup that is not the complete solution to spend funds.  In a single screen, a couple clicks can alter the entropy of a seed in a way that it can easily be done by computer or by hand and it's reversible, but each mutation is really just a single bit (did the user rev-bits/rev-bytes/invert-bits or did they not).  You can then SeedXOR (128-256 more bits) and do it again for 3 more bits, and on and on.   BUT, simply adding a passphrase is even more efficient, and already a standard;  from one keyboard screen, up up left left click buys us 6-7 bits per character and we only clicked 5 times... that's pretty hard to beat.
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
dipunm, 2023-01-17:
Okay did a bit more testing.

I created a random key with a passphrase then another and I was offered to SeedXOR with it. What should I be expecting here? I think keys with passphrases should be excluded just like mismatching word counts are.

dipunm, 2023-01-17:
Going to "add passphrase" then back = Finalize seed page
Going to "SeedXor" then back = Verify Backup page.

dipunm, 2023-01-17:
I noticed that if you seedXOR with something, you will see a done option and then you have to go to Backup Seed > View Seed Words in order to see the new words.

I had a little think about this and this seems perfectly fine to me. In some cases you may never want to or need to see the combined key, you just get an XPUB, receive to it and later you can trust that combining the two+ seeds will give you the same private key in the future.

dipunm, 2023-01-17:
It is interesting that SeedSigner doesn't attempt to help you choose a valid final word, nor does it let you continue if you have an invalid final word.

The reason I checked for this was when I saw this example: <https://embit.rocks/#/api/bip39?id=mnemonic_to_bytes> it occurred to me that if ever seed signer DOES allow invalid checksums, then you will likely want to ignore the checksum when converting from words to bytes.

Fortunately, there is nothing to do here since none of the settings allowed me to create a mnemonic with an invalid checksum.

That also tells me that I shouldn't suggest any methods of last word selection that doesn't guarantee a valid checksum. I have in the past suggested that you could choose a word within range (i.e. last word = 3A_, choose a word between inject -> invest) -- although this technique preserves the original entropy, it is likely to be more problematic than I thought when it comes to restoring.

jdlcdl, 2023-01-18:
Four posts above this one, @dipunm wrote:

>  I think keys with passphrases should be excluded just like mismatching word counts are.
>
> Further, it is technically incorrect because it shows the fingerprint WITH passphrase which I imagine is NOT what we are combining:

This is a great point!  I can see that this could be confusing.

To review:

SeedXOR IS combining the **initial entropy only** of two or more BIP-39 mnemonic phrases, then it's adding the necessary checksum bits to result in a new valid BIP-39 mnemonic phrase.

That is, SeedXOR:
* is NOT combining two or more BIP-39 seeds (the 512 bit result of pbkdf2("sha512", mnemonic-phrase, "mnemonic"+passphrase, 2048) which is later fed into BIP-32 to create a master wallet private-key and chain-code)
* is NOT combining two or more BIP-32 wallets which is the same as saying it is NOT combining master-xprvs nor master-xpubs nor key-identifiers nor fingerprints.

In my implementation of SeedXOR, there are two and only two edge-cases checked (I can imagine a 3rd now, which I'll mention below) where SeedXOR of two seeds is NOT allowed and an exception would be raised:
* you cannot SeedXOR two seeds of different mnemonic lengths (more accurately, of 2 or more different lengths of entropy bits) because this would imply clipping the longer one to the length of the shorter one. ie: entropy bits would be lost... Yikes!  Else it would require filling the shorter one to the length of the longer one with something other than entropy... Yikes!
* you cannot SeedXOR one seed against itself (more accurately, the same entropy bits against themselves) because this would result in all 0x00 bytes ie: a mnemonic of "abandon "*11 + "about", or "abandon "*23 + "art"... Yikes!  While reversible, still a bad idea.

Similarly, an equally bad idea, but NOT yet a defined edge-case where an exception would be raise is:
* allowing SeedXOR against a seed's inversion, which would result in all 0xff bytes, ie: "zoo "*11 + "wrong" or "zoo "*23 + "vote"... Yikes!

This raises some interesting confusions for the user.
* The same mnemonic-phrase used with different passphrases (empty is different than non-empty) will create seeds with different fingerprints, which would raise an exception if combined via SeedXOR.  They might wonder "Why can't I SeedXOR these unique fingerprints?".
* While very improbable, two different mnemonic-phrases, given billions of different passphrase attempts, can have the same fingerprint even though they are different and do NOT represent the same BIP-32 hd wallets, and could safely be combined via SeedXOR.  They might wonder "Why am I being allowed to SeedXOR the same seed with itself?".

**You make a very good, completely convincing point** that we should NOT offer the possibility to combine via SeedXOR any seeds with a
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

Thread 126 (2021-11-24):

[FEATURE] Create public addresses from seed words

ozomer, 2021-11-24:
Creating an xpub is great, but you need a computer/smartphone to calculate the addresses.
It could be useful to create the addresses directly on the SeedSigner (by choosing a seed and an address index).

For example:
- You want to create a new wallet quickly and load funds to it.
- You are worried that your computer/smarphone is generating fake addresses, hoping that you will load funds to them.
- You want to have an extremely private cold-storage with multiple addresses where the xpub was never loaded to any a device that was connected to the internet.

P.S. Creating public addresses from an xpub could be nice too, but please keep both actions a single-step process - I would want to create public addresses directly from the seed words, without creating the xpub, saving the xpub, and only then create the addresses.

mcroad, 2021-11-28:
Creating receive addresses on-device puts the responsibility to keep track of used or unused addresses on the user. User should not reuse addresses. SeedSigner does not have access to the chain and does not know which addresses have already been used. For this reason, generating addresses on-device is a potential foot-gun.

A better feature would be to validate receive addresses. Device scans an address qr and says whether it belongs to a selected xpriv.

SeedSigner, 2021-11-29:
Not sure if the potential danger of address re-use should prevent us from providing the feature. Also, we already have receive address validation, just scan an address from the main menu.

ozomer, 2021-12-01:
> Not sure if the potential danger of address re-use should prevent us from providing the feature. Also, we already have receive address validation, just scan an address from the main menu.

Nice, I didn't know that.

You could show a warning message about address-reusage privacy dangers - and also about using a high-index address without using many of the previous address (wallets will stop searching for balance in addresses when a series  of unused addresses).

ozomer, 2021-12-04:
> Not sure if the potential danger of address re-use should prevent us from providing the feature. Also, we already have receive address validation, just scan an address from the main menu.

How does this actually works without knowing the derivation path? What if this is address number 1000?

SeedSigner, 2021-12-04:
The current implementation just begins attempting to validate addresses (using the standard derivation paths for change/receive) from the zero index position, am hoping that in future implementations we can provide users with the ability to jump to a specific address index number to validate.

kdmukai, 2022-05-01:
v0.5.0 includes a "Skip 10" feature.

I'd still like to see an Address Explorer feature added. Something like:

From Seeds menu:
* Select the seed you want to work with.
* Select "Address Explorer"
* Choices: Single Sig, Multisig
* Single Sig:
    * Select script type (w/Custom Derivation as an option)
* Multisig:
    * Prompt to load the multisig wallet descriptor via QR
* Prompt for "Receive" or "Change" addr
* Show address reuse warning
* Maybe options: "Browse list", "Jump to index"
* Browse list:
    * Shows next 5 addrs as a button list (clicking on button displays addr details).
    * Bottom button is "Next"
    * If the "Next" page's first index is greater than typical wallet gap (e.g. 20?), show a wallet gap warning.
* Jump to index:
    * Leads to Keyboard UI to type in the index
    * If the index is greater than typical wallet gap (e.g. 20?), show a wallet gap warning.
    * Shows the Browse list w/first result at the specified index.
* Address details screen:
    * Title: `Receive #15` or `Change #23`
    * Show QR code
    * Show address as a `FormattedAddress` (highlights first/last 7 chars)

EverydayBitcoiner, 2022-12-27:
Still to do from above list:
- Custom Derivation option (This seems like an pretty advanced power user feature, not sure how much demand there is for this)
- Address reuse warning
- Options: "Browse List",  "jump to index"
- Address details Screen (currently jumps straight to qr export)

Are these remaining points being worked on by anyone?

It looks like everything else from the list is working in the dev branch.

Also issue https://github.com/SeedSigner/seedsigner/issues/216 was submitted for getting receive addresses using xpub or singlesig wallet descriptor. Wondering if that issue should be moved into this one?

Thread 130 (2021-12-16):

QR will not scan

jgoodz, 2021-12-16:
Recently bought all the hardware for 2 SeedSigners on my own. Upon setting it up I am unable to scan QR codes with the camera. It turns on and I can see the QR code on screen but it deosnt detected that its a QR code. I've tried Low Med and High camera density settings. Image seems a little blurry. I tried small close up QR, larger further back QR, no dice. Camera FSP seems to be 2 or so. difficult to find the target with.

Using Raspberry Pi Zero (no wifi)
Using recommended LCD Hat

Camera: Raspberry Pi Camera Rev1.3 P5V04A SUNNY

Does anyone have an idea how to get it to scan properly? This camera seems pretty common. Has anyone else had luck with this model?

Thanks

SeedSigner, 2021-12-16:
It sounds like a focus issue with the camera. The great majority of cameras come out of the box focused well enough that they scan fine, but occasionally they show up out of focus. Some in our Telegram community have had success with this technique, though it is possible to damage the lens:

https://www.jeffgeerling.com/blog/2017/fixing-blurry-focus-on-some-raspberry-pi-camera-v2-models

Are both of your builds experiencing the same issue?

jgoodz, 2021-12-16:
I've been trying to adjust the focus with no luck I need a tool to adjust it. I see 3d printed tools online but they seem to be for a different camera as mine has 3 divets to grip around while the tools match 4 divet pattern. I will check out this link you provided.

In the attached pic it seems like it's clear enough but no detection. I tried to press all buttons with no success either. I put random qr code on a 43 inch tv and was about 4 or 5 feet away. Maybe the focus at further distances trigger the qr recognition?

Thanks.

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

SeedSigner, 2021-12-16:
Can you say what kind of QR code that is that you're scanning? What software generated it? Also, does QR scanning operate ok in the test module?

jgoodz, 2021-12-16:
My apologies, I think I realize my problem. My assumption was that this would also be able to scan a private key qr code from a wallet generated on the fly from bitaddress.org and segwitaddress.org, as this would be similar to my intended use case off a paper wallet. I did not realize writing the QR on paper after generating by the seedsigner was the only option.

SeedSigner, 2022-01-16:
Closing this, thank you for following up!

Closed 2022-01-16.

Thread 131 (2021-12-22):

[FEATURE] BIP85 Support

kornpow, 2021-12-22:
I thought it would be really cool if SeedSigner could support BIP85, which is a method for generating a derived set of seed words/ entropy from a starting seed words.

Would be great if you could:
1. Scan in a SeedQR, save into one of the storage slots
2. Derive BIP85 seeds/entropy, and either allow export or save into other seed slots.

This BIP is currently only implemented in ColdCard at the moment. I've used BIP85 entropy in a few different ways so far, which unlock some cool use cases:
1. Export an `xprv...` private key, and use for initializing LND, instead of the AEZEED cipher
2. Export seed words, and use those seed words for software wallet (phone wallets, or Sparrow wallet for Whirlpool)
3. Create a multisig wallet, using only a single seed ie. making a multisig with derived seed index 0, 5, 10. Basically a multisig hidden in a single sig

Marcsmyname, 2022-02-13:
I like this idea. I've recently started going down this BIP85 rabbit hole. With 10,000 possibilities, you can even use one key as a passphrase for your wifi. (you obviously wouldn't send any bitcoin to addresses derived from this xpub)

I'd like to have this feature just because it makes it easier to verify the cold card.

I wish I would have thought of using one for LND.

jase100k, 2022-03-26:
BIP85 + passphrase support would really be great here.

I hate having to right down new seeds all the time and securing them, and trying to stamp seeds on to metal each time.  Can also be very expensive if you don't use your own materials sourced like washers.

Another use case I can see is that you can protect the seed, and then derive new seeds for your kjds or parents, all from one seed.

One seed to rule them all.

Semisol, 2022-04-01:
Would be really useful to have this, to for example have one securely stored seed to generate multiple hot wallets.

SeedSigner, 2022-04-04:
We appreciate the comments in here -- people are definitely passionate about BIP85.  : )   We would also need to se if embit supports BIP85 since we use it for most of our interaction with the protocol...

jase100k, 2022-04-07:
Here's a simple BIP85 implementation in seedsigner developed on branch 0.5.0-pre3.  Only main issue is it requires BIP85 library https://github.com/ethankosakovsky/bip85

i.e pip install bip85

source code at https://github.com/jase100k/seedsigner/tree/0.5.0-pre3

1. Scan your SeedQR
2. Add your passphrase if necessary
3. There's an option in the seed page to Gen Bip85 Seed select that
4. Choose 12/24 words (18 words does anyone use?)
5. Choose your index
6. Warning message displays around seeds
7. BIP85 child seed is displayed ( 4 words per page)

The other 3 methods to derive entropy, i.e xprv, wif, seed are not done yet.  I don't like how the index entered needs to be remembered by the user.  Use test seeds.

Semisol, 2022-04-08:
> We appreciate the comments in here -- people are definitely passionate about BIP85. : ) We would also need to se if embit supports BIP85 since we use it for most of our interaction with the protocol...

nope as far as I'm aware, but you can see a bip85 implementation above.

SeedSigner, 2022-04-12:
Just want to flag @kdmukai and/or @newtonick on this to see if they're willing to review the implementation and share any perspective. Appreciate your work on this.

Semisol, 2022-04-20:
Any status updates?

kdmukai, 2022-04-21:
@jase100k closed PR #172 but didn't leave a comment.

That PR added an external pip dependency, but it was written by the BIP-85 author as a reference implementation so seems reasonable to include.

If the PR is revived against the final v0.5.0 release, I'd be happy to dive into it.

jase100k, 2022-04-23:
PR #194 updated to remove bip85 reference library dependency.

EverydayBitcoiner, 2022-12-29:
The mentioned PR #194 was merged three weeks ago into the dev branch.

jdlcdl, 2022-12-29:
@EverydayBitcoiner, I'm really enjoying watching how you've hit the ground running here, with code, with comments, with links to other issues/prs, all, im assuming, with intention to get another task all the way to "Done!".

Nice work!  Way to close out the year!  All the best in the next one.

Closed 2023-02-28.

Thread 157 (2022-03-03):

QR brightness issue on the 0.5.0 Pre-release 1

mccolister1017, 2022-03-03:
can't scan anything on the rasp it's too shiny (full hd webcam)  got it working with some trick but i think it's a bug everything is ok with the main version.

or maybe you could add a ( Brightness Settings ).

SeedSigner, 2022-03-03:
Thank you for this, going to add brightness adjustment to XPUBs in addition to PSBTs. Thank you!

jdlcdl, 2022-11-21:
I suspect that this issue might deserve to be closed?  Reason being that I've never had a problem adjusting brightness while seedsigner is displaying a qrcode for my computer to read.  For me, it's absolutely necessary to dim the qrcode... and so far it has always worked well for me (but Im using webcams of 15-20years old).

Then again, re: "or maybe you could add a ( Brightness Settings )." reminds me of my ramblings on telegram a couple weeks back, where I was playing with rpi's pwm to power the backlight, and I was not wanting to do this for qrcode reading but rather for saving my own tired eyes in low-light.   If this is the reason why this 'bug' issue remains open, then I'd like to consider working on a "brightness" user settings change, but I'm not sure where that might fall on the priority list.

I'll check back on this issue for feedback from others.. and of course I'll make note that it's my belief that seedsigner-os intends to disable rpi-pwm in the near future, because it would be silly to devote too much work to brightness control via pwm-backlight if pwm remains on the chopping block.

jdlcdl, 2022-11-22:
for future reference: related to my thoughts on "powering backlight via pwm to adjust screen brightness":

on my RPi2b: I see a +5-6% cpu-usage cost on the python process powering the backlight pin via pwm at 1000hz and 50% duty cycle... as opposed to just setting it high.

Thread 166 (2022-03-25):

Provide reproducible builds

Giszmo, 2022-03-25:
The [Manual Installation Instructions](https://github.com/SeedSigner/seedsigner/blob/main/docs/manual_installation.md) look far from deterministic and while #105 would probably help to get something more predictable, there is still many sources of randomness in the image creation process such as `sudo apt-get update && sudo apt-get install -y ...`. Without deterministic builds, users have to trust the provider of the image. While the seedsigner does support mitigations for many attacks:

* (forced?) dice ware vs. fake randomness
* air-gap vs. key leaks via radio devices
* third-party companion apps vs. receive-to-malicious-address

it feels wrong to assume the device can't scam its users. Or do providers claim just this?

newtonick, 2022-04-21:
I'm definitely interested in reproducible builds, but I'm not aware of any turn key solutions to make this happen. We are hoping to make steps in that direction, but it's going to take sometime. Any suggestions or open source projects you can point us to?

Giszmo, 2022-04-22:
Unfortunately I can't point you to anything useful but generally it might "just work" for a short amount of time, so it would be worth a try if doing the image on two machines yields anything comparable.

From there, you can always install specific versions instead of upgrading to whatever is the latest etc.

DesobedienteTecnologico, 2022-06-09:
Reproducible build available @Giszmo :
https://github.com/SeedSigner/seedsigner-os

StingJohnson, 2022-09-28:
the os i have built with https://github.com/SeedSigner/seedsigner-os doesn't meet the same sha256 from the official release. In fact, it is a lot smaller in terms of size. What could go wrong?

SeedSigner, 2022-09-28:
Right, these will never produce the same hash because the standard release has a much larger OS footprint than the build-root OS that you used. The build-root OS may end up being reproducible, we're not sure yet whether it's feasible/possible and how much work will potentially need to go into making it reproducible. Feel free to ask if you have any other questions or concerns.

Giszmo, 2022-09-28:
If the released binary can't be reproduced, what is reproducible then?

StingJohnson, 2022-09-29:
yes, i am thinking the same. Although it is definitely a handy device and seems legit, if it can't reproduce the released binary, it is missing the foundation on which all the trust are relying.

SeedSigner, 2022-09-30:
Some clarification is helpful here. The released binary based on the current conventional build will never be reproducible, never; it's just not possible given the process used to create the conventional build. The new SeedSigner-OS is a completely different approach to building the Linux OS upon which our python software operates, so it will never match the data in conventional build process, which utilizes a stock version of Raspberry Pi's pre-assembled OS. They are completely different animals and it's important to understand this concept as you attempt to evaluate our builds. That said, @DesobedienteTecnologico believes that a reproducible build is in fact possible with the BuildRoot OS that the new SeedSigner OS leverages, but it will take significant time and effort to get there. We have to figure out how to exclude the multitude of timestamps that buildroot incorporates into the OS so that the binaries can be properly compared and validated. I would really invite both of you to dig in and see if you can help; we only have a handful of generally uncompensated developers who work really hard on our project. If you lack the technical skills to meaningfully contribute to our development efforts and still would like to see our software continue to be developed and improved, I would encourage you to make a donation to our development fund, which is the primary way that we can motivate and compensate contributors for their work. Donations are accepted at: https://seedsigner.com/donate-now/

StingJohnson, 2022-10-25:
So, why building from the source (your seedsigner-os) is significantly smaller in size than the binary release? I forgot the exact number but i do remember that the one built from source is way lighter.
Now I can understand that due to the version of python and all that makes the hashes don't match. But what causes the huge difference in size?  Thanks!

SeedSigner, 2022-10-25:
The engineers working on SeedSigner OS have included only the necessary functions that our software requires, all of the additional functionality and code that the Pi Foundation includes in their stock builds has been removed. That is the reason why the binary is so much smaller.

StingJohnson, 2022-10-26:
If SS OS only includes the necessary functions, which is a good thing, then why making the stock builds that bloated. Shouldn't stock build include ony the necessary fucntions?
We need it only to be as a Seedsigner not anything else, don't we?

SeedSigner, 2022-10-26:
We have just gotten the custom OS to the point where an experimental release made sense. As it is further tested and refined, the plan is to phase out the stock builds, but we're extremely risk averse and want our prepared images to be stable and reliable for our users. We are a project composed of volunteer developers with very little in the way of funding; we will get there but it may not be as quickly as you would like.

moonsettler, 2023-11-21:
shouldn't this issue be marked as resolved now?

ktecho, 2025-07-23:
Latest releases are reproducible, so yes, it should be closed:

https://walletscrutiny.com/hardware/seedsigner/

(to get more details, click on any of the specific verifications)

Closed 2025-07-25.

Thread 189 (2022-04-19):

Edit suggestion for - "away" from all online devices

punterwantsawhalepass, 2022-04-19:
may need to change that, away made me think of distance

"You must keep your seed words private and safe. Never store your seed words on an online device."

newtonick, 2022-04-21:
Issue is referencing this line of text/code: https://github.com/SeedSigner/seedsigner/blob/5e007e501044f518f8d3c8ab9505901cfba249bb/src/seedsigner/views/seed_views.py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

punterwantsawhalepass, 2022-04-21:
this might also be good language.

"You must NEVER allow your Bitcoin seed words to come into contact with the Internet."

source: https://observablehq.com/@jimbojw/grokking-bip39

SeedSigner, 2022-04-22:
Just taking a stab -- "Never input your seed phrase into a device that connects to the internet."

newtonick, 2023-01-27:
> Just taking a stab -- "Never input your seed phrase into a device that connects to the internet."

+1 for this option if just trying to resolve the immediate issue

kdmukai, 2023-01-27:
Photos of proposed updated screens would help here (or rather in a PR). Sometimes messages just don't look/read quite right onscreen.

jdlcdl, 2023-01-27:
> Photos of proposed updated screens would help here (or rather in a PR). Sometimes messages just don't look/read quite right onscreen.

I agree, especially since it's not obvious where different phrases will wrap.  Back here shortly with some images of all the proposed phrases in this thread... with the help of "enteropositivo/seedsigner_emulator".

jdlcdl, 2023-01-27:
Thanks to the work in enteropositivo/seedsigner_emulator, this was easy to do from my desktop.

Once we decide on one of these, I'll be happy to verify that it indeed looks the same on the seedsigner.
If anyone would like to propose changes, just leave a note here, I'd be happy to get a screenshot while this procedure is fresh in my head.

Currently:
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

Proposal A and B, thanks to @punterwantsawhalepass
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

Proposal C, thanks to @SeedSigner (w/ a +1 from @newtonick)
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

jdlcdl, 2023-01-27:
I prefer Proposal C, because:
* it preserves vertical space around the message,
* it's an assertive command instead of really good advice,
* As a a rare "honorable usage of fear" as a motivator, it reminds the user that they've done it wrong for years, and to take action immediately.

jdlcdl, 2023-01-27:
ATTENTION: I had hoped that the SeedSigner Emulator would accurately represent where text would wrap, but this is not the case everytime. :(

I'm going to issue a pull request for this, leaning towards Proposal C and carrying similar text into the SeedQR warning.  I'll take photos of what it really looks like on SeedSigner hardware.

SeedSigner, 2023-01-29:
Thank you for your work on generating these previews.

bitcoinprecept, 2023-05-09:
Some better late than never thoughts on the topic here... (without thinking through any specific proposals to the outstanding edits proposed above)

Some people may not fully think through what it means to interact with "devices that connect to the internet" (or however it's phrased in the multiple variations above). I think it's worth offering users a clear warning to not interact with their seedphrase data within site of webcams of their cell phone camera. This may be an edge case not worth solving for within the limited Seedsigner UI, but it's worth considering that your camera could be a vector to spy on you/steal your data even if you don't voluntarily "take" a photo with it.

The best practice, in my opinion, is to be fully away from internet connected devices and cameras when interacting with seedphrase data. If it were possible to relay this concept to users, that would be my vote.

Closed 2023-07-20.

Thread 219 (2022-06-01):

Exception scanning compact QR

enteropositivo, 2022-06-01:
### Current situation:

Now I can emulate seedsigner on desktop,  webcam working too:
https://github.com/enteropositivo/seedsigner-emulator

And I can scan a  standar seed succesfully

### But I have a problem scanning compact seeds

Using the sample QR from Seedsigner repo
[https://github.com/SeedSigner/seedsigner/blob/dev/docs/seed_qr/img/compact_12word.png](https://github.com/SeedSigner/seedsigner/blob/dev/docs/seed_qr/img/compact_12word.png)

I got the following exception  on line 400 when code does **_bin(b)_**:

`TypeError("'str' object cannot be interpreted as an integer")`

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

**Some Notes**

- That the same seed works OK for me using  SeedSigner hardware on Rpi Zero, but the same code doesn't work on a desktop enviroment
- The code is unchanged from seedsigner repo ( I only change display driver under /hardware/ folder )
- May be a problem with python ?  (I'm using v3.10)

SeedSigner, 2022-06-02:
Will let @kdmukai chime in, but I believe this is because we implement a specialized QR code library to read the compact SeedQRs.

enteropositivo, 2022-06-05:
### SOLVED

I found a solution.

The libraries that zbar downloads on Windows enviroment are very old, "SeedSigner requires zbar at 0.23.x or higher."

This is the code of **build.sh** from **pyzbar**  at line:9  that downloads  v0.1 of libraries

```sh
curl --location --remote-name-all "https://github.com/NaturalHistoryMuseum/barcode-reader-dlls/releases/download/0.1/{libzbar-32.dll,libiconv-2.dll,libzbar-64.dll,libiconv.dll}"`
```

### To be able to use compact QRcode  on Windows ...
we need to install the newest zbar libraries this way

Install MSYS2 building platform for windows
[https://www.msys2.org/](https://www.msys2.org/)

Install Zbar libraries and dependencies package
[https://packages.msys2.org/package/mingw-w64-x86_64-zbar?repo=mingw64](https://packages.msys2.org/package/mingw-w64-x86_64-zbar?repo=mingw64)

**Now pyzbar wrapper needs to load libzbar-0.dll v0.23.94 library**
So edit:  src/pyzbar/pyzbar/zbar_library.py

Change line 23 and 24  as
```python
if sys.maxsize > 2**32:
        # 64-bit
        fname = 'libzbar-0.dll'
        dependencies = []
```

Change line 58 as  (path of MSYS2 Zbar libraries)
```python
  dependencies, libzbar = load_objects(Path('C:\\msys64\\mingw64\\bin'))
```

And NOW the emulator works with all the functions as on Raspberry Pi Zero

kdmukai, 2022-06-05:
Amazing bit of tech sleuthing, @enteropositivo!

Looking forward to seeing where this work goes! That being said, I would guess that Windows would be a kind of last-resort OS option for an emulator. Something like Tails or some other Linux flavor would be safer.

SeedSigner, 2022-06-06:
Agreed, this is great work @enteropositivo! The Windows implementation has a strong use case for tinkerers and development, but agree with Keith that Tails is important too. It looks like you have begun TailsOS instructions in the readme?

enteropositivo, 2022-06-07:
The main objective of the emulator is to be able to modify the code or play with it in a simple way without having to use the Raspberry Pi.

But it can also serve as a tool to calculate the last word of the seed or even use it in Tails OS (currently works)
Anyway I still have to do more tests with the camera since in Ubuntu it goes very well but in Tails sometimes it has problems.

The purpose of making it compatible with Windows is basically for curious people who want to try it on testnet before deciding to buy a Raspberry (of course, if they can find one because there is no stock  :) )

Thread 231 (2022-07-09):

[feature] USB Smartcard reader support

openoms, 2022-07-09:
There are only so many Specter Shileds around, but storing secrets on smartcards become my favourite method.
Consider the convenience of the cheap, PIN protected, encrypted storage which is very well suited for travel (especially compared to plaintext seed words or QRcodes).

Since the SeedSigner currently runs a full linux distro the driver support should be fairly straightforward through USB.

The setup in mind:
* the SeedSigner could unlock with the PIN and read the secret from the smartcard - same as the Specter Shield
* could even be able to initialize the cards (reset and upload the MemoryCardApplet.cap)
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

Parts:
Cards: https://www.alibaba.com/product-detail/JCOP-Dual-Interface-Support-RSA4096-ECC_1600070838098.html

The reader pictured:
ACS ACR39U-N1 PocketMate II USB Smart Card Reader
https://www.amazon.co.uk/dp/B0758TS5JR/

Notes to install the card reader an initialize on Debian/Ubuntu: https://gist.github.com/openoms/510b2876cab19e15c4190456ea8aad82

Code in Specter DIY: https://github.com/cryptoadvance/specter-diy/blob/master/src/keystore/memorycard.py
Issue about supporting other USB or hard-wired card readers: https://github.com/cryptoadvance/specter-javacard/issues/1

SeedSigner, 2022-07-10:
It's an interesting concept though I don't have any practical experience in working with smart-cards. Do you have any information on the data-storage expected lifespan of the smart cards? Are there incidents where they can malfunction or their stored data becomes corrupted or otherwise inaccessible? I'm leery of recommending users store PKs in digital format without some kind of secondary backup (usually an analog one). But if there is good information on their reliability / durability, and the quorum is large enough, I could potentially see using them as a primary / solitary PK storage mechanism. Also open to any thoughts that @kdmukai or @newtonick may have.

openoms, 2022-07-10:
However smartcards are generally used widely for years without any corruption issue (doesn't even compare with the magstripes on bank cards) agree that any digital media shouldn't be the only, non redundant backup.
They are basically disposable secure chips which lock permanently after 10 failed unlock attempts (as configured for the Specter).

openoms, 2022-12-13:
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

All components can be added to the threat model. It is about optionality and I think a dedicated smart card reader (just as a dedicated Rpi0, sceen, camera and SDcard(s)) is a realistic requirement.

The advantage to have a general purpose, unbranded, but PIN protected and encrypted card holding a seed versus a plain text QRcode or seed backup is huge.

SeedSigner, 2022-12-14:
Still curious to hear any thoughts that @kdmukai or @newtonick may have?

newtonick, 2022-12-14:
I'm not against the seedsigner project exploring this idea. I agree with @openoms about adding optionality. DIY signing devices are a perfect place for folks to explorer different solutions for different threat models. I personally have no experience with smartcards and won't likely spend the time to explore this rabbit hole in the near future. Adding support for a smart card reading in SeedSigner OS will likely be more time consuming than adding it to the Raspberry Pi OS.

I'd love to see someone do a POC via manual build steps. This would help show what development steps would be required and gauge seedsigner user interest.

3rdIteration, 2023-09-23:
Is anyone here still interested in this? I've been playing around with the satochip and seedkeeper  smartcard based devices and adding an integration that allowed both seed storage and also on-card signing would actually be trivial, as both the java applets and a python API is already available. (It would simply be a matter of adding the UX elements)

I'm happy to knock up a proof of concept if there is any interest.

jdlcdl, 2023-09-24:
> ...a proof of concept if there is any interest.

I will certainly follow any work you do on this, however it feels not so seedsigner-ish, at least to me, for my following opinion:

I've come to enjoy the half-duplex control that I have when transmission of information is via qrcode.  I get to control who is talking and who is listening... and if I want to, I can put another airgapped-or-not device in between to make sure that what is being said is what I want to be said... without the other listener hearing.

Do I believe that normal people would do this?  Of course not... but that I CAN is what matters to me... so that I can do this now and again, and so that the rest of the time I know that I'm still controlling who is talking and who is listening.

With electronic transmission, wifi/bluetooth/usb, the user never knows what is being said, whether or not there was two way communications, or the amount of information transmitted.

Still, if you work on this, because the tech interests me... you will certainly have my interest and my feedback.

kdmukai, 2023-09-24:
@3rdIteration an on-card signing use case wouldn't make any sense for SeedSigner. TapSigner and anything of similar functionality exists as a parallel hww-lite alternative.

As @Marc-Gee noted, back-dooring a smart card reader makes much more sense as an attack vector than trying to back door a Raspi Zero that might end up just controlling someone's Christmas lights or an NES emulator or who knows what. We'd be stepping into a much more aggressive adversarial arena. I'm not convinced the benefits are worth it.

@openoms:
> The advantage to have a general purpose, unbranded, but PIN protected and encrypted card holding a seed versus a plain text QRcode or seed backup is huge.

I don't deny that there is a use case, but overall I think the risk of plaintext mnemonic backup or SeedQR is strictly tied to the problems inherent with single sig. Yes, lots of people use single sig (and, of course, it makes sense as an initial destination when first taking self-custody), but all of the single sig security solutions just feel like band-aids. There is a spectrum, X is better than Y, but I just don't think that even Y is totally sufficient. So rather than trying to incorporate incrementally better Ys (that still aren't sufficient), I think the main focus should always be on encouraging multisig and making it as easy as possible.

As a tiny team of volunteers, @newtonick has the right take.

3rdIteration, 2023-09-24:
I'll finish writing a cli for this and knock up a basic PoC that just does storage with a USB connected, as this is trivial to implement. (Implementation via GPIO could come later if there is interest)

3rdIteration, 2023-11-30:
Demo code is here: https://github.com/3rdIteration/seedsigner

Video demo here: https://youtu.be/WHVWqJJBNdA

I'll post a guide on how to install from the "Manual Installation" environment, or if people prefer, can post a MicroSD image.

Everything is just running nicely on x86

openoms, 2023-12-05:
Update:
I have managed to install and use the Satochip applet on the same javacard which was used for the SpecterDIY. They also have different, independent PIN codes.
See my notes here for Linux (started for Specter, now extended): https://gist.github.com/openoms/510b2876cab19e15c4190456ea8aad82

Started to test the setup with Sparrow Wallet by initializing the card, storing a seed and changing the PIN right from the GUI there.

Doing the initialization and signing on a self-built, stateless SeedSigner will be such a good use case, thank you very much for sharing this @3rdIteration

3rdIteration, 2023-12-23:
Added an updated version of the code here: https://github.com/3rdIteration/seedsigner/releases/tag/0.7.0%2BSatochip-Alpha1

Changes from previous alpha and some cases to 3d print are also included in the release info.

3rdIteration, 2024-02-27:
Just a heads up that I have pushed a more detailed video here:
https://www.youtube.com/watch?v=Rhs9z5uL7qg

And a proper beta release here: https://github.com/3rdIteration/seedsigner/releases (Running on buildroot now)

## Difference from Stock SeedSigner
* Multiple Smartcard interface options…
   - Standard USB CCID/PCSC readers
   - PN532 NFC Reader Connected via I2C
   - USB Phoenix Type "Sim Reader" supported via OpenCT
* Saving and Loading Seeds & Passphrases
   - Supports loading of Seed, Seed+Passphrase in one go, or loading passphrase independently. (Potentially from a different SeedKeeper)
* Saving and Loading Multisig Descriptors
   - Also changed default behavior to keep Descriptor loaded until manually cleared. (Including descriptor appearing in the Address Explorer when loaded)
   - Descriptors are split up into a template and xpubs before being saved to SeedKeeper.
* Saving and loading generic secrets to a Seedkeeper card
   - These secrets can be either viewed as text or displayed as a generic text QR code.
* Initialising Satochip Cards with SeedSigner
  - Load any Seed from the SeedSigner on to the Satochip Card
  - Enable 2FA on the Satochip Card
* Flashing Satochip Applets to blank Javacards
   - Firmware comes bundled with applets for SeedSigner, Satochip and Satodime (Releases from Satochip Github)
   - Firmware is also bundled with the source code for all three projects, along with a modified varient for THD-89 based Javacards. (This can be built from source on-device at run-time)
* MicroSD Card Tools
   - Flashing MicroSD Cards with official SeedSigner Images (Bundled)
   - Verification of freshly flashed MicroSD cards against known images
   - Secure Wipe (Both with zeros and random data)

## Future Features & Improvements
* Add ability to lock/unlock/manage Javacards
* Add ability to view additional sttings/information for the Satochip cards
* Tidy up code and reduce re-use

3rdIteration, 2025-04-20:
Quick update on this. Basically I was getting a number of requests for folk to buy this as a kit, so decided to get something easier to assemble and more reliable than the PN532 clones which are all over the place.

I threw together a simple design based on the SEC1210 smartcard interface, which is supported in the Linux CCID driver. (Though needs some tweaks for the SEC1210URT variant)

The prototype boards arrived and worked well, I'm currently getting second revision fabricated which makes some quality of life fixes and also adds a USB-C power input option so that the full sized reader obscuring the boards isn't a problem.

It actually fits quite nicely in-between the existing display and board, so that is really nice.

I'm also thinking that I will get around to adding the functionality to have the Satochip card handle all of the signing on the card, meaning that the SeedSigner wouldn't actually have any secrets on it at all during normal operation, but rather acts as a mechanism to review the transaction details, load PSBTs, etc. (The idea of a small SeedSigner with a sim sized Satochip that handles the signing is quite compelling to me) Interestingly, this was actually one of the longer term goals for Specter DIY that never ended up being realised.

Images below.
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

I'll probably have these board generally available around mid May sometime, with the design being open so anyone can make them or have them fabbed.

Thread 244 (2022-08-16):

Have anyone tried to deploy Seed Signer to a Raspberry Pi Pico?

irae, 2022-08-16:
The Raspberry Pi Pico has a considerable processing power, as compared to Arduino and other microcrontrolers.

Some advantages would be having no linux, small power draw to run from batteries, smaller downloads, but more importantly, the Pico is about $4 USD instead of the $5 if you manage to find the Zero 1.3, or $15 if you go for the Zero 2 W. The downside might be harder to source camera for the Pico.

Just to illustrate, in some parts of the world it is difficult to source the Zero. I can't find the 1.3 here in Brazil or sellers that would ship it from China. Sellers from china do have the Zero 2 but it costs ~ R$400 (around $79 USD), while I can find the Pico for ~ R$35 + ~R$10 shipping (about $10 USD total).

So I researched a bit, found the [WaveShare Pico LCD-1.3](https://www.waveshare.com/wiki/Pico-LCD-1.3), which is ~ R$40 and the [Arducam Pico supported cameras](https://www.arducam.com/raspberry-pi-pico-camera-modules/), which would be the most expensive hardware at $20 ~ $40 USD.

If I understood correctly, in theory other SPI cameras could work, some start at ~$3 USD. But I haven't found any camera that has supported drivers for the Pico, so I won't risk it, unless someone more experienced offers some guidance.

I already oredered the pieces and I intend to hack around it. While I wait about 20 days for the 3 parts to arrive, I was wondering...

Anyone has any insight on the idea? Or if you know of anyone that already tried that? If those more engaged with the project considered it and had a good reason to drop the idea? If Micro-Python can run the bitcoin libraries or I would need to go down to C (which I am less familiar) And if there is any top of your head advice about it? Any comment whatsoever would be appreciated. Thanks!

kdmukai, 2022-08-16:
I've been working on a custom MicroPython firmware, but mostly targeting the ESP32-S2. MicroPython is definitely SeedSigner's future and I think over time we'll be able to run on a broader array of hardware.

But the Raspi Pico / RP2040 only has 265kB of RAM that can't be expanded. That would make it very difficult for us to use for things like live video scanning for QR cods.

You can see most of my MicroPython + ESP32 + secp256k1 progress here: https://github.com/kdmukai/micropython-esp32

I do include some notes for compiling the custom firmware for RP2040 and I have tested it on a few.

newtonick, 2022-08-19:
Question answered, closing issue.

ffrediani, 2024-05-18:
@kdmukai @irae just added a Feature Request for ESP32 with some details and options. Please check out and comment if you have anything to add - https://github.com/SeedSigner/seedsigner/issues/560

Closed 2022-08-19.

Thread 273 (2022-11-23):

Prudently Paranoid Settings

jdlcdl, 2022-11-23:
...for the prudently paranoid user.

Use case:
* User has disabled: Xpub export, Show Xpub Details, and/or a new setting "Seed backup" (which removes this option from the seeds menu)... because these steps have already been done long ago.
* Now the user is moving about, with seedsigner on a battery pack, collecting seeds without turning it off, and continuing on to load more seeds.
* The user's threat model is rapidly experienced increased susceptibility to a violent attack as they load more seeds.

As a solution: Some security-sensitive settings could raise an exception whenever these settings are toggled from disabled to enabled, alerting the user with "You must discard all seeds before enabling this option!"

Thoughts?

jdlcdl, 2022-11-29:
After sleeping on this, I've gone on to expand what is covered by Prudently Paranoid Settings, including sig-types and script-types, but the initial idea hasn't changed.  It's the seedsigner assumption, always erring on the side of caution, that "disabled means disabled and I won't relax these privacy/security settings while keys are loaded."

I've implemented this using existing/new settings definitions, and a new method "settings.is_enabled(a_setting)" that can be used like a question (returning True or False) or like an assertion (raising an exception if disabled).  Within low-level views that arguably should not be accessible when a particular setting is disabled, they'll use settings.is_enabled(a_setting, assert_=True) to raise an ugly exception, disrupting continued flow.  To spare the user from seeing these, higher level views will ask "is_enabled(a_setting)" to avoid offering navigation to functionality that is disabled.

revetuzo, 2022-12-15:
Can you explain the use-case of traveling around and collecting seeds? To sign a transaction, you can just use partially signed bitcoin transactions (PSBT), one seed after another.

jdlcdl, 2022-12-15:
Key material is split in pieces (seedxor style), physically separated (perhaps on the same property, perhaps a short walk, maybe a short drive).

This use case starts at loading seed #0, from the moment you load it into seedsigner and could have had a chance to secure it by putting your seed-qr back in the safe and locking it, to the point you shutdown/pull-power.  With prudently_paranoid_settings: you might have seed-backup, address-explorer, and export-xpub disabled... meaning these tools would not leak their info... and seedsigner would still be capable to sign a PSBT from a known wallet... less capable to attacker who doesn't already know your utxos.

jdlcdl, 2022-12-15:
I also like what it does to the assumption of:

If you see someone with a seedsigner who just had it turned on... they've got full knowledge, or recorded seed material on them at this very moment.

That would not be a correct assumption if you and I were face to face and I just signed a transaction in front of you.  A better assumption would be that I'm not even capable of loading my keys without running around in front of public cameras... and even if you can take my seedsigner from me while it's still turned on... you won't learn more than my fingerprint.

jdlcdl, 2022-12-16:
> Can you explain the use-case of traveling around and collecting seeds? To sign a transaction, you can just use partially signed bitcoin transactions (PSBT), one seed after another.

I am not building an argument that scanning a psbt 2x per seed, with distance/obstacles/people in between is to be replaced by prudently_paranoid_settings.

I also will not rebut the argument that it could imprudently enable users to take bad habits, where keys that "ideally" should be separated end up hanging-out together regularly.  Realistically, I suspect this already happens in private households, that multiple keys are stashed discretely yet accessible, and I'm arguing that prudently_paranoid_settings might be desirable in the majority of seconds between scanning those accessible yet hidden/locked-up SeedQRs and locking them back up immediately, signing whatever is to be signed, and powering off.

jdlcdl, 2022-12-16:
As far as sig_type and script_type being included... which add a little bit of clumsy granularity, this was just me fleshing out the idea to its extremes... that are likely not so useful.   It'd be a stretch to imagine the usefulness of a completely disabled seedsigner.   Anyways, for me to propose ideas as complete as I can + an implementation, and for others to pick and choose.

kdmukai, 2022-12-16:
Concept NACK.

> [added]: Consider the amount of seconds in the lifetime that seedsigner is running with any particular seed loaded.

This is the most compelling part of the argument. But I keep coming back to two basic counterpoints:

1. I don't like the idea of relying on UI settings as a form of security. We do allow for an increasingly flexible way of turning features on or off in Settings, but that's meant to alter the user flows to customize it for experts vs noobs. Using the UI as a security barrier does provide some value but isn't strong enough to live up to more naive users' expectations. Even with all the appropriate warnings, I'm still hesitant to encourage anything that could create a false sense of security. Plus if the most likely use case is during the short time the seed is loaded, then the seed backup words/SeedQR would be in the vicinity and would remain the bigger risk vector.

> but if among all that time you get distracted...

2. I've thought for a while that we should have an optional "Wipe after X time" Setting. Right now a SeedSigner will hold any seeds in memory for as long as it sits plugged in. A configurable option to wipe after 5 min, 10 min, X hrs, etc of idle time would be a nice safety measure that should probably default to ON. And/or a secondary setting that powers down the SeedSigner after X time.

EverydayBitcoiner, 2022-12-30:
> 2. I've thought for a while that we should have an optional "Wipe after X time" Setting. Right now a SeedSigner will hold any seeds in memory for as long as it sits plugged in. A configurable option to wipe after 5 min, 10 min, X hrs, etc of idle time would be a nice safety measure that should probably default to ON. And/or a secondary setting that powers down the SeedSigner after X time.

This was discussed in issue #142.

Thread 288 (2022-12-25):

[Enhancement] Warning on shutdown

EverydayBitcoiner, 2022-12-25:
As I've been poking around on seed signer and playing around with some other HWW/signing devices I am wondering if there should be a warning when a user goes to shutdown or restart making sure that the user knows that the seeds will all be forgotten on power off. This is something that is obvious to power users, but I'm thinking about the newbiests of newbs and making sure they don't misunderstand and think their keys will be stored over restart because a different wallet they have used did that. As I'm thinking about this I also am conscience that we do not want to overuse warning pages, but thinking this could be a possibility.

I am not sure how this would interact with the (I think reasonable) feature request for auto shutdown or lock after given period of time in issue https://github.com/SeedSigner/seedsigner/issues/142.

jdlcdl, 2022-12-25:
This is just my very personal opinion on noobs vs powerusers, I'll never be the one to step much out of my way to protect noobs from themselves while pushing the cost/noise/confusion/even-an-extra click on to powerusers.  The only case where this warning might be helpful to a noob is when seedsigner has created a brand new seed since it was powered on, and at that time the user has already seen warnings, reviewed seedwords and verified/skipped-verification; all other uses of seedsigner imply that the user has safely backed up their seed or decided to commit it to memory.  Perhaps if a noob creates a seed, exports xpub and creates a wallet in coordinator, and funds utxos all in the same session -- without backing up their seed -- they deserve to learn the hard way?

There is some free screen real-estate in the power options menu where perhaps a warning that the next action will nuke machine state... and I happen to like it clean, but a warning triangle might be appropriate there.

This might be a strong non-friendly noob opinion, but it's just mine... it stems from my very strong belief that everyone is capable and that sloppy incompetence is mostly a lack of will and rarely a lack of capacity.

kdmukai, 2022-12-25:
> all other uses of seedsigner imply that the user has safely backed up their seed or decided to commit it to memory.

This is a well-argued point. I mostly agree with @jdlcdl.

That being said, rather than have a warning, I could see some value in simply stating the fact: "All seeds will be cleared from memory" or something like that. It's not a warning so much as it is a reassurance.

But I don't think it's necessary. The proof is in the next time you turn it on, of course.

And we always have to remember that people don't read messages. Each screen should try to communicate one and only one thing to the user--and even then it'll get ignored a lot of / most of the time. So if we were to try to put two messages up (wait 30 secs to unplug; all seeds will be wiped), it becomes probably exponentially more likely that neither message gets read.

Longer term, I've been wanting to think through a "super-noob" onboarding mode that has almost everything stripped out of the UI and is more of a guided step-by-step experience. Like when you turn it on, it should only offer two choices: Set up a wallet or Create a new seed.

In this kind of mode, I think a standalone explainer screen on powerdown could work. It's not meant to be displayed every time (hopefully the user graduates from super-noob mode quickly-ish), but is part of the difficult onboarding process.

EverydayBitcoiner, 2022-12-25:
Oh, I kind of like the idea of a tutorial/walkthrough mode for first time users. Though I'm not sure about stripping out the UI considering the idea is to get the user used to the interface is. I would rather a new mode include explainer screens and prompts, but maintain the same UI otherwise. That said, I'm thinking that currently this would be a low priority project given that it's probably easier and more effective at the moment to simply make walkthrough videos and explainers.

On the topic of a shutdown warning I'm convinced it's not needed. Going to close out this issue as not needed, but may open up a low priority feature issue for a tutorial mode.

Closed 2022-12-25.

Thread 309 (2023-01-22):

[Feature] Add an option to generate a new seed via coin flips

kdmukai, 2023-01-22:
Coin flip entry can use the keyboard UI w/custom keys to just "H" and "T".

Probably makes sense to break the task into chunks of 11 flips (each word = 11 bits) and flip for one word per screen.

For human stupidity reasons, I would not display the resulting word while flipping (reduce the odds of people fudging their flips so they can hand-pick their favorite word).

Flow:
* Tools -> (coin icon?) New Seed
* 12- or 24-word seed?
* Word #1 (keyboard UI w/just very large "H" and "T" keys; display output as "H" and "T" but convert to 1/0 under the hood). Include note that heads = 1, tails = 0). After 11th flip, enable a "Next" button or something.
* Word #2... Word #11...
* Final Word: forward straight to the existing Final Word screen that supports coin flips for the checksum calc. Alter the explainer screen so that coin flips are the ONLY option (instead of listing options, just replace with a "Next" button).
* Flow from that Final Word screen then takes over. Checksum word is calculated, mnemonic is displayed, user is given the option to do the quiz to test that they wrote their mnemonic down correctly.

Options/Bonus: Maybe enrich the final mnemonic word display to include the raw bits for each word?

mister-1-wizard, 2023-02-04:
Thanks for this, Keith. Let me know if I there is anything I can do to help (I'm new to Github and fiat job is crazy busy at the moment, but will be glad to learn/help if no time pressure).

Here are some additional thoughts I had (please feel free to ignore what is impractical; goal in mentioning now is to try to leverage effort -- get most bang-for-buck -- while still in brainstorming stage):

(1) For faster and for better entropy with coin toss method, user may throw 11 coins at once (mentioning here in case affects UI/overall flow)

(2) I wonder if simultaneous with this it might be possible to work XOR into flow; for example, user loads two seeds (e.g., one generated from image and one generated by dice or coin toss) into first two seed slots, button press causes XOR of seeds in slots to be written to slot 3

(3) Where user wants to do (2) recursively, user moves XOR output at slot 3 to slot 1, generates new seed at slot 2, and presses XOR button again to write XOR of slots 1 and 2 to slot 3

kdmukai, 2023-03-05:
@mister-1-wizard for your (2), if we have coin flips as an entropy source to begin with, I don't see much value in an XOR option built on top.

If you want the "good" entropy of coin flips, use coin flips to generate a new seed. Full stop.

So to me, (2) is a completely separate issue (implement SeedXOR), which I remain skeptical/hesitant on.

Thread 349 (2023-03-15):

Feature Request: No screensaver when showing flickering QR Code

petzsch, 2023-03-15:
Hi,

I've just been playing around with a very large transaction (167 inputs) and noticed that there are some problems, most related to my webcam scanning this (changing focus and stuff that I need to take care of)

However the seedsigner showing a screensaver every so many minutes has become a real problem.

Could you disable the screensaver when showing a QR code that is flickering?

Would be much appreciated. :-)

SeedSigner, 2023-03-15:
Wow -- 167 inputs is quite a few but could me more common than people think with regular DCA transactions and UTXO consolidation.

This is of course a reasonable request -- I've also had the screensaver come up when I was transcribing a SeedQR which was less than ideal. What might make the most sense is to extend the time before the screen saver comes on when a user is engaged in either of the above activities. If a user happens to leave a device unattended for many 20-30 mins while displaying PSBT QRs, or if they were to get interrupted during SeedQR transcription, we may still want the screen saver to come in eventually at some point to prevent burn-in.

I'm curious with your webcam if you have a static resting place for the signer, or are you holding it up to the webcam the entire time? If you're holding it up and routinely do these kinds of large transactions, you might consider a setup where you can secure the SeedSigner in a fixed position. My favorite setup for these larger transactions is to use my phone as a tethered webcam (now native on MacOS, and apps like EpocCam also facilitate this) and position both the phone and signer in static positions during transfer. If you hadn't seen it, there's also a setting for high QR density in the signer's advanced settings that will reduce the amount of frames that need to be passed back through your webcam.

Thank you for raising this, it's something we should definitely address.

petzsch, 2023-03-16:
> if you have a static resting place for the signer, or are you holding it up to the webcam the entire time?

I had put the seedsigner and the camera on my desk looking towards each other. Still the camera (Brio 4k Stream) kept on loosing focus, everytime I had reset the screensaver. In that case I had to point the camera at something far away and then back at the device and it would keep focus. As said, that is something I need to look into, maybe the logitech software which I hadn't installed thus far, allows manual control of such "features".

Just FYI, I also tried using the seedsigner with BTCPay Server and ran into some [issues](https://github.com/btcpayserver/btcpayserver/issues/4777). I hope that the team gets them sorted out. :-)

Love the little devices... really awesome. ❤️

SeedSigner, 2023-03-16:
Thanks so much for opening that bug report with BTCpay. I've attempted to sign with SeedSigner in their UI and it's been on my to-do list to to open an issue. With the browser interface, our signer seems like a perfect fit for when their users want to withdraw funds.

kdmukai, 2024-09-20:
Bump! This is still an issue in v0.8.0.

@newtonick can you tag this for v0.9.0?

cc: @bitcoinprecept

kdmukai, 2024-09-20:
First cut at some updated rules to debate. Screensaver activates after...:
1. Animated QR: 10 minutes? Never?
2. Static QR: 2 minutes (no change)
3. SeedQR transcription UI: 2 minutes (no change)
4. Camera live preview: Never (already implemented, I think)

1.) I could go either way. Maybe leaning towards "Never", but with an asterisk explained more below.

2.) Seems uncontroversially fine to me.

@SeedSigner noted that he ran into 3.) when stamping into steel. I think the screensaver kicking in is a mild annoyance in that case but not really disruptive.

4.) Must remain "Never"; any time the camera is on, user must be aware of it.

---

*(As a separate TO-DO, I think it's worth considering a UX timeout option (ON by default) to protect the user in the worst-case scenario where they happen to walk away in the middle of 3.) and it's still running (actually, similar risk if it's abandoned at ANY point when a seed is loaded). If the max timeout is reached, the UX would completely wipe / reset / power down)

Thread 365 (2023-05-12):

Error with seed generation from camera entropy on Pi4/Seedsigner 0.6.0

bitcoinprecept, 2023-05-12:
Seedsigner Telegram community member @sliceofsteak discovered a bug when generating a new seed from camera entropy. The error message is displayed here:
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

Hardware used: Raspberry Pi4
Software used: Seedsigner 0.6.0

NOTE: Issue has not been recreated by any of the Seedsigner contributors at time of this writing.

TLDR from lead developer @kdmukai I think from threading import Lock is the answer. Though being able to reproduce the race condition is step 1, otherwise we have no way to verify if a fix helps.

Fuller context:
The issue initially seemed to be triggered by doing seed generation on TestNet rather than MainNet, possibly generated from Python pillow, but some real-time troubleshooting by the community indicated this may not exactly be the cause. Dialogue:

@jdlcdl Can you re-explain exact flow?  I'm trying, with advanced network setting on testnet, both "new seed" from top of tools menu, or from the seeds menu/Load a seed/Create a seed/New seed work for me in 0.6.0

@sliceofsteak If I go Tools-> New camera seed, do nothing and go back, then do it again, then repeat several times it always spits the error after a while

@kdmukai Sounds like something in the camera initialization/reset state then. Some race condition that doesn't quite complete when certain actions are piled on top of each other. PiVideoStream.start() launches a background daemon process. Anything related to threading could easily suffer race conditions, esp on a much faster cpu. The debugging messages printed to the console should help (requires a dev build running while ssh'ed in). Most likely there's some part of the thread shutdown sequence that isn't complete by the time the next camera thread tries to start itself. So probably/maybe/possibly you could create the same error by just going to Scan -> back -> Scan -> back...

@sliceofsteak No, just the wallet creation

@kdmukai The only major difference is that the ScanScreen (going straight to the "Scan" option) creates a second thread to run the live preview. But the image entropy just does it in the main program thread. So the ScanScreen's second thread creation may itself be a kind of unintended thread lock that gives the camera's thread time to complete before any camera data access is attempted. Maybe PiVideoStream needs a threadsafe Lock (see the Renderer). Claim the lock to update the latest frame and also when asked to read the latest frame. The lock forces a threadsafe wait until released. If that fixes the pi4 race condition, I'd be a little surprised that we never ran into problems with threading race conditions before.

https://stackoverflow.com/questions/69993959/python-threads-difference-for-3-10-and-others

In this case python3.10 suddenly started yielding CORRECT behavior (as if threadsafe locks were used) vs 3.9. But if I'm understanding this, it sounds like python3.10 will swap threads faster(?). So maybe we now have an increased chance of interrupting the stream read into the variable.

Initial Conclusion: I think from threading import Lock is the answer. Though being able to reproduce the race condition is step 1, otherwise we have no way to verify if a fix helps.

satscoffee, 2024-01-17:
I had this same issue with a Raspi 4 and 0.7.0 as well. Video attached and you can see the camera works for scanning a QR but when you generate a seed with entropy, it throws the error.

Also once the error was encountered the only way to reset was to turn off completely. A reboot would not reset the error but a complete power-off would.

https://github.com/SeedSigner/seedsigner/assets/123999813/6f1098a2-da27-4b82-bed7-115bfc86721a

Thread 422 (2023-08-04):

frank-s01-v1.0 crashes

matheusdiogenesandrade, 2023-08-04:
Hello.

Recently, I obtained a fresh DIY seedsigner kit. After embedding it and turn it on, I tried to use the camera. However, two seconds after the camera appears, seedsigner crashes, to the point no command from the buttons work, i.e. doesn't matter what I press, nothing happens. I tried to reinstall the seedsigner software again in the SD card. But no result. Then I tried to turn it on out of the seedsigner box (that orange one), but no results as well. I would like to know if some has faced such a issue before.

Update 1: The same issue happens when performing an I/O Test. The message "Capturing image..." freezes in the screen.

Update 2: The problem still manifests when connected to either wall cable or a power bank.

Update 3: Reconnecting the ribbon, so far, doesn't present any effect.

Update 4: Flipping the ribbon makes seedsigner states that the camera cannot be used, thus, the current ribbon side is the right one.

Thanks and best regards.

jdlcdl, 2023-08-04:
Camera issues are frequently related to (in order):
* a power supply that is not sufficient, try another with a higher output-amps rating.
* a bad camera ribbon connection at the raspberry pi board.  Disconnecting that ribbon and reconnecting it, even if it appears like it's seated properly, fixes many problems.
* the ribbon can be inserted upside-down without it being obvious that this is incorrect... it fits perfectly the right way and the wrong way.  The electric connectors on the ribbon must be facing down against the pi0 board when inserted into its connector.

matheusdiogenesandrade, 2023-08-04:
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

Thanks for the attention, but the issues still persist. Updates in the initial issue description.

newtonick, 2023-08-04:
I've seen this issue with power supply issues in the past. Have you tried running an older version of seedsigner (like release 0.5.1)? https://github.com/SeedSigner/seedsigner/releases/tag/0.5.1

If the power supply is not the issue, give the older OS a try to help diagnosis if something software related is influencing the crash/freeze your experiencing.

Closed 2023-08-04.

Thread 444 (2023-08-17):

[Exploration]  Port SeedSigner to the NumWorks open graphing calculator?

keegreil, 2023-08-17:
Hi!  This idea is not SeedSigner specific, but since SS's ethos is multiplying easy access to Bitcoin signing devices, especially through repurposing other hardware, this seemed like the best community to put this idea to.

The NumWorks graphing calculator is an open source effort to enable high school math education.  It's ARM7 based (STM32F730V8T6, same chip family as ColdCard and many other wallets).
[](https://www.numworks.com/)

Here's some of the advantages to using this as a signing device:

- Totally innocuous design and primary purpose.  It's a calculator dude.  Easy to hide in plain site, or take with anywhere.
- Some countries charge much lower import taxes for calculators than for other electronics devices, so this might be easier to ship around.
- There's a whole grassroots effort to get these devices widely distributed to high school kids that has nothing necessarily to do with Bitcoin per-se (though it'd be great to get kids into Bitcoin and math at the same time!)
- Much more limited, fully open source code base compared to SeedSigner and more complex devices.  Smaller attack surface.
- OS already implements "Test Mode" (as in, for taking standardized tests like SAT without cheating), which deletes all recent inputs and memory.  Also has a hard "Reset" which completely wipes the device and restores it to factory firmware.  So possibly more verifiably "stateless".
- The ROM chip includes a "deep power down" mode, which prevents ANY data from being written to the chip at a hardware level, further assuring its "statelessness."
- Integrated Li-Po battery
- Huge beautiful screen for displaying QR codes.
- Tons of buttons for user input.
- The STM32 does have some security features which isolate sections of code and memory.  I'm sure its nowhere near as good as a proper secure element.

Here's some disadvantages:
- Input would be hard.  Either the PSBT would have to be sent over USB cable, or typed in manually.  It might not be hard to type given the comfortable amount of buttons, but could take a while and be error prone.
- The private key would have to be typed by hand each time (no QR scanner input).
- OS code and "apps" are written in C++, so we couldn't port SS code directly.  Perhaps we could port over Bitcoin Core wallet code however, or maybe even some of ColdCard's.
- Would require frequent USB connections, to re-load the Bitcoin wallet code, since the workflow would likely require a hard reset to factory firmware each time it is used.  Possible mitigations are to fork the OS code itself and install custom firmware that includes the Bitcoin wallet app (so it doesn't dissappear each time, just the wallet data does).
- Careful checking of the signed transaction for correct addresses would be required before transmitting to the blockchain, since the stateless model and frequent USB connections means trust in the device itself should be very low.  We're really just using it as a calculator to do the ECDSA and SHA-256 math and then nuking it each time, rather than do them by hand with pencil/paper.  It's highly likely that it would be actively trying to leak the private key from the moment it is entered until we hit the "RESET" button.
- The display may be more susceptible to TEMPEST style attacks than SS (way out of my depth on this one, but I think ColdCard uses a very specific serial communication protocal for the Q1 to at least mitigate this a little bit).
- No secure element (but you already knew that.  If SE is a must buy a CC).
- Compared to ColdCard Mark 4, this STM supports only AES encryption/decryption natively using its own hardware accelerator.  The CC Mk4 "MCU implements SHA-256 and AES natively for quicker encryption/decryption."

So, that's my idea.  Use the NumWorks graphing calculator as a covert signing device.  I'd love to your thoughts, positive or negative!  What major roadblocks am I missing?  Would this be useful to the community?

SeedSigner, 2023-08-17:
I like the creativity of this idea and I can tell you've put a good amount of thought into it. The display for numworks unfortunately doesn't look like it would offer an advantage over our current display; according to their specs the resolution is 320x240 pixels (https://www.numworks.com/specs/).

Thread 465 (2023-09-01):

Seedsigner hangs when SD card is removed

deepfriedbrain, 2023-09-01:
Thanks for this wonderful project.

I have built my seedsigner device and started to use it. As such it's working smoothly as expected, but I noticed that after successful boot if I remove the SD card, the device hangs and stops responding to the button inputs. I waited more than a minute to remove the SD card. I have persistent settings disabled.

Is this expected?

jdlcdl, 2023-09-01:
What you describe is not expected behavior.

Can you reproduce this over and over again?  It almost sounds like there is a problem with buttons, but then I'd expect that to occur with or without removing the sd card.

deepfriedbrain, 2023-09-01:
Yes, I can reproduce it consistently. Did it again after seeing your message, and it hanged within 5 secs of removing the card while I was just moving around on the 4 tiles of the home screen. With the SD card inserted, it has not hanged even once.

Reinserting the card doesn't do anything. The screen is completely frozen and would not respond. There's no green message either.

Note that I'm using it with RPi4 8GB temporarily (until I get a Zero), and it's using the only supported Waveshare hat.

Initially I thought it could be an issue with the power supply from my power bank. So, I connected with the official RPi 15W Power Supply, and could still reproduce the issue consistently.

deepfriedbrain, 2023-09-01:
Also, I'm not sure if it matters but thought I should mention it, the Seedsigner package was built on a RPi 3B manually from the source code following the instructions from the project docs. Now I'm using it with RPi 4. Does it matter?

jdlcdl, 2023-09-01:
I believe that the rpi 3b uses the same architecture as a the pi zero 2w.

For the rpi 4, you'd want to use the rpi4 image, but if an rpi3 was used to build for rpi4, then it might be fine.  Not sure.

The pre-release is here:
https://github.com/SeedSigner/seedsigner/releases/tag/0.7.0-rc1

The image you want is named seedsigner_os.dev.pi4.img and will have the following sha256 hash:
554756f0be105bfa184be2d9d1b67afc43e59b27bf359b59a8d035f65fd6b77c

kdmukai, 2023-09-01:
@deepfriedbrain Removing the SD card only works if you use a v0.6.0+ release image or build your own using SeedSigner OS:
https://github.com/SeedSigner/seedsigner-os

It sounds like you followed the dev build installation steps in the main repo, which uses the original Raspberry Pi OS image. Can you confirm?

deepfriedbrain, 2023-09-01:
The version shown on the flash screen at startup is 0.7.0. I followed the instructions here:

https://github.com/SeedSigner/seedsigner/blob/dev/docs/manual_installation.md

The raspios image file I downloaded is named 2021-05-07-raspios-buster-armhf-lite.img

I did the installation around 2 weeks ago, but today was the first time actually using it. Should I do it again on the RPi4 itself?

I also noticed another case when it hangs intermittently even with the SD card in the slot. When I click on Scan and move the camera around, it hangs after about 10 secs. This is more intermittent. Happened twice today, but not reproducible right now.

jdlcdl, 2023-09-01:
LOL, I totally missed it.  Keith is spot on.

You're running a Manual Installation which does not support removal of the microsd card.  It is indeed the latest version, but the way you're setup is more for development with a complete linux system.  The version which is meant to allow microsd card removal is the seedsigner-os build... a stripped down -- only what seedsigner needs linux system built specifically for seedsigner.  It has no usb data, no wifi drivers, no hdmi console.

If you want to develop your own seedsigner, or help seedsigner development, you've built the correct raspi-os version for development... but won't be able to remove your microsd card.

If you want to use your seedsigner in a much more secure manner, where you can remove the microsd card, you'll want to download the release candidate, or the official release which feels like it could be ready any day now.  And you can also build it yourself, reproducing the same binary as the official release.  For building that yourself, see https://github.com/SeedSigner/seedsigner-os

Please excuse my confusion, I'd completely misunderstood this issue.

deepfriedbrain, 2023-09-01:
Thank you, it's clear now. It wasn't clear from the documentation. I'll build the seedsigner-os image this time and update the results.

I'll keep an eye on the pi4 freezing issue with the camera on. It happened with the official 15W power supply.

I truly appreciate the great support to go along with an awesome software.

kdmukai, 2023-09-01:
@deepfriedbrain for camera freezing issues, definitely try:
* different power supply (but a 9V battery connector will not work reliably)
* different usb cables
* double check both ends of the camera ribbon cable
* If using the standard Raspi camera (has its own daughterboard), the little camera module itself is just kind of stickered onto the daughterboard and that sometimes needs to be re-seated.

kdmukai, 2023-09-01:
@deepfriedbrain Oh, also consider updating the manual build instructions to make this distinction more clear (dev build uses Raspi OS to enable ssh, debugging output, etc BUT cannot remove the SD card vs SeedSigner OS for production purposes) in the docs.

If you view the manual build instructions on github and just hit "." (period), that should launch github's web-based VS code environment which makes it easy-ish to edit and submit a PR.

deepfriedbrain, 2023-09-02:
Update - I was able to build seedsigner-os for rpi4. It took a good 5+ hrs on my RPi 400, but works flawlessly without the SD card now. Thank you so much!

Closed 2023-09-02.

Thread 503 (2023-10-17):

Failed to sign PBST

DFireTech, 2023-10-17:
Hello all!

I'm mobile currently, so, will add photos later on for context

# Issue
I import my seed to sign a pbst from BlueWallet to a hot wallet and when I get to the parts where I should be signing here is what happens:

Scan PBST from BW
Screen with "Select Seed" shows with `seed (?)`
Click through
"This seed does not add valid signature"

## Expected behavior
PBST is signed

# What I have done

I wonder if this is an issue I caused by having to swap Pi zeroes because my camera module stopped working on my other pi zero.

Thanks for your time (and probable good criticisms)

DFT

jdlcdl, 2023-10-17:
I'm wondering if this is the same as a known issue where bluewallet had an xpub imported to create the wallet, but the format is not the same as seedsigner would export it.  Both types are valid, but if the wallet in bluewallet was created from an xpub exported directly from seedsigner, then it also has the wallet's master fingerprint... which helps seedsigner to identify which seeds are required to sign it.  If that's the case, then importing the xpub into bluewallet from seedsigner is the trick that works.  BUT, be sure that you have backups of your wallet just in case... before you go about deleting the wallet in bluewallet and trying to recreate it directly from seedsigner.

HoferBit, 2023-10-30:
> I'm wondering if this is the same as a known issue where bluewallet had an xpub imported to create the wallet, but the format is not the same as seedsigner would export it. Both types are valid, but if the wallet in bluewallet was created from an xpub exported directly from seedsigner, then it also has the wallet's master fingerprint... which helps seedsigner to identify which seeds are required to sign PSBTs. If that's the case, then importing the xpub into bluewallet from seedsigner is the trick that works. BUT, be sure that you have backups of your wallet just in case... before you go about deleting the wallet in bluewallet and trying to recreate it directly from seedsigner.

thank you, this is my issue

Admin661, 2024-05-30:
Is the issue resolved yet? You'll have to rectify with the BW weblink and try it again.

Radiokot, 2025-05-10:
@jdlcdl hey, thanks for the advice, this is still relevant for BlueWallet XPUBs.

Closed 2024-05-31.

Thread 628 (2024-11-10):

[Feature Request] Enclosure for WaveShare 19739 Battery HAT Extension

kokokale, 2024-11-10:
I'm not sure if there has been any previous discussion around adding on-board power to the SeedSigner or not, but I would personally really love the ability to go entirely wireless with this device.  Hardware and 3D modeling are not one of my skillsets, but I believe that with some minimal modifications we can extend existing SeedSigner enclosures to fit this WaveShare Power-Supply HAT: https://www.waveshare.com/ups-hat-c.htm (See images in product listing for an example of this HAT stacked with the 1.3" WaveShare display SeedSigner currently uses)

I can see a few things to consider here:
- This HAT is sold with 4 mounting screws for the Pi.  Personally, I would love the rigidity that comes with this style mounting, but understand if the best approach is to have the enclosure handling this, as the enclosure I personally have does with the Pi Zero board and 1.3" display/controller HAT.
- I believe this HAT can be mounted and supply power through just the GPIO pins without any modifications to the existing SeedSigner hardware or software.  If this feature is to be adopted in future enclosure designs, I'd be happy to create an issue to add battery monitoring with a GUI display of battery charge levels, and assign to myself.
- I'm aware that this will likely involve moving the camera port in the enclosure, but I believe we have enough long enough ribbons on the currently tested cameras to just offset the port.  If keeping the port location fixed is a hard requirement, maybe we can find a slightly longer ribbon.
- I'm not aware of any excess heat this setup may generate, but it's possible we may need to include some ventilation slots in this new enclosure design.

Since this design is currently untested, I understand if we would like proof-of-concept before proceeding.  This request is mainly a request for comment and to gauge interest.  I am currently in the process of setting up my SeedSigner, and after everything is functional, I would be happy to purchase and test this hardware for myself and report back my results.

Rob0xFF, 2024-11-12:
Please see my enclosue here for reference, hope this might help. Battery monitoring would be great.

[](https://www.printables.com/model/1069037-seedsigner-enclosure-for-ups)

SeedSigner, 2024-11-12:
I appreciate your interest and creativity here, but the project will likely never officially support any kind of build that includes a battery. The assurances around a SeedSigner's stateless nature arise out of power being completely disconnected from the device, so that the data in memory can clear. Adding a battery also adds the potential for a trickle of power that could cause the device to retain information about private keys that have been created or used with the device.

kokokale, 2024-11-12:
Thank you for the response.  I understand the security concerns with this model, so I won't create any MRs to this project for battery support.

Closed 2024-11-12.

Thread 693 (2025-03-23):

[Enhancement] Customize `gettext` with more robust error handling

kdmukai, 2025-03-23:
Some complex translation strings include named variables that must be included in the translation strings for each language.

e.g.
```python
# TRANSLATOR_NOTE: Final word calc. `mnemonic_length` = 12 or 24. `num_bits` = 7 or 3 (bits of entropy in final word).
text=_("The {mnemonic_length}th word is built from {num_bits} more entropy bits plus auto-calculated checksum.").format(mnemonic_length=self.mnemonic_length, num_bits=self.num_entropy_bits)
```

But the current German translation is:
```python
{}es Wort wird erstellt aus {} mehr Entropiebits plus errechneter Prüfsumme
```

Where the empty brackets `{}` aren't compatible with the newer named variable approach.

For clarity, the translation string should be:
```python
{mnemonic_length}es Wort wird erstellt aus {num_bits} mehr Entropiebits plus errechneter Prüfsumme
```

`gettext` raises the following error in this case:
```
IndexError: Replacement index 0 out of range for positional args tuple
```

That is obviously not the most helpful nor intuitive explanation.

## Initial approach (meh)
I started building a custom Exception class with some manual fields to set:
```python
class TranslationVariableMissingError(Exception):
    """ Raised when a translation does not include the expected named variable(s).

        e.g. source string: "Hello, {name}!" but the translation is "Bonjour!" or
        "Bonjour, {}!" instead of "Bonjour, {name}!"
    """
    def __init__(self, *args, expected_named_variables: list[str] = None, **kwargs):
        # Importing here to avoid circular import issues.
        from seedsigner.models.settings import Settings
        from seedsigner.models.settings_definition import SettingsConstants
        super().__init__(*args, **kwargs)
        self.expected_named_variables = expected_named_variables
        self.locale = Settings.get_instance().get_value(SettingsConstants.SETTING__LOCALE)

    def __str__(self):
        if self.expected_named_variables:
            return f"{self.__class__.__name__}: '{self.locale}' translation likely missing {', '.join([f'`{var}`' for var in self.expected_named_variables])} named variables in the translation string."
        return f"{self.__class__.__name__}: locale: {self.locale} | {super().__str__()})"
```

And then used in the main code like:
```python
        try:
            # TRANSLATOR_NOTE: Final word calc. `mnemonic_length` = 12 or 24. `num_bits` = 7 or 3 (bits of entropy in final word).
            text=_("The {mnemonic_length}th word is built from {num_bits} more entropy bits plus auto-calculated checksum.").format(mnemonic_length=self.mnemonic_length, num_bits=self.num_entropy_bits)
        except IndexError as e:
            traceback.print_exc()
            raise TranslationVariableMissingError(expected_named_variables=["mnemonic_length", "num_bits"]) from e
```

The problem with this approach is that we have to remember to wrap the `gettext` calls with the `try`/`except` custom handling every time. Plus repeating the expected named variables is not DRY, annoying, and a possible minor maintenance problem.

## Better approach
Extend `gettext` itself to always catch these exceptions and, if possible, automatically extract the expected named variables from the source string and populate the error message accordingly. This way, rather than having to remember the `try`/`catch` on each use and all the manual/custom error handling, it would all just automatically happen in our custom `gettext`.

In `seedsigner.helpers.l10n` we would extend `gettext` and then update all our imports:
```python
from seedsigner.helpers.l10n import gettext as _
```

### Additional error handling
Further testing should be done to also catch any cases where the wrong number of blank variable insertions are found in the translation string:
```
source string = "I like {}, {}, and {}."
translation string = "Me gusta {} and {}"
```

AdityaPandeyCN, 2025-04-01:
Hello @kdmukai Hope you are doing well I went through the issues and would like to work on it. I'm thinking of  implementing the enhanced gettext function as suggested in the issue. My plan is to:

1. Create a custom gettext wrapper in src/seedsigner/helpers/l10n.py that can handle variable formatting directly
2. Add clear error messages when translations are missing named variables (like when German has {} instead of {mnemonic_length})
3. Make it fall back to the English text with proper formatting when there's an error
4. Use monkey-patching so we don't have to change imports everywhere

What do you think of it should I proceed with PR.

kdmukai, 2025-04-01:
> 3\. Make it fall back to the English text with proper formatting when there's an error

I have two thoughts here. On the one hand, yes, having a clean fallback would ensure the best possible handling if this were to happen in a production release. Makes sense. Hard to argue against.

But on the other hand, our automated testing processes should find those sorts of errors way before they have any chance of getting to a release. And in the testing phase, we want this to be a showstopper exception. "ERROR! BLAH BLAH BLAH," the test fails or the screenshot generator exits with the error.

We could have this operate in two different contexts: local dev/testing vs production.

If production, fall back to the properly formatted English.

If local dev or testing, fail out with a big error.

But that all being said, this also feels a little bit like overkill. I say just let it fail spectacularly and we better catch it in time.

Also: even if we were to have the production mode fall back, we'd still have to be sure we write test scenarios to verify that the fall back works as expected. That could maybe get messy trying to juggle: "When we're testing, don't use the fall back, but during THIS test, pretend that we're NOT testing so we can test the production fall back..."

kdmukai, 2025-04-01:
Separate thought: we could think about having a test that explicitly goes through each translation string:
* If `n` replacement var `{}` appear in the source string, does the translated string have the same number?
* If a named variable appears in the source string, does the translated string include it as well?
  * And vice-versa: if a named variable is in the translated string but not in the source string, that's also bad.

kdmukai, 2025-04-01:
> 4\. Use monkey-patching so we don't have to change imports everywhere

I'm open to debate on this, but my instinct is that I would want it to be clear that we are using our own custom version of `gettext` (e.g. `custom_gettext`, `seedsigner_gettext`, ... I dunno). So I wouldn't want our version invisibly monkeypatched over the normal `gettext`.

In my proposed custom implementation, we'd be adding optional kwargs to `gettext`. If a new developer is unfamiliar with the history here and they search for how to use `gettext`, they'll be confused that they can't find any info about how the kwargs are used (because the original function doesn't use kwargs, only our custom version would).

Yes, such a change would touch many many files, but the code review wouldn't really be any harder since it's just a trivial import change.

AdityaPandeyCN, 2025-04-01:
Thankyou for the feedback, I see what you mean about making errors fail instead of hiding them with fallbacks. That makes a lot more sense for catching bugs early. I'll create a function called seedsigner_gettext instead of doing the monkey-patching thing. I think you're right that it's better to be clear about using our own custom function rather than hiding it.

kdmukai, 2025-04-01:
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

Logged this as its own Issue here: https://github.com/SeedSigner/seedsigner/issues/700

kdmukai, 2025-04-01:
> I'll create a function called seedsigner_gettext

I don't know that I love that name. But I don't necessarily hate it, either! Usually naming things is really tough for me and I agonize over it maybe a bit more than I should.

kdmukai, 2025-04-02:
Very basic sanity check: Does the test succeed when running against the unmodified `gettext`?

The translations are loaded via a git submodule that might not be initialized in a local dev setup. I believe it's:

```
git submodule init
git submodule update
```

AdityaPandeyCN, 2025-04-02:
This worked, Thankyou for this also I have created a PR #702 Please Take a Look when time permits.

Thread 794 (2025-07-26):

IO test issue

pycanis, 2025-07-26:
Pressing the Key3 triggers joystick left button. This is a problem when scrolling to select seed words. Any idea why do I have this issue and is there a way to fix it?

kdmukai, 2025-07-26:
Post a photo of the back of your Pi Zero. Those particular pins are an odd combo to be linked, but most likely some bad soldering.

kdmukai, 2025-07-26:
Not sure what to make of it. Any ideas @jdlcdl?

pycanis, 2025-10-02:
The issue was with the Pi.

Closed 2025-10-02.

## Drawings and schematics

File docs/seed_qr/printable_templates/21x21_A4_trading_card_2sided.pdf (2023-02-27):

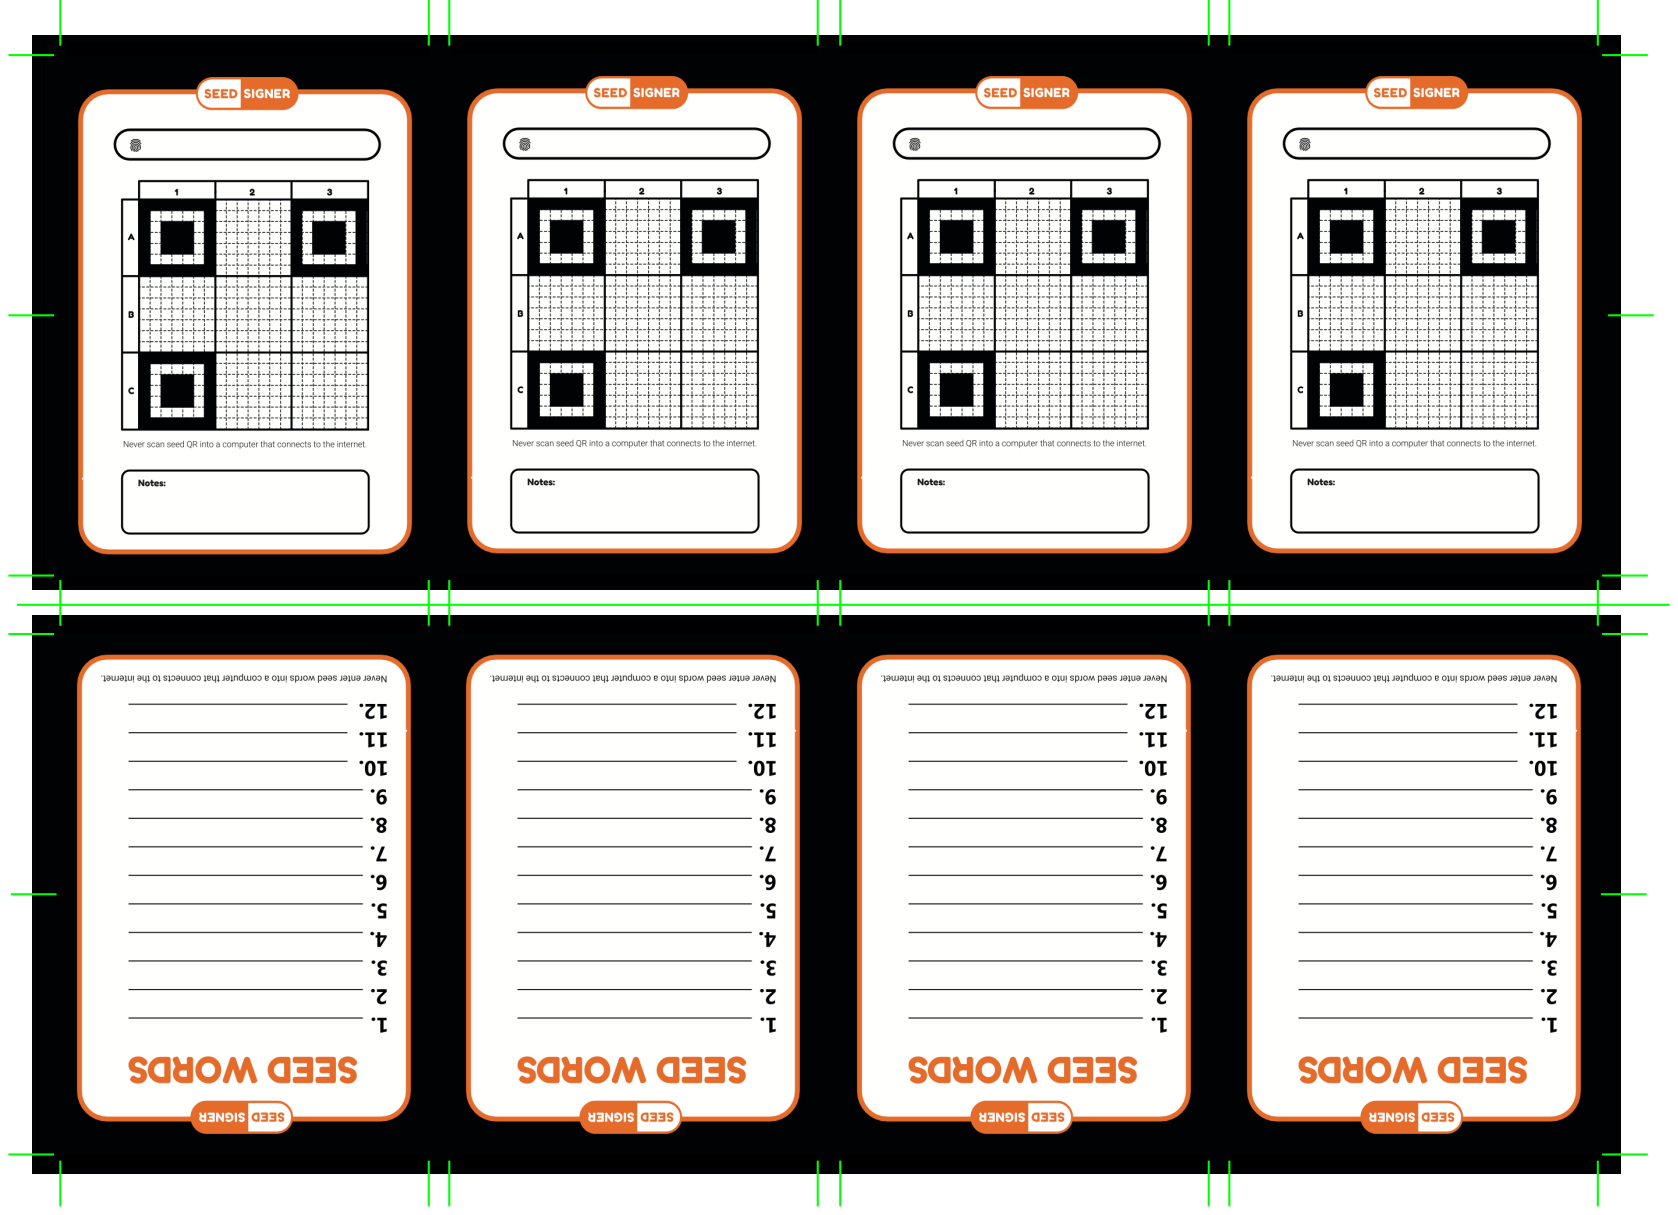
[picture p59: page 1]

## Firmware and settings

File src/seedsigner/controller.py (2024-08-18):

import logging
import time
import traceback

from embit.descriptor import Descriptor
from embit.psbt import PSBT
from PIL.Image import Image

from seedsigner.gui.toast import BaseToastOverlayManagerThread
from seedsigner.models.psbt_parser import PSBTParser
from seedsigner.models.seed import Seed
from seedsigner.models.seed_storage import SeedStorage
from seedsigner.models.settings import Settings
from seedsigner.models.singleton import Singleton
from seedsigner.models.threads import BaseThread
from seedsigner.views.screensaver import ScreensaverScreen
from seedsigner.views.view import Destination


logger = logging.getLogger(__name__)



class BackStack(list[Destination]):
    def __repr__(self):
        if len(self) == 0:
            return "[]"
        out = "[\n"
        for index, destination in reversed(list(enumerate(self))):
            out += f"    {index:2d}: {destination}\n"
        out += "]"
        return out
            


class StopFlowBasedTest(Exception):
    """
        This is a special exception that is only raised by the test suite to stop the
        Controller's main loop. It should not be raised by any other code.
    """
    pass



class FlowBasedTestException(Exception):
    """
        This is a special exception that is only raised by the test suite.
        It should not be raised by any other code.
    """
    pass



class BackgroundImportThread(BaseThread):
    def run(self):
        from importlib import import_module

        # import seedsigner.hardware.buttons # slowly imports GPIO along the way

        def time_import(module_name):
            last = time.time()
            import_module(module_name)
            # print(time.time() - last, module_name)

        time_import('embit')
        time_import('seedsigner.helpers.embit_utils')

        # Do costly initializations
        time_import('seedsigner.models.seed_storage')
        from seedsigner.models.seed_storage import SeedStorage
        Controller.get_instance()._storage = SeedStorage()

        # Get MainMenuView ready to respond quickly
        time_import('seedsigner.views.scan_views')

        time_import('seedsigner.views.seed_views')

        time_import('seedsigner.views.tools_views')

        time_import('seedsigner.views.settings_views')



class Controller(Singleton):
    """
        The Controller is a globally available singleton that maintains SeedSigner state.

        It only makes sense to ever have a single Controller instance so it is
        implemented here as a singleton. One departure from the typical singleton pattern
        is the addition of a `configure_instance()` call to pass run-time settings into
        the Controller.

        Any code that needs to interact with the one and only Controller can just run:
        ```
        from seedsigner.controller import Controller
        controller = Controller.get_instance()
        ```
        Note: In many/most cases you'll need to do the Controller import within a method
        rather than at the top in order avoid circular imports.
    """

    VERSION = "0.8.0"

    # Declare class member vars with type hints to enable richer IDE support throughout
    # the code.
    _storage: SeedStorage = None   # TODO: Rename "storage" to something more indicative of its temp, in-memory state
    settings: Settings = None

    # TODO: Refactor these flow-related attrs that survive across multiple Screens.
    # TODO: Should all in-memory flow-related attrs get wiped on MainMenuView?
    psbt: PSBT = None
    psbt_seed: Seed = None
    psbt_parser: PSBTParser = None

    unverified_address = None

    multisig_wallet_descriptor: Descriptor = None

    image_entropy_preview_frames: list[Image] = None
    image_entropy_final_image: Image = None

    address_explorer_data: dict = None

    sign_message_data: dict = None
    # TODO: end refactor section

    # Destination placeholder for when we need to jump out to a side flow but intend to
    # return navigation to the main flow (e.g. PSBT flow, load multisig descriptor,
    # then resume PSBT flow).
    FLOW__PSBT = "psbt"
    FLOW__VERIFY_MULTISIG_ADDR = "multisig_addr"
    FLOW__VERIFY_SINGLESIG_ADDR = "singlesig_addr"
    FLOW__ADDRESS_EXPLORER = "address_explorer"
    FLOW__SIGN_MESSAGE = "sign_message"
    resume_main_flow: str = None

    back_stack: BackStack = None
    screensaver: ScreensaverScreen = None
    toast_notification_thread: BaseToastOverlayManagerThread = None


    @classmethod
    def get_instance(cls):
        # This is the only way to access the one and only instance
        if cls._instance:
            return cls._instance
        else:
            # Instantiate the one and only Controller instance
            return cls.configure_instance()


    @classmethod
    def configure_instance(cls, disable_hardware=False):
        """
            - `disable_hardware` is only meant to be used by the test suite so that it
            can keep re-initializing a Controller in however many tests it needs to. But
            this is only possible if the hardware isn't already being reserved. Without
            this you get:

            RuntimeError: Conflicting edge detection already enabled for this GPIO channel

            each time you try to re-initialize a Controller.
        """
        from seedsigner.gui.renderer import Renderer
        from seedsigner.hardware.microsd import MicroSD

        # Must be called before the first get_instance() call
        if cls._instance:
            raise Exception("Instance already configured")

        # Instantiate the one and only Controller instance
        controller = cls.__new__(cls)
        cls._instance = controller

        # models
        controller.settings = Settings.get_instance()
        
        controller.microsd = MicroSD.get_instance()
        controller.microsd.start_detection()

        # Store one working psbt in memory
        controller.psbt = None
        controller.psbt_parser = None

        # Configure the Renderer
        Renderer.configure_instance()

        controller.back_stack = BackStack()

        # Other behavior constants
        controller.screensaver_activation_ms = 2 * 60 * 1000  # two minutes
    
        background_import_thread = BackgroundImportThread()
        background_import_thread.start()

        return cls._instance


    @property
    def camera(self):
        from .hardware.camera import Camera
        return Camera.get_instance()
    

    @property
    def storage(self):
        while not self._storage:
            # Wait for the BackgroundImportThread to finish initializing the storage.
            # This is a rare timing issue that likely only occurs in the test suite.
            time.sleep(0.001)
        return self._storage
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

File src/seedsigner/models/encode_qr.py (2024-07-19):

import math

from embit import bip32
from embit.networks import NETWORKS
from binascii import hexlify
from dataclasses import dataclass
from typing import List
from embit import bip32
from embit.networks import NETWORKS
from embit.psbt import PSBT
from seedsigner.helpers.ur2.ur_encoder import UREncoder
from seedsigner.helpers.ur2.ur import UR
from seedsigner.helpers.qr import QR
from seedsigner.models.seed import Seed
from seedsigner.models.settings import SettingsConstants

from urtypes.crypto import PSBT as UR_PSBT
from urtypes.crypto import Account, HDKey, Output, Keypath, PathComponent, SCRIPT_EXPRESSION_TAG_MAP



@dataclass
class BaseQrEncoder:
    qr_density: str = SettingsConstants.DENSITY__MEDIUM


    def __post_init__(self):
        self.qr = QR()


    @property
    def is_complete(self):
        raise Exception("Not implemented in child class")

    @property
    def qr_max_fragment_size(self):
        raise Exception("Not implemented in child class")

    def seq_len(self):
        raise Exception("Not implemented in child class")

    def next_part(self) -> str:
        raise Exception("Not implemented in child class")
    
    def cur_part(self) -> str:
        raise Exception("Not implemented in child class")
    
    def restart(self):
        # only used by animated QR encoders
        pass

    def _create_parts(self):
        raise Exception("Not implemented in child class")


    def part_to_image(self, part, width, height, border: int = 3, background_color: str = "ffffff"):
        return self.qr.qrimage_io(part, width, height, border, background_color=background_color)


    def next_part_image(self, width=240, height=240, border=3, background_color="bdbdbd"):
        part = self.next_part()
        return self.part_to_image(part, width, height, border, background_color=background_color)




"""**************************************************************************************
    STATIC QR encoders
**************************************************************************************"""
@dataclass
class BaseStaticQrEncoder(BaseQrEncoder):
    def seq_len(self):
        return 1
    
    def cur_part(self) -> str:
        """ static QRs only have a single part, which `next_part` always returns """
        return self.next_part()


    @property
    def is_complete(self):
        return True



@dataclass
class SeedQrEncoder(BaseStaticQrEncoder):
    mnemonic: List[str] = None
    wordlist_language_code: str = SettingsConstants.WORDLIST_LANGUAGE__ENGLISH


    def __post_init__(self):
        self.wordlist = Seed.get_wordlist(self.wordlist_language_code)
        super().__post_init__()

        self.data = ""
        # Output as Numeric data format
        for word in self.mnemonic:
            index = self.wordlist.index(word)
            self.data += str("%04d" % index)
    

    def next_part(self):
        return self.data



@dataclass
class CompactSeedQrEncoder(SeedQrEncoder):
    def next_part(self):
        # Output as binary data format
        binary_str = ""
        for word in self.mnemonic:
            index = self.wordlist.index(word)

            # Convert index to binary, strip out '0b' prefix; zero-pad to 11 bits
            binary_str += bin(index).split('b')[1].zfill(11)

        # We can exclude the checksum bits at the end
        if len(self.mnemonic) == 24:
            # 8 checksum bits in a 24-word seed
            binary_str = binary_str[:-8]

        elif len(self.mnemonic) == 12:
            # 4 checksum bits in a 12-word seed
            binary_str = binary_str[:-4]

        # Now convert to bytes, 8 bits at a time
        as_bytes = bytearray()
        for i in range(0, math.ceil(len(binary_str) / 8)):
            # int conversion reads byte data as a string prefixed with '0b'
            as_bytes.append(int('0b' + binary_str[i*8:(i+1)*8], 2))
        
        # Must return data as `bytes` for `qrcode` to properly recognize it as byte data
        return bytes(as_bytes)



@dataclass
class GenericStaticQrEncoder(BaseStaticQrEncoder):
    data: str = None

    def next_part(self):
        return self.data



@dataclass
class BaseXpubQrEncoder(BaseQrEncoder):
    """
    Base Xpub QrEncoder for static and animated formats
    """
    seed: Seed = None
    derivation: str = None
    network: str = SettingsConstants.MAINNET
    sig_type : str = None

    def prep_xpub(self):
            
        version = self.seed.detect_version(self.derivation, self.network, self.sig_type)
        self.root = bip32.HDKey.from_seed(self.seed.seed_bytes, version=NETWORKS[SettingsConstants.map_network_to_embit(self.network)]["xprv"])
        self.fingerprint = self.root.child(0).fingerprint
        self.xprv = self.root.derive(self.derivation)
        self.xpub = self.xprv.to_public()
        self.xpub_base58 = self.xpub.to_string(version=version)

        self.xpubstring = "[{}{}]{}".format(
            hexlify(self.fingerprint).decode('utf-8'),
            self.derivation[1:],
            self.xpub_base58
        )



class StaticXpubQrEncoder(BaseXpubQrEncoder, BaseStaticQrEncoder):
    def __post_init__(self):
        super().__post_init__()
        self.prep_xpub()


    def next_part(self):
        self.prep_xpub()
        return self.xpubstring



"""**************************************************************************************
    Simple animated QR encoders
**************************************************************************************"""
@dataclass
class BaseSimpleAnimatedQREncoder(BaseQrEncoder):
    def __post_init__(self):
        super().__post_init__()
        self.parts = []
        self.part_num_sent = 0
        self.sent_complete = False
        self._create_parts()


    @property
    def is_complete(self):
        return self.sent_complete


    def seq_len(self):
        return len(self.parts)


    def next_part(self) -> str:
        # if part num sent is gt number of parts, start at 0
        if self.part_num_sent > (len(self.parts) - 1):
            self.part_num_sent = 0

        part = self.parts[self.part_num_sent]

        # when parts sent eq num of parts in list
        if self.part_num_sent == (len(self.parts) - 1):
            self.sent_complete = True

        # increment to next part
        self.part_num_sent += 1

        return part


    def cur_part(self) -> str:
        if self.part_num_sent == 0:
            # Rewind all the way back to the end
            self.part_num_sent = len(self.parts) - 1
        else:
            self.part_num_sent -= 1
        return self.next_part()


    def restart(self) -> str:
        self.part_num_sent = 0
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

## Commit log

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2021-06-25 Clears screen on debugging crash or SIGTERM
    Minor convenience when debugging
    [controller.py, view.py]
2021-06-25 Primitive working prototype
    Represents a 12-word seed by its associated WORDLIST indices and renders that as a sparse QR code for manual transcription. Can then import that seed via the same QR code and decode back to mnemonic 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
2021-07-06 Reverting previous; simplified logic
    [seed_tools_view.py]
2021-07-06 Prevent fiddly joystick by requiring release
    [seed_tools_view.py]
2021-07-07 - add scan seed qr to xpub and sign transaction workflow - add prompt for optional passphrase when entering seed for xpub and sign transaction - add Loading xPub Info beforing displaying xPub info an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
    [buttons.py, controller.py, menu_view.py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]
2021-07-07 fix back to main menu text when signing transaction
    [controller.py]
2021-07-09 Adding a few extra error handling steps in animated psbt scanning
    [controller.py]
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2021-07-10 Fixed "del" button in/out nav for adjacent col
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2021-07-11 CameraProcess speedups
    * Copies PiVideoStream from imutils
    * removes imutils from requirements.txt
    * Reduces `start()` wait time.
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2021-07-14 Update settings_tools_view.py
    Fix for previous version info edit
    [settings_tools_view.py]
2021-07-24 Image seed fixes; reduced auto-exposure time
    [controller.py, seed_tools_view.py]
2021-07-28 fix seed from picture bug where after qr or sign scan it crashed
    [seed_tools_view.py]
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2021-08-03 Interim commit
    Basic image entropy flow is working. QR reading not yet ported.
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2021-08-04 missing a few things, fixed qr border, and seed qr gen use encodeqr
    [controller.py, seed_tools_view.py]
2021-08-04 few performance tweaks, fixes to qr density for specter qr encode.
    [controller.py, encode_qr.py, seed_tools_view.py]
2021-08-05 3D print file update
    Reorg current pill files and add open pill files.
    [OP_Lower.f3d, OP_Lower.stl, OP_Upper.f3d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]
2021-08-05 minor tweaks and ui improvements for qr scan failures and exiting
    [controller.py, encode_qr.py, seed_tools_view.py]
2021-08-06 house cleaning, removed code no longer used with a few additional clean up tweaks
    [controller.py, menu_view.py, seed_tools_view.py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]
2021-08-06 add signing detection and alert if signing failed
    [controller.py]
2021-08-06 remove wallet and replace with settings class. Add persistence settings in backend
    [controller.py, menu_view.py]
2021-08-08 few tweaks and workflow improvements based on testing feedback. Also added reset/reset.
    [controller.py, menu_view.py, seed_tools_view.py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]
2021-08-09 fix show seed qr crash
    [seed_tools_view.py]
2021-08-15 more bugfixes
    * fewer redraws
    * bug on deleting single char passphrase
    * Correct Key 2 display "123" on init.
    [seed_tools_view.py]
2021-08-20 replace impact with anton
    [controller.py, seed_tools_view.py, signing_tools_view.py]
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2021-08-23 change wording for passphrase from add/update to change. this only applies when a slot has an existing passphrase.
2021-08-24 correction to derivation path
    single sig and multi sig were switched on accident
2021-08-25 - replace Right to main menu with Right to continue when saving seed in Scan QR - Correct accross to across - Change Reset wording to restart app instead of restart device
    [controller.py]
2021-08-28 Add info about GPIO pins
    Remember that GPIO pins might need to be soldered - most probably. Remind of solderless alternative
2021-09-03 Update README.md misspelling
    In Shopping List section of README.md,
    correct misspelling of "* Pi Zero-conpatible camera"
    and change to "* Pi Zero-compatible camera"
2021-09-03 fix to qr encode for seed wordlist
    [encode_qr.py]
2021-09-04 Randomise dice reset
    At present, the selected dice value resets to 5 after each input of a dice roll.
    To minimise the number of user inputs during seed generation via this method, the default value should randomly oscillate between 2 and 5. From the default 5 location, two inputs are required to reach 1/3 (but only one input to reach 4/6), whereas from a default 2 location two inputs are required to reach 4/6 (but only one to 1/3). By randomly selecting either 2/5 default with 50/50 probability for either selection, statistically the number of user inputs required will be minimised during the process of seed generation by dice rolls.
    This PR proposes a very simple method to randomly s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
    [seed_tools_view.py]
2021-09-04 Update Open Pill Design
    Changes to open pill enclosure design; slightly widened camera port on front and back sides, lowered resting point for LCD hat by 1 mm
    [open_pill.f3d, open_pill.stl]
2021-09-07 Updates test settings to match current Controller expectations; tab spacing changed to space chars
2021-09-13 update settings to remove script type since it’s only in the xpub flow
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2021-10-14 fix seed qr displayed consistantly both zoomed and not zoomed in
    [encode_qr.py, seed_tools_view.py]
2021-10-17 Further UI implementation; lots of improvements
    * A lot of standardization across every gui area.
    * Isolating `Screen` implementations under a new `screens` subdir under `gui`.
    * Initial implementation of ScanScreen and SeedValidScreen.
    * Added fingerprint generation to `Seed`.
    * Beginnings of `pending_seed` in `SeedStorage`.
    * `Button` component generalized for text, inline icon + text, large Home screen icon.
    * Fixed & improved `back_stack`.
    [controller.py, menu_view.py, view.py]
2021-10-19 correct default camera rotation back to 0 degrees
2021-10-24 interim commit
    * First use of `View` params being passed through the `Controller`.
    * `back_stack` bugfix.
    * Further progress into Export Xpub.
    [controller.py, view.py]
2021-10-25 Interim commit
    * Removed unnecessary custom Screens in favor of reusable `ButtonListScreen`.
    * Beginning to define more constants to avoid string hard-coding.
2021-11-08 Receive Address typo correction
    [controller.py]
2021-11-08 make last 13 address fixed length mono space font
    [signing_tools_view.py]
2021-11-08 fix long password run off display
    [controller.py, view.py]
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2021-11-19 Update manual install steps, & other minor changes
    Lots of changes, including instructions on using a back-dated version of Raspberry Pi OS, and additional steps during the manual build process to disable WiFi, Bluetooth, and other services. Minor ed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
2021-12-02 Settings now json; Xpub export flow skipping screens based on Settings
    [controller.py, view.py]
2021-12-05 Bug fixes; deeper config integration to alter flows, menus
    [encode_qr.py]
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2022-01-23 Further test suite fixes for Singleton complications
    [controller.py, view.py]
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2022-02-05 Change verification framework; threading improvements; loading screen
    * FormattedAddress accepts `max_lines` to limit display
2022-02-06 PSBT input logic; nicer loading screen; routing method improvements
    * Checking PSBT input fingerprints against seed fingerprint
    * `LoadingScreenThread` includes Bitcoin logo, explanatory display text
    * Some `Controller` bulletproofing
    * Convenience `components.load_image`
    * Still refining btc display on Amount Details
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2022-02-17 Fixes for completing psbt flow
    [controller.py, encode_qr.py]
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2022-02-18 bugfix; Finished routing to SigningError view
    [controller.py]
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2022-02-21 Power off sequence, ResetView
    [view.py]
2022-02-25 Minor bugfix, compatibility fix
    [camera.py]
2022-02-26 PSBT flow bugfixes for self-transfers
2022-03-01 Passphrase "BACK" button bugfix; initial Component positioning refactor
2022-03-02 Button now dynamically rendering screen_* positions; BACK from SeedValidView bugfix
    [controller.py, view.py]
2022-03-02 Left nav top btn flexibility; Discard Seed dialogue; PSBT w/self-xfer and change fixes
    [controller.py, view.py]
2022-03-06 Xpub export bugfix; Reset process improvements
    [view.py]
2022-03-07 Better alignment, rendering TextArea, IconTextLine from baseline
    * "Seed Valid" is now "Finalize Seed" flow.
    * "Seed Options" replaced with Icon-enabled TopNav fingerprint
    [controller.py, view.py]
2022-03-07 Bugfix entering psbt flow; misc minor fixes
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2022-03-09 Refactoring legacy code
    * New `hardware` subdir
    * Renamed `Buttons` to `HardwareButtons` to avoid confusion with gui `Button` class.
    * Eliminating most legacy files
    [ST7789.py, buttons.py, camera.py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]
2022-03-10 Tweaks to passphrase flow, settings; SeedWordsView now highlighting four words at a time
2022-03-14 Add passphrase BACK bugfix; reset + docs update; post-create seed routing
    [view.py]
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2022-03-15 UnhandledExceptionView; tweaks to psbt change addr verification failure
    [controller.py, view.py]
2022-03-15 Bugfix on CompactSeedQR disabled for 12-word seeds; restore opening splash screen
    [controller.py]
2022-03-17 Exception handling, display fixes; Seed Options "Backup" submenu; BackStack tweaks
    * BackStack as a simple class w/better debugging
    * BackStack won't push identical Destination
    * Warning screens are one-way (can't BACK into them)
    * Better Destination debugging output
    * Button right_icon
    * TextArea.allow_text_overflow, other auto-sizing improvements to avoid infinite recursion
    * Disable "Developer Options"
    * Cleaner Screensaver CTRL-C exit
    [controller.py]
2022-03-21 I/O Test; Keyboard screen improvements
    * `Keyboard` a bit more modernized
    * `TopNav` can now re-render just the back/power button
    * `ScanScreen` w/a `BaseThread` implementation; support for I/O test.
    * Manual seed word entry display modernization/big overhaul.
    * Custom derivation path UI modernization.
    * Passphrase entry UI modernization.
    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
2022-03-22 Single sig addr verification finalized w/nested segwit flow
    * I/O test bugfix
    * ResetView and PowerOffView updates to custom Screens.
    [view.py]
2022-03-22 Load multisig wallet descriptors
    * Various bugfixes
    [controller.py]
2022-03-22 Improved re-routing back into a main flow after a loading sub-flow
    * Integrates loading multisig wallet descriptor into PSBT change verification flow.
2022-03-24 Bugfixes for nested segwit multisig addr verification flows
    [controller.py]
2022-04-01 Test suite fixes; DonateView
    * Updated custom SeedSigner icon font pack
    * Removing debugging print statements
    * Default button handling for BaseTopNavScreen
    [controller.py]
2022-04-03 PSBT Overview rendering fix
    * Cancel from LoadMultisigWalletDescriptorView correctly resumes PSBT flow.
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2022-04-27 BIP85 - Added test_bip85.py - Updates to get_bip85_child_mnemonic - Updates to BIP-85 naming used - Modified the flow for BIP-85 Child to use one display per function - fix to BIP85 Index input wasn'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
2022-05-03 Add Simple Pill enclosure stl files
    [sp_button.stl, sp_dpad.stl, sp_lower.stl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]
2022-05-04 Increased size of camera board space in Simple Pill enclosure lower
    [sp_lower.stl]
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2022-05-26 Improved handling for the PSBTOverview loading screen spinner
    Fixes #188
    * Only runs the spinner when the psbt actually needs to be reparsed (returning to the PSBT Overview screen via BACK button doesn't need to reparse the psbt so the spinner is no longer displayed).
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2022-06-15 mnemonic_generation test case bug fix; additional test case.
2022-07-06 MicroSD menu
    - Added MicroSD menu in tools. We can see the slot status and umount the MicroSD.
    - SD card icon added
2022-07-21 Making seedsigner-os the special case
    For any other hostname we will use the default
2022-08-05 Fix slow animated qr in SeedSigner OS
    /dev/smh path does not exist in seedsigner OS. Using /tmp instead should work on both raspberry pi OS and SeedSiger OS.
2022-08-13 Switch GPIO numbering mode to board
    Change the code so that the RPI.GPIO module addressing is based on the physical board pin number rather than the internal SoC channel.
    Boosts compatibility with holder hardware and makes it easier to see which pins do what.
2022-08-16 pi zero 2W hangs in psbt overview screen with animation, adding small sleep allows button actions to be better captured
2022-08-20 Removing step that asks for user to select their coordinator during PSBT signing flow
2022-10-03 code review corrections, minus moving view to screen
    [controller.py, microsd.py, view.py]
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2022-12-01 Added SP protective case STLs
    [sp_protective_case_lower.stl, sp_protective_case_upper.stl]
2022-12-03 add os.sync to handle strange settings save edge case when settigns are not written to disk prior to removing the MicroSD
2022-12-03 fix ressart/poweroff functions for debian based os, broke when making changes for seedsigner-os
    [view.py]
2022-12-03 disable microsd detection prior to shutdown to prevent display of toast notification
    [view.py]
2022-12-04 correct reference to controller to stop microsd detection thread
    [view.py]
2022-12-11 Add sample images to PubKey verification section
    Clarifed shasum result about ignoring the warning about 4 improperly formatted lines
2022-12-12 Skip Seed selection when previously selected after PSBT Scan and remove PSBT Review
    [controller.py, view.py]
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2023-01-19 verbose print statements removed from reset_controller fixture.
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2023-02-03 Inserted instructions on MicroSD writing.
    1st draft of MicroSD.
    Thus far I am holding back on elaborating on the DD usage, until the commands are tested some more.
    I have/can insert screenshots of the Pi Imager/Etcher basic actions, but I am concerned its getting too long.
2023-02-11 Fix my mistake from pr #284
    I should not have deleted the code for resume flow from PSBT
    This addition back allows Scan of PSBT first, then scan/entry of seed, then directly to PSBT Review"
2023-02-12 fixes required "dupe-back-button" from explorer to seeds menu
2023-02-12 back-button flow avoids landing in "scan"
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2023-02-14 Add Printable .stl Files
    Added Open Pill Mini & Open Pill Mini w/ Coverplate
    [Buttons.stl, Lid.stl, Main_Chassis.stl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]
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2023-02-27 Titlecase corrections to prior commit
    Revert and correct some changes made in yesterday's commit of the url case.
    These now match the lowercase/titlecase of the various sites more accurately to what they use.
    The display URL's are/were not affected, hence users will still see the Title Case of SeedSigner.
2023-02-27 reorder download table and add tooltips
    Position-swap of pi0.img (Pi zero 1.3) and pi02w.img (Pi Zero TWO) in "Downloading the software" table. The Pi zero V1.3 hardware is the most prevalent Zero hardware currently, so it is now moved into the Top Left position.
    Added tooltips to all 6 image file download links, to display the hardware/filename its linked to. ie "Download the ...pi02w.img file"
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2023-03-06 Improved integration w/View.button_data options
    * Modifies Views to make button_data and its options available to external caller (FlowTests).
    * Adds button_data_selection for tighter integration with Views and better human-readability of FlowStep sequences.
    * Removes the unique recursive run() call in SettingsEntryUpdateSelectionView.
    [view.py]
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2023-04-14 Update README.md
    Line 73 seems to have a typo associating the 47 character capacity with the 29x29 qr size, when the reference table displays 47 as the limit for 25x25. This proposed change corrects the typo to show 25x25 in the text of line 73.
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2023-06-25 Fix the issue where clicking a button on the tips page may cause exiting from the QR code page.
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2023-07-07 local import of LoadScreenThread to avoid flow-test warnings
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2023-07-20 Correct camera rotation check in test_controller.py
    PR #395 broke this test. This PR is to fix the test_controller test
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2023-07-27 Add Rugged Pill Enclosure
    [RuggedPIll_Bottom_MMU.3mf, RuggedPillBottom_4SeedHammer.stl, RuggedPill_Bottom.stl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]
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2023-08-05 tentative fix to race condition in test suite
    [controller.py]
2023-08-05 flow test fix
2023-08-05 Test for scanning the wrong type of QR for the Address Explorer
    [view.py]
2023-08-05 test flow bugfix
2023-08-07 Fixes button_data bugs
2023-08-08 Fix flow for if seed is already selected. if self.seed_num was evaluating to False for seed_num = 0. if self.seed_num is not None correctly evaluates seed_num = 0 to True.
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2023-08-08 Bugfix; adds `View.set_redirect()` mechanism
    [view.py]
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2023-08-12 fix BACK routing w/test flows, per specific scenario
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2023-08-18 Bugfix & improvements when message signing is disabled
    [view.py]
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2023-10-30 new enclosure
    [Bottom.stl, ButtonsConnected.stl, Top.stl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]
2023-12-19 Revert "pass seed to EncodeQR instead of mnemonic and passphrase to simplify"
    This reverts commit 289b382720bfce4bcdf2374c691657bba7209b60.
    [encode_qr.py]
2023-12-24 export correct xpub version bytes for electrum seeds
    [encode_qr.py]
2024-01-08 Fixing exception when trying to sign message from an unsupported custom derivation
    [view.py]
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2024-01-31 Add missing flow-based test for bip39 passphrase entry
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2024-02-17 Fix Always Wiping Multisig Descriptor at Main Menu
    [controller.py]
2024-02-21 Revert "Fix Always Wiping Multisig Descriptor at Main Menu"
    This reverts commit df7e1cba148598a0b5584ef5c6890e4c7dacb50f.
    [controller.py]
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2024-03-03 Reverting encode_qr.py file move and name change
    [encode_qr.py]
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2024-04-09 New enclosure "push case"
    [Bottom - Push Case - SeedSigner.3mf, Bottom - Push Case - SeedSigner.stl, Button - Push Case - SeedSigner.stl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]
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2024-05-16 Add Python 3.12 to test matrix as upper bound and fix findings
    This is done in advance to open the door for upgrading to newer Python
    versions on seeedsigner-os at any time.
    Fixes / required changes:
    * Fix `E ValueError: mutable default <class 'seedsigner.views.view.Destination'> for field next_destination is not allowed: use default_factory`
    * Install package during CI with pip instead of calling the setup.py (which
    got deprecated a while a ago and breaks with Python 3.11/3.12)
    * Update Pillow version to 10.0.1 = first version with Python 3.12 support
    [view.py]
2024-05-21 Camera cut-out slightly enlarged
    [Bottom - Push Case - SeedSigner.3mf, Bottom - Push Case - SeedSigner.stl]
2024-05-21 Models rendered in intended print orientation
    [Button - Push Case - SeedSigner.stl, Middle - Push Case - SeedSigner.stl, Thumbstick - Push Case - SeedSigner.stl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]
2024-06-21 pass sig_type to BaseXpubQrEncoder so that it can get correct version
    [encode_qr.py]
2024-06-30 Add exit dialog when entering passphrase
    * Issue #510 'Behavior of back button confusing when entering password'
    * Updated test suite accordingly
    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
2024-07-10 Fix Multisix Xpub Export not working correctly for P2PKH Legacy Wallets
    [encode_qr.py]
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2024-08-07 Light copy edits to the "lookScrews!" enclosure docs
    [Bottom.stl, ButtonsConnected.stl, Top.stl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]
